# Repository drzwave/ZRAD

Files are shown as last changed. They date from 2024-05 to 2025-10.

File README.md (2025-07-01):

# ZRAD - Z-Wave Reference Application Design

Z-Wave USB Controller with best-in-class RF range Reference Application Design

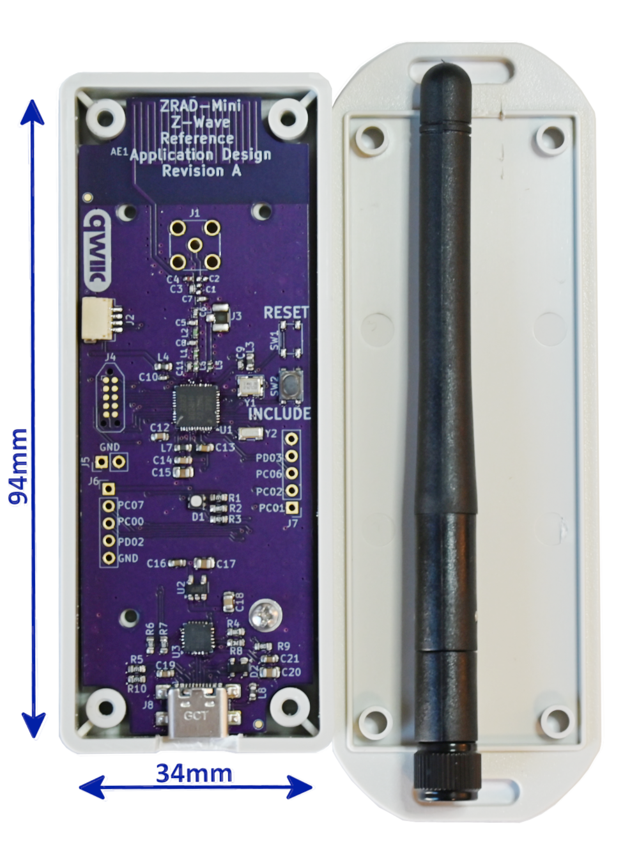
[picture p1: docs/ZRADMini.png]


The Z-Wave Alliance Z-Wave Reference Application Design (ZRAD) is a simple to copy, easy to modify, Open-Source _Reference_ design of a Z-Wave best-in-class RF range device. 
ZRAD is not a product you can purchase, but anyone is welcome to manufacture and sell a product based on ZRAD. 
The objective is to accelerate Time-To-Market for Z-Wave products thru a simple to follow example with detailed step-by-step instructions.  
See the [docs/ZRADTechDocs.docx](docs/ZRADTechDocs.docx) file for more details and the Theory of Operation.

# Setup - Simplicity Studio SSDK 2024.12.0 (Z-Wave 7.23.0)

This setup guide assumes a ZRAD or ZRADmini board has been assembled and is ready for programming.
ZRAD can be programmed as either a Controller or an End Device.
The challenge with Simplicity Studio (SSv5) is that since this is a "custom" board, many of the automatic features of SSv5 do not work.
Many aspects of the sample applications must be manually configured.

## Connect ZRAD to Simplicity Studio

1. Plug ZRAD into a WSTK via the Tag-Connect cable
    - ZRAD can be powered directly from the WSTK - ensure the slide switch next to the battery holder is set to AEM
    - Use a Tag-Connect [TC2050-CLIP](https://www.tag-connect.com/product/tc2050-clip-3pack-retaining-clip) retaining clip to hold the Tag-Connect securely to ZRAD
2. Plug the WSTK into a computer running Simplicity Studio
3. The WSTK should show up in the Debug Adapters pane of the Launcher Perspective
    - if not, click on detect target, if that still doesn't work, use Commander to identify the part
    - if that still doesn't work, check that the WSTK is set to OUT (or Mini) mode
4. Select the WSTK in the debug adapters pane 
    - SSv5 will then list the board as "custom" and Target Part as the ZG23
5. Your ZRAD board can now be programmed with firmware

## Controller

1. Download the SerialAPI using SSv5
    - The standard Demo SerialAPI pre-built for the RB4210 Radio Board will work for ZRAD as the pinouts are similar
        - Select xG23-RB4210A in the My Products pane of the Launcher perspective in SSv5
        - Click on Example Products & Demos Tab
        - Click on Z-Wave
        - Scroll down the list to the Z-Wave - NCP Serial API Controller (US or EU LR) 
        - Click on Run, select the WSTK and SSv5 will program the DUT
        - Note: the pre-built SerialAPI assumes a ZG23B, not ZG23A thus only download to a ZG23B
    - The Demo SerialAPI includes the bootloader
2. OR Build the SerialAPI (required if using a ZG23A or using your own keys)
    - TODO More details to come here...
    - TODO add how to build the serialAPI and add special features - what needs to be done to OTW??? keys???
3. Build the bootloader if also building the SerialAPI 
    - See [DrZWave.Blog](https://drzwave.blog/2024/04/02/how-to-build-the-z-wave-bootloaders) for details

## End Device

### Quick Demo 

The Switch On Off sample application in SSv5 will run out-of-the box on ZRAD as the pinouts are similar to the RB4210 devkit.
Follow these instructions to quickly test a new board.

1. In SSv5, in the Launcher perspective, enter "xG23-RB4210" in the lower left My Products pane, select that kit
2. Click on the Example Projects and Demos tab
3. Click on Z-Wave and uncheck Example Projects and Solution Examples
4. Click on RUN for the desired Demo application, Z-Wave SoC Switch On/Off (US or EU Region) has been tested
5. Choose the WSTK with ZRAD connected and click OK
6. The hex file will download and run. A bootloader is included in the sample application.
7. Right click on the WSTK in Debug Adapters
8. Device Configuration\-\>Z-Wave Device Settings will bring up the QR code and DSK
9. Use the QR code to join a network and write down the first 5 digits of the DSK which is the PIN
    - Press the LEARN button to send a NIF
11. Connect via the Console for other CLI functions (type "help" for a list of commands)
12. The LED will come on because the pins and polarity on ZRAD are different than the RB4210

### Full Feature Build

1. **Build the Bootloader**
    - In SSv5, select your board connected to a WSTK to make sure you are building for the proper chip
    - Click on Detect Target Part and verify the proper Target Part has been detected
    - File-\>New-\>Silicon Labs Project Wizard -\> next (make sure the IDE/Toolchain is V12.x.x or higher)
    - Filter on Z-Wave
    - Select "Bootloader - SoC Internal Storage (OTA for Z-Wave Applications)" - select it, click on Next and then Finish
    - Build & Flash the binary to the device
    - Copy the .HEX or .s37 file to another folder for merging with the app and keys later
    - Note that the Application will NOT start unless there is a bootloader programmed into the DUT
2. **Build the App**
3. Start with the Switch On/Off sample app - optionally use one of the others if applicable
4. File-\>New-\>Silicon Labs Project Wizard
5. Check that IDE/Toochain is set to GNU ARM v12.2.x (and not v10.x.x)
6. Check that the SDK is the latest
7. Next
8. Unselect Solution Examples
9. Select the Z-Wave checkbox
10. Select the Z-Wave SoC Switch On/Off project
11. Next
12. Change the project name to whatever you want
13. Finish - wait for the project to be created
14. **Generate the Keys**
    - Keys are needed to OTA the firmware - do NOT use the sample keys!
        - Keys are unique for each project for ALL revisions. Only generate the keys ONCE per project.
    - Create a folder called "keys" in the project
    - From the keys folder, run Commander:
        - ```commander gbl keygen --type ecc-p256 -o <projectname>_sign.key```
        - ```commander gbl keygen --type aes-ccm  -o <projectname>_encrypt.key```
    - Each unit must have the keys programmed in them using:
        - ```commander flash --tokengroup znet --tokenfile <projectname>_encrypt.key --tokenfile <projectname>_sign.key-tokens.txt --device EFR32ZG23```
        - Or combine the keys, bootloader and app into 1 file:
        - ```commander convert --tokengroup znet --tokenfile <projectname>_encrypt.key --tokenfile <projectname>_sign.key-tokens.txt <bootloaderfilename> <applicationfilename> -o <projectname>_merged.s37 --device EFR32ZG23```
    - Modify the Post Build Editor in SSv5 to use these new keys when creating the OTA file
        - Double click the \*.slpb file which will open the Post Build Editor
        - click on the create_gbl parameter
        - Click on the BROWSE button of the Signing Key, select the *_sign.key from above, then the Encrypt Key and select the *_encrypt.key file

        - To check the keys and Post Build is good, run:
        - ```commander gbl parse *.gbl --decrypt ../keys/<projectname>_encrypt.key --app temp.hex```
            - Should complete without error and copy the application to the temp.hex file
        - To check the keys work, program a unit with the app, keys and bootloader, then increment the version, build it again and OTA the incremented version
14. **Customize the Application**
15. Select the project in the Project Explorer of the Simplicity IDE perspective
16. Select the \*.slcp file
17. Select the Software Components tab
18. Scroll down to Z-Wave and open it (click on the triangle)
19. Click on Z-Wave Core Component gear icon
20. Change the RF Region to the desired value (ex:United States Long Range)
21. Click on the Z-Wave ZAF Component
    - Update the User Icon Type and Installer Icon Type for the specific product
        - See the Z-Wave Plus Assigned Icon Types document in the Z-Wave Alliance specification for details on choosing the proper icons
    - Update the Hardware version, Manufacturer ID, Product Type ID and Product ID
        - Each manufacturer is assigned an Manufacturer ID by the Z-Wave Alliance - search the ZW_classcmd.h for your company name
        - The ProductTypeID and ProductID are each 16 bits and MUST BE UNIQUE for each product within your company. These are the "fingerprint" that uniquely identifes the product. They must NOT change for the lifetime of the project thru all firmware revisions.
    - Update the device type & Multichannel configuration
    - Uncheck the Request S0 Network Key and S2 Unauthenticated network Key (these are obsolete and a security hazard)
    - Check the S2 Access Network Key if the product is a doorlock, garage door opener or other secure entry device
7. Click on Z-Wave Verion Numbers
    - Check the Override application version (TRUE=turns blue)
    - Enter the Application Major and Minor version. Note that the Minor and/or Major version MUST be incremented to OTA the firmware
7. Configure Buttons and LEDs:
    - The project will not build yet because LEDs/buttons are not setup for the sample application
    - Search for "simple" in the Software Components tab of the *.slcp file
    - Click on Platform-\>Driver-\>Button-\>Simple Button-\>btno0-\>Configure
        - General - Interrupt
        - SL_SIMPLE_BUTTON_BTN0 select PC03 and name it TOGGLE
    - Click on Platform-\>Driver-\>Button-\>Simple Button-\>btno1-\>Configure
        - General - Interrupt
        - SL_SIMPLE_BUTTON_BTN1 select PC05 and name it LEARN
    - Click on Platform-\>Driver-\>LED-\>Simple LED-\>led0-\>Configure
        - Active Low
        - SL_SIMPLE_LED_LED0 = PA00 and label it GREEN
    - Click on Platform-\>Driver-\>LED-\>Simple LED-\>led1-\>Configure
        - Active Low
        - SL_SIMPLE_LED_LED1 = PA10 and label it BLUE
    - TODO add LED2 PC04=RED
6. Build the project - it should build OK
    - Flash the DUT
    - Get the QR code or DSK and paste into the PC Controller
    - The DUT should join the Z-Wave network in a few seconds.
    - Send a BASIC ON and the BLUE LED should turn on
    - Send an Indicator SET which should blink the GREEN LED
    - Press the LEARN button which should send a NIF and the GREEN LED should blink
6. Optionally enable debugprint to get messages out the UART for debugging purposes
    - click on Z-Wave Debug Print
    - click on Install
    - SSv5 should also instal the IO Stream USART but sometimes it does not
        - manually install Services-\>IO Stream-\>IO Stream USART
        - Click on configure
        - Choose USART0, Tx=PA08, RX=PA09
        - Build the project
        - If the build fails because USART is undefined, click on Configure in IO Stream USART
        - Click on View Source
            - if #warning "IO Stream USART peripheral is not configured" is at about line 90, then SSv5 didn't properly configure the USART
            - comment out the #warning line, then manually set the next several lines with the proper GPIO vlues (they are pretty obvious).
    - Edit app.c and uncomment the line: #define DEBUGPRINT
9. Note that the Secure Element firmware version MUST be the same as the SDK version the app and bootloader were built with. Ensure you have the proper version when programming production devices.
10. TODO
    - What other stuff should every project update???
    - Default_handler - could write an entire blog post on what it should include
    - 24hr watchdog timer - reboot if no traffic
    - watchdog timer
    - memset/clr optimization?
    - Turn on the iCache?
    - add other command classes
    - SPI?
    - Red LED

## Zniffer

ZRADMini makes a great Zniffer for debugging Z-Wave networking issues. 

1. Connect ZRADMini to a WSTK using the Tag-Connect connector
2. Open Simplicity Studio
3. From the Launcher perspective, in the My Products tab, enter the xG23-RB4210A
    - The RB4210A is a +20dBm devkit using a ZG23B and is pinout compatible with ZRADmini
    - Much easier to simply download the pre-built Zniffer application than trying to configure it for ZRAD
4. Click on the Example Projects tab and select Z-Wave
5. Filter on "zniffer" and choose only Demos
6. Pick the desired Z-Wave - NCP Zniffer Beta (EU\_LR or US\_LR regions) and click on RUN
7. Choose the proper WSTK to program the ZRADMini
8. Unplug from the WSTK and plug into USB
9. Zniffer should detect ZRADMini as a zniffer

# Troubleshooting

- Firmware doesn't seem to start? Did you flash the bootloader? The app won't start without a bootloader.
- If your ZRAD is not able to be detected using SSv5 or commander:
    - Check the ZG23 for solder shorts/opens and check the power supplies
    - Is the WSTK in Out or Mini mode and the slide switch set to AEM?
    - Can Commander detect the part? Simplicity Studio sometimes is unable to detect the part but Commander can and will help debug the issue
    - Is the debug interface locked? Use Commander to Unlock Debug Access or Recover Bricked Device
- If the DUT does not seem to generate any RF traffic, the problem is often due to the wrong Region stored in NVM (IE: EU when you want USLR).
    - To reset the Region token: ```commander flash --tokengroup znet --token MFG_ZWAVE_COUNTRY_FREQ:0xFF -d EFR32ZG23```
    - Note: the token in NVM will override the value set in the firmware so downloading firmware may not fix the problem
- OTA fails with a 0x04 error (someday Silabs will eventually separate this out into more errors)
    - Usually caused by the keys not being programmed into the DUT

# QWIIC Connector Setup

The QWIIC connector on ZRAD makes it easy to connect any of the [Sparkfun](https://www.sparkfun.com/qwiic) sensors or other devices via a standard I2C interface. 
Fortunately SSv5 has the I2CSPM component which makes adding and interfacing to I2C devices fairly easy.
The QWIIC connector is normally only used when implementing ZRAD as an End Device.

## I2CSPM Setup

While I2CSPM seems to work, since it is a polled peripheral which loads the CPU with polling loops which can make other parts of the system fail. Thus, this driver is not recommended but works fine for prototypes.

1. Click on the .slcp file - select the Software Components tab - enter I2CSPM into the seach bar
2. Click on Platform-\>Driver-\>I2C-\>I2CSPM and Install it
3. Name the component QWIIC
4. Click on Configure
5. Reference clock frequency=0 (default), Speed mode=Fast mode (400kbit/s), Selected Module=I2C0 (or I2C1), SCL=PB00, SDA=PB02
    - Sometimes SSv5 does not properly configure the GPIOs - click on Source
    - Comment out the #warning
    - Uncomment the QWIIC\_PERIPHERAL to be I2C0 (or I2C1)
    - Uncomment the PORT and PIN lines and set them to the correct GPIOs for both SCL and SDA
6. The project should build OK - the I2C peripheral will be automatically initialized
7. The I2CSPM\_Transfer() function is then used to send/receive data over the I2C bus
8. See the Geographic Location Command Class repo for an example using the QWIIC connector

# Railtest

RailTest is required for calibrating the 39MHz crystal on the ZRAD PCB. 
The Z-Wave radio will work fine without calibrating the crystal but MUST be calibrated before measuring the RF range.
The crystal on each ZRAD unit must be individually calibrated within 1ppm to achieve maximum RF range over the lifetime of the board.

## Build Railtest

1. The easiest method is to select a ZG23 Radio board DevKit in the MyProducts in the Launcher persepctive
    - ZRAD uses the same UART IOs as the devkits thus the simple method to build railtest is to use one
    - In the "Enter product name" box, enter "RB4210"
2. In the Example Projects & Demos tab, enter "railtest" in the "Filter on Keywords" box
2. Select the "RAIL - SoC Railtest" project
3. Click on Create
4. Build the project
5. Download the .s37 file to the target
6. Connect via USB using PuTTY, Minicom or other terminal project at 115200 baud
7. Type "help" and the full railtest menu should print out
8. Type "getversion" to see the current version of Rail

# Crystal Calibration

1.	Download RailTest into the DUT
2.	Rx 0
3.	Setzwavemode 1 3
4.	Setzwaveregion 1
5.	Setchannel 2
6.	Settxtone 1 - turns on the radio carrier
7.	Getctune - record the CTUNEXIANA value in hex
8.	Use a spectrum analyzer like the TinySA Ultra with start=908.3 stop=908.6
9.	Measure the peak which the TinySA should display - goal is to be within 1ppm of 908.420MHz (1000Hz)
10.	If the peak is high, set ctune to be a higher value, if low, try a lower value
11.	Settxtone 0
12.	Rx 0
13.	Setctune 0xTTT
14.	Settxtone 1
15.	Measure the peak - go back to step 11 until within 1000Hz (1ppm)

Once the value has been determined, use the following command to program the value:

```commander ctune set --value <ctunevalue> -d EFR32ZG23```

```commander ctune get -d EFR32ZG23``` will return the three ctune values. The "Token" ctune is on-chip one in NVM which is erased if the User Data Page is erased. The DI value is programmed at the Silabs factory in the Data Information page for modules. The Board value is used for Silabs radio boards and thus not applicable for customer boards. 

Note that railtest does NOT program the value in NVM. Railtest will only TEMPORARILY assign the CTUNE value. Commander must be used to program the value permanently.

# Schematic to PCB process

KiCAD is used for the schematic and PCB design. The hardware/ZRAD directory contains the KiCAD database. A PDF of the schematic and PCB are provided for easy review. The Gerbers (used for fabricating PCBs) are in a ZIP file in the gerbers folder. The process to go from the schematic to a fabricated PCB is listed here:

1. Open the Schematic file (ZRAD.kicad_sch) in KiCAD
2. Make any changes to the schematic as desired and run the Electrical Rules Check
3. Save the schematic file - File-\>save
4. File-\>Export-\>netlist - click on Export Netlist and save file to ZRAD&#46;NET
5. Open the Board file (ZRAD.kicad_pcb)
6. Update the board from the schematic - Tools-\>Update PCB from Schematic - click on Update PCB
7. Make any changes to the PCB desired
8. Inspect-\>Design Rules Checker - Click on Run DRC
9. Make sure DRC is clean!
10. Generate the Gerbers and documentation files:
11. File-\>Fabrication Outputs-\>Gerbers - click on PLOT, then Generate Drill Files 
    - All the selected layers will be saved in the chosen folder
12. File-\>Fabrication Outputs-\>Component Placement - click on Generate Position File
13. Delete the ZRAD-bottom.pos file as there are no bottom side components
14. There should be a total of 10 files (12 for a 4 layer board) - add these to a compressed ZIP file and name it ZRAD.zip
15. Delete the gerber files and just keep the ZIP file
16. Review the gerbers using one of the many gerber viewer programs 
    - Check that there is solder mask between the pins of the ZG23 and CP2102
    - if not, check the Board Setup-\>Board Stackup-\>Solder Make/Paste-\>Solder mask expansion is set to 0.0508mm (not zero)
    - Note that 0 leaves it up to the PCB manufacturer who often will use a 3mm expansion which will results in all the pads being shorted to each other as there is no mask between the pads 
17. Plot the schematic - File-\>Plot plot to PDF and save as ZRAD.pdf
18. Print the Fab drawing from the board editor - File-\>Print save landscape fit-to-page as ZRAD_FabricationDwg.pdf
    - Select layers F.Silkscreen, F.Mask, User.Comments, Edge.Cuts and print in black and white
19. Order PCBS!
    - OSHPark.com is recommended - Use the gerbers and NOT the KiCAD files as the gerbers will give you exactly what is plotted, the PCB house may use other defaults for various clearances which might cause problems
    - May 2024 cost $233 for 3 4-layer ZRAD boards
    - July 2025 cost $24.75 for 3 2-layer ZRADTri boards
20. Order a Stencil using the ZRAD-F_Paste.gtp file

Order components from the BOM for the needed quantity. Once everything arrives, use the stencil to swipe a layer of solder paste onto the PCBs, place the components by hand, then bake in an IR oven, clean up any solder issues. PCBs are now ready to test!

# Directory Structure

- 3D - mechanical drawings for jigs and enclosures
- docs - documentation folder
    - Datasheet
    - Technical reference manual and theory of operation
- hardware - PCB board design, bill of materials, Gerbers, KiCAD schematic and layout
- sofware - various hex files for quick testing purposes
- Test - Documents and scripts for testing

# Reference Documents

- See the [docs/ZRADTechDocs.docx](docs/ZRADTechDocs.docx) for detailed technical information on this project
- [EFR32ZG23](https://www.silabs.com/documents/public/data-sheets/efr32zg23-datasheet.pdf) Datasheet - features and electrical specification
- [EFR32xG23](https://www.silabs.com/documents/public/reference-manuals/efr32xg23-rm.pdf) Reference Manual - peripherals details

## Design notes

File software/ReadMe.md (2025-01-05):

# ZRAD Software folder

See the top level ReadMe.md for step by step instructions on building firmware for ZRAD.

The Application must be named ZRAD\_ED.s37 for the Test scripts to function properly.
The sample manufacturing flow in the ../Test folder uses the files in this folder to program into each DUT

# KEYS - MAKE YOUR OWN!

Over-The-Air (OTA) firmware updates REQUIRE keys to be programmed into each DUT and MUST be used when building the firmware and generating the gbl file.

The keys pre-built in this folder are SAMPLE KEYS and MUST NOT BE USED on derivative projects! You MUST create your own unique keys for your own products!

## Generating Keys:

1. Run the following commander commands:
2. `commander gbl keygen --type ecc-p256 -o ZRAD_sign.key`
2. `commander gbl keygen --type aes-ccm  -o ZRAD_encrypt.key`

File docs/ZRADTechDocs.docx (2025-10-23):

# ZRAD Z-Wave Reference Application Design

# Introduction

The Z-Wave Alliance Z-Wave Reference Application Design (ZRAD) is a simple to copy, easy to modify, Open-Source Reference design of a Z-Wave best-in-class RF range device. ZRAD is not a product you can purchase, but anyone is welcome to manufacture and sell a product based on ZRAD. The objective is to accelerate Time-To-Market for Z-Wave products thru a simple to follow example with detailed step-by-step instructions.

See the README.md (https://github.com/drzwave/ZRAD/blob/main/README.md) file in the repo for the latest information on building and using ZRAD.

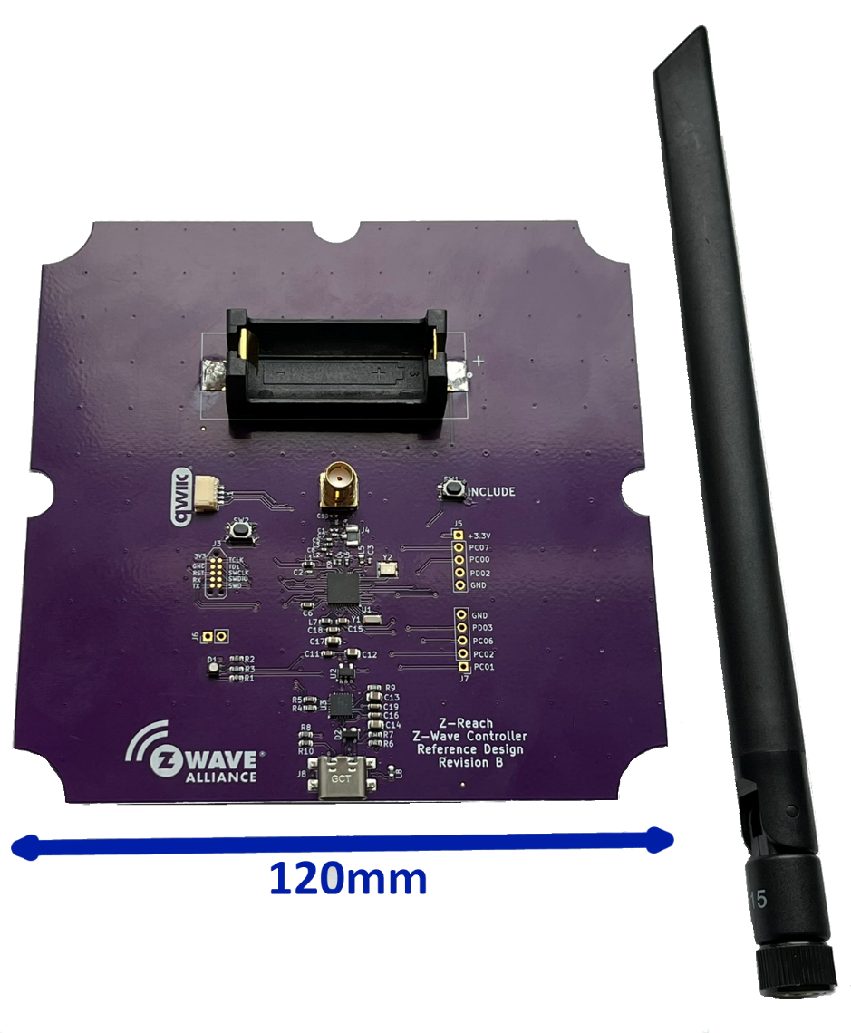
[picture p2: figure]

## Features

- Public GitHub repository
  - Open-Source Repository
  - MIT License
- KiCAD schematic & PCB layout
  - Easily imported into other tools like Altium
  - Gerbers for immediate production
- EFR32ZG23 based +20dBm
  - 512K FLASH, 64K RAM
  - ARM CM33 CPU 39MHz
  - UARTs, Timers, I2C, ADC, DAC
- CP2102N USB->UART host interface
- Standard SerialAPI Firmware
- Documentation with full details for customization and replication
- Battery powered End Device option
- Target Assembled/tested kit cost less than $50@10K (not including enclosure)
- Target BOM cost under $15@10K
- White Paper on Z-Wave Antenna Best Practices and RF range field test results

# Theory of Operation

## Z-Wave MCU

Naturally the heart of ZRAD is the Silicon Labs EFR32ZG23 SoC. The ZG23 has an ARM CM33 CPU, a long list of standard peripherals and the Z-Wave radio. The ZGM230 module is limited to +14dBm (or half the RF range) compared to the SoC at +20dBm. The SoC requires tuning the 39MHz crystal on every unit produced but this is easily done in a few seconds on the production line. The procedure for tuning is described below and scripts are available in the Repo.

The UART Rx/Tx pins are connected to the CP2102 thru 100 ohm resistors to allow the Tag-Connect debug cable to drive the pins during manufacturing. RailTest is needed to send/receive UART commands during crystal calibration. While this does not provide complete isolation between the CP2102 and the debug connector, the debug connector is typically only connected for a few seconds during final test making this a viable low-cost solution.

A Tag-Connect 10 pin header with alignment pins is used for programming and test during production and debug. Two Trace pins are wired to the header to enable Trace debugging using the adaptor board in the etm_zwave (https://github.com/drzwave/etm_zwave) repo. The PTI pins are not wired as Z-Wave typically uses a separate standalone Zniffer. The 2 ground pins are often needed for Trace debugging to improve signal integrity across the 10 pin ribbon cable.

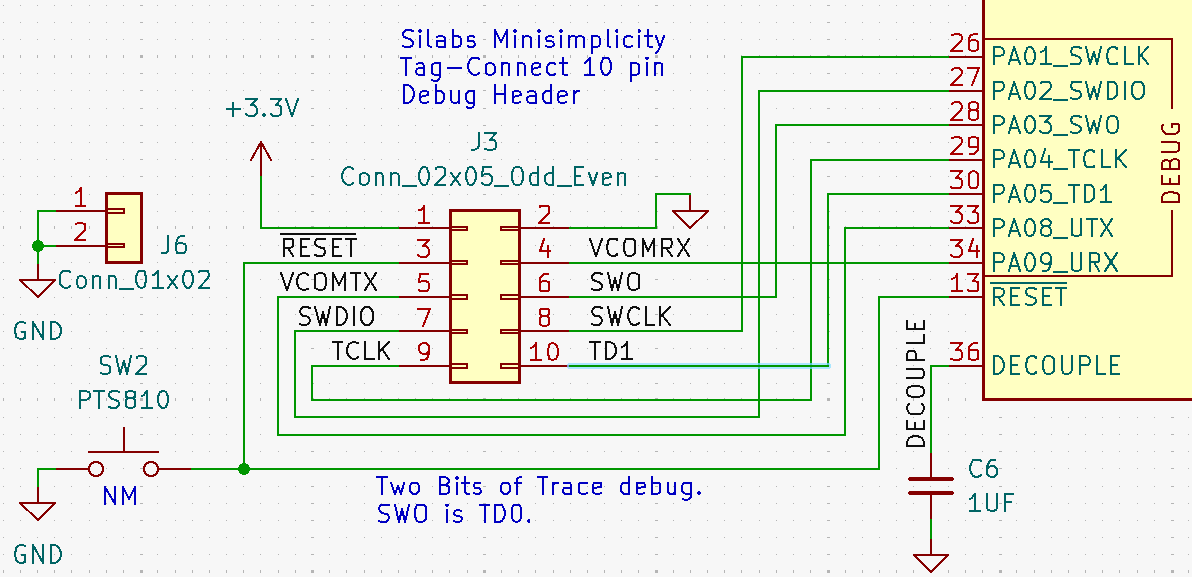
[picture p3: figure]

The ZG23 DCDC switching power supply is utilized to convert the 3.3V to 1.8V for the VDD power supply. The USB 5.0VDC is passed thru a linear LDO to drop the supply voltage to 3.3V. Power spikes of about 130mA occur when the radio transmits at +20dBm. The LDO and USB handle that sudden change in supply current ensuring good RF range. The PAVDD is powered with 3.3V to power the RF amplifier to +20dBm. The analog supply and IOVDD are on the 3.3V to provide better analog voltage range and connectivity with other external devices. The internals of the ZG23 are powered with 1.8V. Sensitive power supplies have additional ferrite beads and capacitors to ensure clean supply voltages.

## Antenna Filter and Match

The RF path from the ZG23 to the RF50 signal is straight from the Silabs DevKit reference designs (xG23-RB4210A (https://www.silabs.com/documents/public/user-guides/ug507-brd4210a-user-guide.pdf)). This path filters the RF and shifts the high impedance pins to be close to 50 ohms. Between the matching circuit and the SMA connector is a standard 3 element pi filter used to match the impedance of the antenna. The values for these 3 elements are typically tuned to a specific antenna and RF region. A U.FL footprint is in this path to make tuning easier via a U.FL cable to a network analyzer. The U.FL is only mounted to bare PCBs to help with tuning. Thus, it is listed as “NM” in the schematic and is why there is a red X thru it. The SubGx1 pins are not used. The PCB antenna used on ZRADMini was inspired from the EFR32ZG14 Radio board BRD4206A (https://www.silabs.com/documents/public/reference-manuals/brd4206a-rm.pdf). However, the shape was altered to fit the available space.

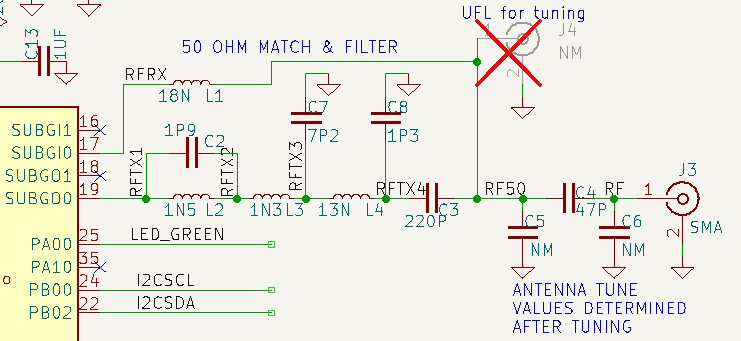
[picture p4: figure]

## USB-C Interface

A Silicon Labs CP2102N USB to UART chip is used to connect the SerialAPI to the host computer. A USB-C connector is used but only USB 2.0 is supported. USB3 is not supported or needed as the data rate of the UART is 115200 baud. The design follows the reference example in the CP2012 datasheet. This article (https://hackaday.com/2023/08/07/all-about-usb-c-example-circuits/) was used as a guide. A CP2105 dual UART is pinout compatible and might be used in a future release to include support for Zniffer via PTI. Pin 12 of the CP2105 is wired to the PD04 pin of the ZG23 which can be used for 9-bit data mode of the PTI component.

## Power Supplies

USB-C provides +5V power in the typical application of a controller. The +5V is reduced to 3.3V via an LDO to power the on-chip switching regulator on the ZG23. The radio is powered from +3.3V to achieve a transmit power of +20dBm to the PAVDD pin.

When prototyping a low-power end device, the battery holder can be populated and connected to a CR123A or similar 3V battery. No reverse battery protection is provided so the battery holder must ensure the polarization. The LDO and USB devices are not populated when developing a battery powered device.

## PCB Ground Plane

A very important part of an IoT radio is the ground plane. Ideally the ground plane is perpendicular to the antenna and is half-wavelength. At 868MHz the wavelength is 34.5cm and 920Mhz is 32.6cm. The exact dimension isn’t that critical as long as it’s close. The ½ wavelength is 17cm but a square is more cost effective than a disk, thus divide by the diagonal (1.41) to get a 12cm on a side or roughly 5” square PCB. The ground plane fills the entire bottom side of the PCB to ensure there are no eddy currents or blockages. The next layer is used to distribute power. The upper two layers are used for interconnection of the ICs. All layers are flood-filled with ground as much of the area is open to provide a large ground plane for ideal RF performance. A smaller PCB size can be easily prototyped by simply making the PCB smaller with the potential of a loss in RF performance.

A related calculation is the width of the infeed trace. The width of the infeed trace is calculated using one of the many coplanar waveguide calculators such as: https://chemandy.com/calculators/coplanar-waveguide-with-ground-calculator.htm.

For OSHPark (https://docs.oshpark.com/services/four-layer/), the relative dielectric constant is 3.61. The thickness of the prepreg is .2021mm. Usually the gap is set to .3mm then try various widths until the calculator comes up with close to 50 ohms. For ZRAD using OSHPark for PCBs, the calculated width is .44mm. Most of the infeed trace is 0.44mm except where it needs to narrow to reach the pins of the ZG23.

## RGB Color LED

An RGB Color LED can be used to provide visual status of any sort. Utilizing this LED requires customizing the SerialAPI. The LED can be used when ZRAD is used as an end-device for Indicator CC support. The LED is Active Low meaning the LED is ON when the pin is a zero (0V). The LEDs are driven directly from the GPIOs without extra FETs to keep costs low. This limits the brightness of the LEDs but they are sufficiently bright for most applications.

- Red = PC04 (LED3_GPIO)
- Green = PA00 (LED1_GPIO)
- Blue = PA10 (LED2_GPIO)

The pins can be assigned using the Z-Wave Target Boards component in Simplicity Studio. Open the .SLCP file and select the Software Components tab. Scroll down to the Z-Wave Target Boards component and click on the gear icon. Assign the pin as shown above. The standard Switch On Off sample app will then control the green LED as the state of the switch and the blue LED will blink when in Learn mode or via Indicator CC. If SSv5 is not properly setting the configuration, see the README.MD file for the latest workaround.

## Learn Mode Switch

PC05 is connected to a SPST momentary pushbutton switch. This pin is an EM4WU pin so it can wake the chip from EM4. End Devices use this pin to enter Classic Inclusion/exclusion mode. Press and hold for more than 5 seconds to factory reset ZRAD. Controller applications do not populate this switch.

## I2C via QWIIC connector

Tons of handy and cheap I2C devices from Sparkfun use the tiny 4 pin QWIIC connector. There are sensors of every type, various displays, and GPS receivers. To add I2C to the ZRAD, install the Platform->Driver->I2C->I2CSPM component. Configure it with: Leave the Reference clock frequency at 0, Speed Mode=Fast Mode (400kbits/s), Selected Module=I2C0 (or I2C1), SCL=PB00, SDA=PB02. Reference clock frequency of 0 sets the reference frequency to the same as the I2C peripheral clock which is usually the HF clock (39MHz) (based on following the code). Once configured, the pins should show up in the PinTool. sl_system_init() calls sl_driver_init() calls sl_i2cspm_init_instances() which then configures the I2C block on startup. The only function is the I2CSPM_Transfer (https://docs.silabs.com/mcu/5.9/efr32mg13/group-I2CSPM)(). The Z-Wave Multilevel Sensor sample app uses the I2CSPM which can be used as an example to see how it works.

## DEBUGPRINT

DEBUGPRINT can be defined and used to print messages via the MiniSimplicity headers VCOM pins. Typically, the USART is used for this purpose. First install the Services->IO Stream: USART component. Configure for 115200 baud, USART0, RTS/CTS=none, Rx=PA09, Tx=PA08. Then install Z-Wave-> Debug Print and uncomment the #define DEBUGPRINT in app.c or as a compiler symbol which will enable all printfs in every file.

## Optional Connections

Extra connections are incorporated in the design to allow prototyping of many other types of Z-Wave devices. These connectors and devices are normally NOT mounted for SerialAPI applications.

- 32KHz crystal supports Time CC. The on-chip low-speed oscillator drifts by a few minutes per day making it not usable for schedules or other time-of-day uses. The crystal reduces drift to a few seconds per day.
- Two 5 pin GPIO headers provide generic connections to other devices
- SW2 is an optional switch connected to RESET which is handy when debugging End Devices

## Crystal Calibration

See the README.md file and scroll down to the Crystal Calibration section for the procedure to calibrate the 39MHz crystal. Calibration is unique to each unit and must be performed during final test. Calibration is required for maximum RF range across environmental conditions and aging.

# Programming and Testing

The Test folder has Python scripts for programming, calibrating, and testing ZRADMini using the jig in the 3D folder, a Silabs WSTK ProKit, TinySA spectrum analyzer and a PC or raspberry pi. See the Test/ReadMe.md file for more details.

# Fabrication

ZRAD is a reference design and not a commercial product though it is intended to be copied and possibly sold as one. The procedure below documents the process to build prototype quantities. This is an example process and each manufacturer may have slightly different requirements. The process below is for ZRADmini. Open KiCAD and ensure the schematic is ERC clean and the PCB is DRC clean. ZRADmini has a few Exclusions to the ERC/DRC which can be ignored.

## PCB Files – Gerber Generation from KiCAD

1. Open the Schematic and PCB in KiCAD (version 8.0.4 or later)
2. Print the Schematic as a PDF and save as ZRADminiSchematic.pdf
3. Make ONLY the following layers visible: F.Silkscreen, User.Comments (contains all the PCB fabrication details), Edge.Cuts, F.Paste
  a. Turn off VIAs in the Objects tab
  b. Print, black and white, fit-to-page, save to ZRADminiFabrication.pdf

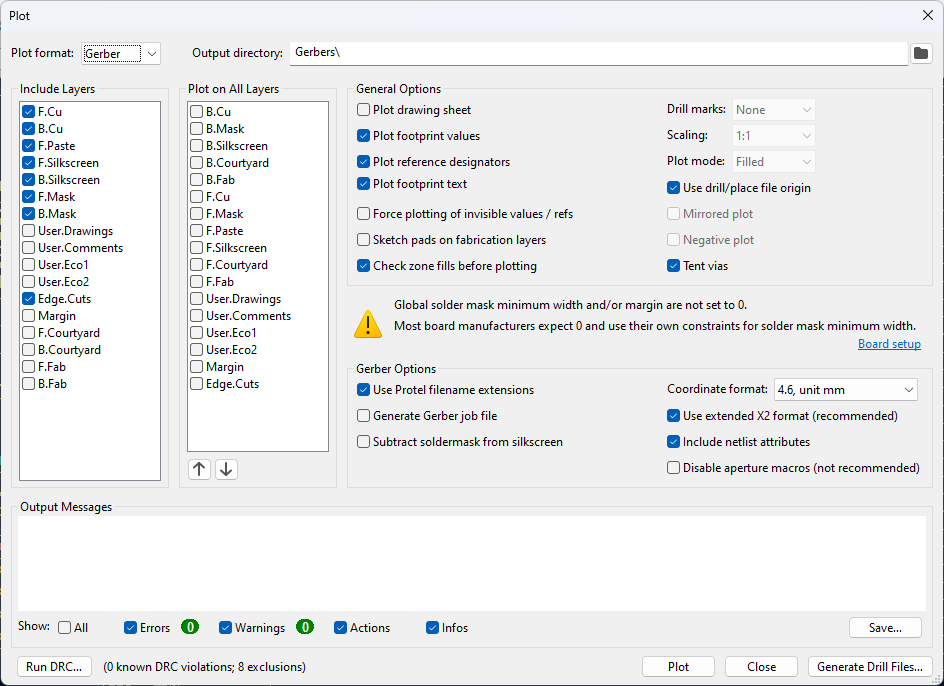
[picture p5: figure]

4. File->Fabrication Outputs->Gerbers
5. Click on “Plot” as shown here
6. Then click on Generate Drill Files and then Generate Drill File (use defaults). This will create the *.drl file.
7. Generate the Positions file for pick-and place assembly (*.pos): File->Fabrication Outputs->Generate Placement Files->Generate Positions file
8. Delete the delete the *-bottom.pos file as there are no components on the bottom of the ZRADmini.
9. ZIP up the 10 files (*.drl, *.gbl, *.gbs, *.gbo, *.gm1, *.gtl, *.gts, *.gtp, *.gto, *.pos). The files are described in the notes on the Fabrication drawing.
10. Delete all the files except for the ZIP file
11. Open the ZIP file in gerber viewer (a tool inside KiCAD) and verify everything looks OK
  a. Check for any odd looking traces or anything that might be a problem in manufacturing
  b. Look closely at the .GTS (top solder mask) and ensure the ZG23 pads have solder mask between them and that it is NOT exactly the same size as the pad. Some PCB manufactures treat mask=pad (zero) to be “use default clearance” which can be as much as 3mm which would cause all the pads to short together. Set 0.0508mm as the Solder mask expansion in KiCAD. Make sure are no isolated ground pours and plenty of GND vias between layers
12. To purchase prototype PCBs:
13. Upload the gerbers zip file to OSHpark.com or other prototype PCB shop. Select the desired number of boards. Purchase the stencil which is a 3mil mylar (5mil is too thick – maybe the 5 mil is better?). Consider ordering the steel stencil as it likely will result in less chances for solder shorts but is twice the cost. Do NOT use the kicad files with OSHpark as they will regenerate the solder mask tolerances making the pads for the ZG23 short together.
14. Order components from the BOM. Export as a .csv file and Digikey can input the file to create a complete kit of components.
15. When everything arrives, place the stencil over the PCB, swipe a THIN layer of solder paste over the pads, Place the components using a microscope, bake the board in an IR oven, inspect the board looking for shorts/opens and repair them then you are ready to test your new ZRADmini!

## QR Code Generation

Each Z-Wave device MUST have a unique QR code affixed to the device itself and one on the outside of the packaging. This is a certification requirement. During manufacturing, each device must have the token *MFG_TOKEN_ZWAVE_QR_CODE read out and then converted into a QR code. There is a python script in the Test directory which will generate the QR code. Z-Wave-JS has a great utility (https://zwave-js.github.io/qr/) for generating, modifying, and checking the QR code.

# Regulatory Preparation

Z-Wave products typically require regulatory approval thru appropriate test facilities. The regulatory bodies are FCC in the US, ISED in Canada, CE for Europe and others. Typically test houses want a device that will simply power up and turn the radio on in various modes. More details are in UG523 (https://www.silabs.com/documents/public/user-guides/ug523-bring-up_test-hw-development.pdf) and UG409 (https://www.silabs.com/documents/public/user-guides/ug409-railtest-users-guide.pdf). For Silicon Labs devices, the firmware required is called RailTest. Simplicity Studio has a project called RAIL – SoC RAILtest which must be customized for ZRAD. Follow the steps below to create a usable railtest firmware. Note that railtest is a standalone program that does not need a bootloader and overwrites NVM so the DSK is typically lost when railtest is flashed into a device.

1. Plug in a Silabs devkit or select one in the My Products pane of the Launcher perspective (xG23-RB4210)
  a. This will automatically set the pinouts to match ZRAD – primarily for the UART
2. Create the RAILtest project – RAIL-SoC RAILtest
3. Double click on the .slcp file
4. Click on the Software Components tab
5. Enter NVM3 in the Search window
6. Scroll down to: Services->Command Line Interface->Extensions->CLI:Storage in NVM3
7. Install it and be certain to name the component “inst0”
8. Build the project and flash it to the DUT
9. Open a serial port to the USB port
  a. or using SSv5 right click on the WSTK and select Launch Console
  b. Then click on the Serial 2 tab, then press ENTER in the window at the bottom
10. getversion will return the current version of railtest
11. Can also enter HELP for a list of all railtest commands

Below are specific details on the important railtest commands for Z-Wave.

Railtest command | Results | Comments
rx 0 | {{(rx)}{Rx:Disabled}{Idle:Enabled}{Time:240676874}} | Turns off the radio – required before changing radio configuration
setzwavemode 1 3 | {{(setzwavemode)}{ZWAVE:Enabled} {Promiscuous:Enabled}{BeamDetect:Enabled}{PromiscuousBeam:Disabled}} | Configures Railtest for Z-Wave mode
setzwaveregion 1 | {{(setzwaveregion)}{ZWaveRegion:US-United States} {ZWaveRegionIndex:1}} | US mesh Ch0=916.0 100kbps GFSK Ch1=908.40 40kbps FSK Ch2=908.42 9.6kbps FSK
setzwaveregion 11 | {{(setzwaveregion)} {ZWaveRegion:USLR1-United States, Long Range 1}{ZWaveRegionIndex:11}} | US Long Range Channel A (DSSS) Ch 3=912.0 100kbps OQPSK
setzwaveregion 12 | {{(setzwaveregion)} {ZWaveRegion:USLR2-United States, Long Range 2}{ZWaveRegionIndex:12}} | US Long Range Channel B (DSSS) Ch3=920.0 100kbps OQPSK
Setchannel 0-3 | {{(setchannel)}{channel:3}} | Set the frequency based on region
Setpower xxx [raw] | {{(setpower)}{powerLevel:240}{power:210}} | Set transmit power XXX = deci-dBm (140=14.0dBm) RAW changes to “raw power level” instead of deci-dBm
settxtone 0 or 1 | {(settxtone)}{Stream:Enabled}{None:Disabled} {StreamMode:Tone}{Time:1251689899}} | Carrier On (1) or Off (0)
settxstream 0 or 1 | {{(settxstream)}{Stream:Enabled}{None:Disabled} {StreamMode:PN9}{Time:3481955496}} | PN9 modulated On (1) or Off (0)
clearscript 1 | | Removes the script in FLASH
enterscript 1 | | Begin capturing script commands and store to FLASH The script is automatically run on powerup
Endscript | | End of the script
Printscript | | Print the script
Runscript | | Runs the script for testing purposes

Sample commands to for a 908.40 MHz carrier that turns on when powered up:

clearscript 1

enterscript 1

rx 0

setzwavemode 1 3

setzwaveregion 1

setchannel 0

settxtone 1

endscript

For Z-Wave Mesh the maximum transmit power must be determined using the procedure in the Z-Wave 700: Tx Power Calibration (https://community.silabs.com/s/article/z-wave-700-tx-power-calibration-adjustment-in-railtest-and-application-fw-x) or in this KBA (https://community.silabs.com/s/article/z-wave-700-how-to-adjust-tx-power-on-slave-devices?language=en_US). Z-Wave Long Range uses dynamic power and the regulations allow up to +30dBm of transmit power but the Z-Wave chips can transmit at a maximum of +20dBm. Thus, ZWLR max power typically does not need to be set and can remain at the default of 200 (+20dBm).

# Board Status:

Rev A: 2 boards scrapped – USB chip difficult to solder due to pads under the IC.

Rev B:

- 1: ZG23A, SE=2.2.4, CTune=0x87
  - 13013-20757-03685-13998-02429-19075-02920-54669
- 2: ZG23A, SE=2.2.4, CTune=0x89, SerialAPI (no DSK)
- 3: ZG23B, SE=2.2.4, Ctune=0x98 – shipped to David Zima 4/19/2024 with Railtest
- 4: ZG23B, SE=2.2.4, Ctune=0x95 – works ok as an ED – Has a CR123A battery holder & reset button
  - 16512-58082-50459-58629-17292-55749-28421-30309
  - CP2102 isn’t connecting via USB
  - Suspect a short under the USB connector on one of the data pins
- 5: ZG23B, SE=2.2.4, Ctune=0x99
  - 54817-13409-17164-25837-27750-16443-46416-26908
- 6-12: bare boards

Rev C:

- 1: ZG23B, SE 2.2.4, CTune=0x94
  - 12041-60201-44764-43614-63900-49745-32509-52297
- 2: ZG23B, SE 2.2.4, Ctune=0x98
  - 31350-48981-20595-45123-33910-07500-29843-63102
- 3: Bare

ZRADMini Rev A:

# | MCU | Antenna | CTUNE | Status | PIN | Comments

1 | ZG23B020 | PCB untuned C3=47pF | No | Working
2 | ZG23B020 | SMA top side (wrong) | No | Working | | Zniffer
3 | ZG23B020 | SMA | Y 140 | End Device Only | 19084 | CP2102 not working so no USB data 2.7KHz buzzer in series with 150 ohm to PD02 drive low. 19084-42229-08667-37183-61077-35835-59006-34620
4 | ZG23B020 | PCB US tuned | Yes | Working | 09433 | GeoLoc 0943346518402772930534843606660714350274
5 | ZG23B020 | PCB EU tuned | Yes | Working | | Gave to somebody
6 | ZG23B020 | SMA | Yes | Working | | SerialAPI
7-9 | | | | Bare boards, 1 used for tuning

ZRADTri Rev A: Trident PCB – limited RF range due to schematic error

# | MCU | Antenna | CTUNE | Status | PIN | Comments

1 | CZ20 | SMA | No | Limited RF Range | 28063
2 | CZ20 | SMA | No | Limited RF Range | 49815
3 | CZ20 | SMA | No | Limited RF Range | SerialAPI | Shipped to Trident
4 | CZ20 | SMA | No | Limited RF Range | | Shipped to Trident
5 | CZ20 | SMA | No | Limited RF Range | 18709 | Shipped to Trident

ZRADTri Rev B: Trident PCB

# | MCU | Antenna | CTUNE | Status | PIN | Comments

1 | CZ20 | SMA | No | Working | 24181
2 | CZ20 | SMA | No | Working | 22226 | Shipped to Trident 8/5/2025
3 | CZ20
4 | CZ20
5 | CZ20
6 | | | | | | Bare PCB

# Reference Documents

1. EFR32ZG23 Datasheet
2. EFR32xG23 reference manual – details of all peripherals & registers
3. ZRAD Github repository
  a. See docs directory for this document and the Z-Reach datasheet
4. CP2102N (https://www.silabs.com/documents/public/data-sheets/cp2102n-datasheet.pdf) Datasheet

# Issues/Learning:

1. Place the Tag-Connect on a 1mm grid and if possible 5mm in from the edge of the PCB
  a. Easier to match the location on a test jig if its on a broad grid
2. Screw in Antennas RF quality is not consistent with price
  a. Cheap antennas can be better than expensive ones

# Document History

DATE | Who | Description
6/12/2024 | ER | Initial release
12/28/2024 | ER | Project officially complete per SOW with Z-Wave Alliance but as an open source project efforts continue

# Journal

Details of the development and timeline are described here in reverse chronological order.

## 2025-10-20 – Prep for Z-Wave Summit

The 2 ZRADMinis with GPS attached had their Learn buttons enhanced with a piece of plastic cut from a spare enclosure then taped to the inside. I had destroyed one of the pushbuttons because the button is so small. Poking a paperclip in eventually trashed the button which I replaced. The plastic protects the switch and makes it easier to poke. It is still tough to tell if the button has been pressed but the green LED will blink when it is. Since these 2 units are likely to be learned in and out at unplugfest, it is important that the buttons work reliably. Long term it would be better to use a switch with the post that nearly reaches out of the case or 3D print actual buttons (though they are very small).

## 2025-09-29 – Z-Wave SDK 7.23 and 7.24 have a bug when TxPower is negative

There is a bug in the SDK that incorrectly sets the TxPower. When the dynamic power algorithm sets TxPower=-6dBm (minus 6dBm), the current measured in the AEM on a ZG23 +14dBm board with the SerialAPI 7.24 2025.6.2 is 37.97mA. The easy way to see the frame is to use a basic SET/Get command in the PCC and add a bunch of zeroes to make the frame last longer so the AEM will accurately capture the current. Zoom up the AEM to see the frame. Unscrew the antenna or just shut the ED off and send again and as the TxPower is increased, the current goes DOWN. There are 3 tries = -6=38.79mA, -3=38.05mA then 0=10.41mA. Send again for 3 more tries = 0=10.42mA, 3=12.05mA, 6=14.22mA. Send again = 6=14.21mA 9=17.82mA 12=24.97mA. Send again = 12=25.0, 14=38.21, 14=38.1mA. So the problem is limited to the negative TxPower which are unusually high amounts of power. But how can I measure the actual TxPower?

This won’t impact the RF Range which seems to continue to use the correct power. It just confuses the dynamic power algorithm as negative power is a really strong connection then when you get to 0 it suddenly drops and thus the algorithm then jumps the power up quickly.

But why am I getting Z-Wave Mesh to have similar or even slightly better RF Range than ZWLR?

Seems the slave devices have the same bug. I tested it out with a 2nd WSTK2 and a ZGM230 RB and it also cranks the power when negative.

Using Railtest with a pn9 modulated ZWLR stream and setting power=200 (though the board is a 140 RB. With “SetPower 200” the current is 42.93mA. SetPower 140=38.24 so it would seem that TxPower at 38mA is full power. So the positive values are probably correct. Its just that the negative ones are broken. So that does not explain why the ZWLR range sucks. ZWMesh with setpower=0 is 11mA.

Setup the controller with SDK 7.24 again and join the ED as ZW Mesh. The max packet size is much smaller in Mesh so can’t send all that long of a packet. Using the PCC to set the Max Tx=-1 (which is -0.1dBm) I get 10.98mA. The baseline current is 5.72mA for the SerialAPI when it is sitting there idle with Rx running. Set the Max Tx=-60=9.56mA which isn’t much lower. But the transmit power is so low that normally it’s not going to change much. Main point is that it has not reversed the power and jacked up the current. Set MaxTx=140=36.92mA which means that if the PCC is set incorrectly it will transmit at high power even though we are in the US using Mesh – the firmware is not limiting it to 0dBm. It is very easy to accidentally leave the power up too high. Next step is to see what ZWJS sets the mesh power to. Note that ZWJS tries to set the max power so you must properly set the script to the proper max setting.

I finally got a ZG28 Explorer kit to work with SSv5 so now I can also test out the tiny chip antenna on it.

## 2025-09-04 – Limited production run quote

- Online quotes for 25 assembled boards (untested)
- Screaming Circuits (https://www.screamingcircuits.com/): 6 day turn - $3554 ($142/brd) We supply ZG23, LDO & Switch
  - 50 boards is $5102 ($102/brd) – 11 day turn is $3623 ($72/brd)
- Proto-Electronics (https://www.proto-electronics.com/): 10 day turn – 55Euros/brd – 1645 We supply ZG23 and LDO
  - Didn’t realize this is a European company
- RushPCB: 6-8 day turn - $109/brd for 25 $66/brd for 50
  - They give an entire table of days vs qtys – based in Silicon valley
- How real are these “instant” quotes? I uploaded the BOM but not the gerbers. Cheaper than I thought but is this the actual price when I place an order.

Mark Umina was interested in getting quotes to build more ZRADMinis for testing purposes so I got some quick quotes.

## 2025-08-12 – Home Assistant ZWA-2 testing

Todays’ plan is to compare the RF range of the following controllers:

1. Home Assistant ZWA-2 based on ZRAD
2. ZRADMini
3. UZB7 plugged directly into a PC USB port

These will all be tested by connecting to a ZRADMini with ANT-916-CW-RH-SMA which is a tiny and pretty terrible antenna. The bad antenna was chosen specifically to limit the RF range as the location does not have long distance LoS. The ZRADMini has Geoloc CCv2 and an M8Q GPS receiver to track the exact locations of the DUT. The test will be done in my neighborhood in Dover as it’s the middle of summer and the beach is too crowded to be able to do true long-range tests. The goal is to compare the 3 different controllers, not to find their respective max RF range. We already know ZRADMini has 4300m range LoS so we can use that as a ruler. The objective is to see how the controllers perform in “real world” conditions – IE: how far can they reach from inside a typical wood frame home.

The first requirement is to set the keys to be same for all the controllers otherwise ZWJS won’t be able to control them. When you Reset a controller in the PCC, it resets the key OVERRIDEs.

Key | Value
S0 | 00 00 00 00 00 00 00 00 00 00 00 00 00 00 00 01
Unauth | 00 00 00 00 00 00 00 00 00 00 00 00 00 00 00 02
Auth | 01 02 03 04 05 06 07 08 09 0A 0B 0C 0D 0E 0F 03
Access | AA CC AA CC AA CC AA CC AA CC AA CC AA CC AA 04
LR Auth | 01 02 03 04 05 06 07 08 09 CA FE BA BE BE EF 05
LR Access | CC AA CC AA CC AA CC AA CC AA CC AA CC AA CC 06

These are also programmed into the top of the ZWJSRangeTesting.js file:

const driver = new Driver(port, {

// logConfig: {

// logToFile: true,

// forceConsole: true,

// },

securityKeys: {

S0_Legacy: Buffer.from("00000000000000000000000000000001", "hex"),

S2_Unauthenticated: Buffer.from(

"00000000000000000000000000000002",

"hex",

),

S2_Authenticated: Buffer.from(

"0102030405060708090A0B0C0D0E0F03",

"hex",

),

S2_AccessControl: Buffer.from(

"AACCAACCAACCAACCAACCAACCAACCAA04",

"hex",

),

},

securityKeysLongRange: {

S2_Authenticated: Buffer.from(

"010203040506070809CAFEBABEBEEF05",

"hex",

),

S2_AccessControl: Buffer.from(

"CCAACCAACCAACCAACCAACCAACCAACC06",

"hex",

),

},

Originally tried to use a HST SmartStick G8 but it struggles to include a device securely. Often doesn’t work. If I override the key (which is required to get ZWJS to work) it never works. I updated the G8 firmware to 7.23.2 but that didn’t seem to make a difference. I wanted to try out a UZB7 but it has 7.11 in it and doesn’t do ZWLR. Unfortunately the latest version of SSv5 doesn’t include the scripts to generate the .gbl to update the code via OTW. Fortunately, I have another UZB7 with 7.17 in it which will do ZWLR.

I am running ZWJS on my laptop in a powershell window which works fine. Captured 20250812UZB.csv.

Trying to join ZRADMini board #3 to the ZWA2 but the QR code appears to have been damaged enough that it’s no longer readable. Regenerated it and taped it to board #3. Changed the buzzer from 3.3khz to 2.7khz – still working. The buzzer is a little louder and slightly lower but still a high frequency.

The official ZWA2 is not working with ZWJSRangeTest.js but the old one (with a 3D printed case) does work. I think the old one has the standard SerialAPI in it but the new one has newer firmware. I emailed Domenic. He suggested updating the firmware but that didn’t make a difference. I used his ZWJS tool to update the firmware: https://alcalzone.github.io/nc-zwave-firmware-flasher/ . I wired up the ZWA2 to J-Trace. Cloned the nabucasa/zwave-firmware repo and tried to build it in SSv5 but it immediately fails due to files not matching. Asked HA to replace the ZWA2 as I don’t have time to debug this single unit failure as it could easily take many hours to narrow the problem down and it appears to be a manufacturing defect with just this one unit.

## 2025-07-27 – Adding a Beep to ZRADMini board #4

I need a second GeoLoc board for more RF testing so I added an M8Q to board #4 which appears to be working. Next is to get the BEEP to sound each time a GeoLoc report is sent. This makes it easy for the person walking the GeoLoc node around to know they are no longer in RF range – the beeping will stop.

- To add a buzzer to ZRADMini:
- The buzzer is an AT-1127-ST-2-R (https://www.digikey.com/en/products/detail/pui-audio-inc/AT-1127-ST-2-R/5011397) from Digikey which is 2.73KHz
- Solder one pin of the buzzer into J6-1 (V3.3) and the other in J6-3 (PC00)
  - Requires slightly bending the pins as the pin spacing doesn’t quite match
  - The pins need to be pressed in tight for the buzzer to fit inside the case
  - Have the port face the QWIIC connector so the sound can exit that opening
- Solder a 150 ohm resistor between J6-3 (PC00) and J6-4 (PD02)
- PC00 will be tristate during the beeping but could be used to drive it directly
  - Might burn out the buzzer or the GPIO or cause excessive current draw
- PD02 is used to drive the buzzer with a series resistor to avoid burning it out
- Use a PWM to drive PD02 at the resonant frequency of the buzzer to get the beep and a timer to enable it for a fraction of a second

The firmware is setup for 3.6K but I didn’t want to risk having the code not work for some reason and the beep is audible though probably would be louder if closer to the resonant frequency.

## 2025-07-01 – Trident board Rev B

Minor error in the CZ20 RF->antenna circuitry required a respin to fix. See the github issue #10 (https://github.com/drzwave/ZRAD/issues/10). Changed the library for the CZ20 to be the standard KiCAD one now that the symbol has been merged (upgraded to KiCAD 9.0.2). This also uses a footprint with the exact correct size for the EP pad. The Trident docs note that the GND pins should NOT be connected to the EP so I removed those connections. The EP pad is only connected thru vias. Also switched to a more available RGB led footprint which has many compatible parts. Fixed C16 footprint.

The LED upgrade is confusing! First of all, the current part (QLSP14RGB) has an incorrect datasheet:

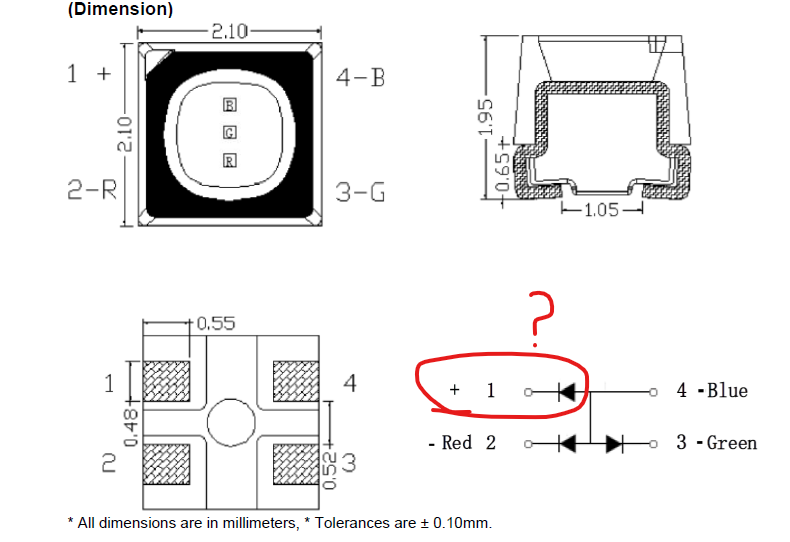
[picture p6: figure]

The QLSP datasheet schematic can’t be correct since the Anode cannot have a diode leading to it. The footprint I’ve been using for ZRAD has the pins clockwise (most devices are counter-clockwise) and pin 1=green, 2=red, 3=A, 4=blue.

The original Cree LED I used long ago has a completely different pinout than it seems the most common RGB LEDs have.

Chose a new LED and updated BOM, Schematic & layout.

The updated CZ20 symbol and footprint are proving to be quite a challenge. The footprint is now the exact EP size of 3.3mm but the holes are .2mm which is a violation of OSH Park rules where the min hole size is .254. And now there are several clearance violations with nets that go 45 close to a pin. The easier solution is to use the version without the thru holes in the EP and then add some of my vias to it. I disabled Tenting on them to see if the solder will flow down into the holes (which it does). The version that is tented didn’t seem to perhaps because the holes are filled with air and nowhere for it to go so the solder won’t flow down.

There are 5 excluded PCB violations:

The first 4 can be ignored and are caused by adding a via to the USB shield pads which provides additional mechanical strength making it harder to rip the pads off the PCB when plugging/unplugging the USB connector. The 5th one is the UFL connector which can be ignored since it is only used for checking the PCB antenna impedance. I’m not particularly happy with that footprint anyway – why does it block the back side?

Six PCBs & stencil ordered, new LED ordered.

## 2025-05-09 – Trident board build

Minor errors: 120pF in BOM is 0603 but footprint is 0402 – change BOM, C16 footprint is 0603 but BOM is 0805 (should be 0805).C1,2&3 are NM unless PCB antenna. Need to order enclosures.

Main problem is that board #2 CZ20 didn’t solder very well at all. Seems to have lifted slightly especially on one side. Many of the pins had no solder on the pad – where did it go? Did the EP suck it all in? The vias are not filled with solder so maybe they are all sucking it in? I was hoping the vias would suck the chip tight. I hand soldered the CZ20 but are there opens/shorts? Board #1 was fine. The metal stencil is definitely better than a mylar one – worth a few extra bucks. Both boards had a few shorts on the USB connector. Is there a different one with better pads? Also want to swap to a slightly different size LED that is a more common size. Both boards program fine but are not producing NodeInfo or any RF. The HF crystal is 32MHz, not 39MHz so I had to order some 32MHz which will be a few more days before I can get into RF testing.

Built boards 3-5 which are all working as far as I’ve been able to test them so far.

3D printed jigs for drilling the enclosure to make the holes in the right place. Waiting for the metric drill bits to arrive.

## 2025-04-30 – Adding a buzzer to GeoLocCC

One problem with GeoLocCC is that when in the field it is difficult to see an LED in bright sunlight to know if the DUT is beyond range or not. An easier solution would be for it to beep audibly every time a REPORT is sent. I have a Piezo 3.8khz buzzer (AT-1438-TWT-R (https://www.digikey.com/en/products/detail/pui-audio-inc/at-1438-twt-r/1464840)) I can try to drive with a PWM on a ZRAD. Supposed to be 5V but I can probably drive it with 3.3V and the GPIO will ground the other pin via a GPIO connected to the PWM then tristate the GPIO when not buzzing. Supposed to be 1mA and produce 80db but it’ll be inside the enclosure so it’ll be less and 3.3V. I need to add a 3.3K ohm resistor to limit the current to 1mA though maybe a bit less will also be OK as the buzzer also has internal resistance. Cheaper alternatives: AT-1224-TWT-5V-2-R (https://www.digikey.com/en/products/detail/pui-audio-inc/AT-1224-TWT-5V-2-R/5011404), GT-11PS (https://www.digikey.com/en/products/detail/soberton-inc/GT-11PS/479668), PS1720P02 (https://www.digikey.com/en/products/detail/tdk-corporation/PS1720P02/935932). J6 on ZRADmini has +3.3V and 3 GPIOs. The buzzer is 13.8mm and overhangs the PCB by about 3.5mm and is too tall at 7.3mm. The GT is much lower in height and slightly smaller but would still overhang. I’m working with board #3. Surface mount buzzers are generally very low height. AT-1127-ST-2-R (https://www.digikey.com/en/products/detail/pui-audio-inc/AT-1127-ST-2-R/5011397) would work better as it has a port out the side and might just barely fit in the case. Or use PT-1704 (https://www.digikey.com/en/products/detail/soberton-inc/PT-1704/1245316) which has wire leads. I also have GT-0950RP3 (https://www.digikey.com/en/products/detail/soberton-inc/GT-0950RP3/479660?s=N4IgTCBcDaICwGYEFoCMAGVcQF0C%2BQA) which is much smaller and fits in the case so I’ll use that – 3.2KHz, 30 ohms, rated for 30mA so a 330 ohm resistor would be OK. The pins are 4mm spacing (0.157in) which doesn’t line up with my holes but the leads will bend OK. It will connect to PC00 directly but I’ll have a 300 ohm resistor to PD02 which is what I’ll plan on using.

1. Upgraded the project from 2024120 to 2024122 – build it ensure it still works
  a. Had to edit the SDK ZW_cmdclass.h file again since the SDK updated from .1 to .2
  b. FLASH is overflowing by 92 bytes!
  c. See my blog (https://drzwave.blog/2025/05/01/dreaded-flash-memory-overflow-solutions/) for how to get around it while debugging
2. In SSv5 in the SwOnOff_2024120_ZG23B_geoCC project, add Platform->Driver->PWM->PWM component
  a. Name the instance “beep”
  b. Configure it with: PWM Freq=3200, Selected Module=TIMER0, CC0=PD02, Output Channel=0
  c. The SL_PWM_BEEP configuration has a bunch of things to choose but NO DOCUMENTATION on what they do or why I would want to use it. I clicked on the Documentation button and it brings me to the PWM Driver on docs.silabs.com. But nothing explains what CCx is or does. I happen to know these are documented in the reference manual but I don’t want to have to chase this down – it should be right here in SSv5!
  d. Code compiles and it seems the PWM is initialized but no sound.
  e. The SSv5 debugger doesn’t display any data in the peripherals window. Appears to have all of them but when you click on them you get nothing. The console says it read a lot of registers. Aha – register contents are in the Memory window. Timer0_NS is running and enabled. Mode is PWM. COFOA is 0 but should be 1 to toggle the output? Change that in the debugger but still no sound. Tried various other registers in the timer and GPIO but no sound. Looking on the scope, nothing is coming out.
  f. I added sl_pwm_start(&sl_pwm_Beep); in sl_pwm_init.c to see if I just needed to “start” it but that didn’t do anything either.
  g. No documentation says how to enable Toggle mode.
  h. It’s easier to just directly write the registers than try to figure this out!
  i. Once again, there is no thought as to how the average user would want to use a timer and then provide a simple API to do the most common basic operations. The timers have a ton of features, few people ever use. In this case, the API barely does anything and it would seem it doesn’t even do it correctly. Plus the documentation is of very little help. Ugh.
  j. After several hours of debug in Ozone and randomly setting various registers to various values I’ve come up with what appears to work. The driver does not setup the timer properly. For some reason Ozone is unable to alter the timer CTL register as I cannot change the HALT bit so the timer runs while debugging. The Status register says the timer is not locked but it will not let me change the values.
  k. Registers that need additional setup:
    i. TOP is set to 0x2F9A which is computed by the driver
    ii. Timer0.CC0_CTRL.CMOA=b’11 – set the output on compare match
    iii. Timer0.CC0_CTRL.COFOA=b’10 – clear the output on timer overflow
    iv. Timer0.CC0_OCB=Timer0.TOP/2 – set the compare to ½ TOP = 17CD
    v. TIMER0->CC[0].CTRL |= (0b11<<8) | (0b10<<10); // Set on compare, clear on overflow
    vi. TIMER0->CC[0].OCB = TIMER0->TOP/2; // set CC0 compare to be 1/2 of TOP for 50% duty cycle.
  l. The buzzer isn’t that loud and the voltage is just a fraction of a volt with a lot of over/undershoot at the edge. Using PC00 (directly drive the buzzer without a resistor) also works and is much louder but will that impact the RF or overall current thru the chip? And it’s not that much louder. I’ll just drop the resistor from 300 to 150 ohms. 3.2K is pretty high pitched.
  m. Next step is to figure out how to set a timer to run the timer for X amount of time. Might be easier to install an ISR and have the timer itself self-time? The easy software timers from the 500 series appear to be gone. Incomprehensible Silabs timer API is totally useless.
  n. To add the ISR, in the same sl_pwm_init.c just add:

#include <em_core.h> // Interrupt numbers

void TIMER0_IRQHandler(void) { // Run the timer for ~1/2 sec then shut it down - Audible beep lasts for 1/2 sec.

static int count;

if (count<=0) {

count = TIMER0->TOP/4;

TIMER0->CMD = 0x02; //STOP

} else {

count--;

}

TIMER0->IF_CLR = TIMER0->IF; // clear interrupts

}

  o. And just below the REPORT in CC_GeographicLoc.c is the one line to start the timer each time it sends a GeoLoc Report: TIMER0->CMD = 0x01; // start BEEP timer

Check files in. Time for more range testing! Maybe switch the GPIO to be Open Drain and invert the polarity so the pin floats high in idle and only draws power when beeping.

## 2025-04-15 – Trident PCB release to fabrication

The mounting holes and fudicials were dropped when I updated the PCB from the schematic it appears. Had to add those back in. There are 8 DRC error exclusions. The 2 Fudicial marks, 4 vias with one connection on the USB SMD mounting pads, the U.FL connector doesn’t match the one in the library which has several DRC errors in it, CZ20 footprint in the library has .2mm vias in the EP but the minimum allowed is .254 so I had to manually increase those. Ordered 9 PCBs and a metal stencil.

## 2025-04-14 – Trident PCB layout

I am experimenting with the CZ20 footprint with thermal holes in the ground pad. I normally don’t like holes as they sometimes are not as flat and might result in the pins not making good contact. I also made the paste holes a little smaller as too much paste does cause the chip to rise up though the holes might help with that by sucking some of the solder down into the holes. This required some modifications to the footprint to pass DRC and exclude a few errors.

## 2025-04-11 – Trident Schematic

Completed the schematic capture. The CZ20 KiCAD symbol is still being worked out but the PR has been created.

## 2025-04-09 – Begin TridentIoT version

Trident is providing a little funding to cover the costs for developing a ZRAD version with the CZ20 chip on it. Work begins today. The first step is to upgrade to KiCAD 9.0.1.

## 2025-02-13 – GeoLocCC adding non-gps support

Wanting to finish up the implementation of GeoLocCCv2 I need to add support for storing the GPS location in NVM. So, first step is to google “silicon labs NVM token file storage” and see what I can find for documentation:

1. AN1154 – is an out of date document for NVM with EmberZNet PRO
2. AN1135 – Is an NVM3 document that is still valid and specifically mentions Z-Wave support
  a. Just points to INS14259 section 7.2.
  b. INS14259 gives a pretty succinct description of how to use NVM
3. NVM Api (https://docs.silabs.com/z-wave/latest/zwave-api/nvm) – docs.silabs.com NVM API specifically in Z-Wave which is autogenerated from the code
  a. The functions are described but again, it’s like reading the dictionary when I want a short story
  b. Too much information and no guide as to what’s important
4. Zpal-nvm (https://docs.silabs.com/z-wave/latest/zwave-api/zpal-nvm) – Slightly more documentation on docs.silabs.com which points out the _init, _write, _read functions which are in fact the 3 ones I’m interested in
  a. Low level routines called by the NVM api in INS14259
5. UG103.7 – NVM storage fundamentals – generic document on NVM3

The immediate problem isn’t lack of documentation; it’s sifting thru the docs trying to find something useful.

Next, I used the Silabs “Ask AI” search tool “How to use NVM3 in Z-Wave?” which did pretty well at summarizing what needs to be done! But it is apparently unaware that NVM3 is already instanced and initialized by the Z-Wave stack so AI has way too much detail on initialization. AI did provide sample code calling ZAF_nvm_* functions. It did not suggest using the NVM API or Zpal-nvm described above.

Next, I searched thru the sample apps looking for an example and found that they all initialize NVM. The PowerStrip app specifically uses NVM to store configuration data and other stuff. See ZAF_nvm.c which stores the zaf_handle and provides a basic set of commands. See ZAF_file_ids.h for the file ID #s which are simply sequential number in parenthesis. File IDs are 20 bit numbers. What are the numbers used by the Z-Wave protocol? I assume fairly large numbers? INS14259 says the app must only use 16-bit FileIDs as the upper 4 bits are used for Z-Wave. 12K is available to the application. Just do a ZAF_nvm_app_write() to initialize a new file. Must also write a default value into zaf_nvm_app_set_default_configuration() which is called on exclusion or factory reset.

## 2025-01-27 – EMEA Prep – GeoLoc testing

Worked with Dominic to get the index.js working using the latest ZWJS and working on my laptop. Building more EULR devices to test with. I need to see if the ZRADMini has similar RF range to ZRAD to avoid bringing the large ZRAD to Barcelona. Spent most of the day but have 1 ZRM with an SMA antenna and GeoLoc, 1 with SwOnOff PCB antenna, a TBZ with SwOnOff connected thru a USB hub powered by my Anker brick.

Dominic updated index.js to capture up to 3 other devices and seems to work. But it puts the GeoLoc data into separate files. I need them all in the same file with the NodeID then Excel 3D maps will color code the nodes. I fixed the script and now it puts the nodeID as a column which 3D maps can then color code. Field testing tomorrow!

## 2025-01-24 – EMEA Prep – GeoLoc build

Trying to install I2CSPM into my project with keys so I can OTA. But installing I2CSPM says it need IO Stream but then fails. The docs say there are no dependencies but clearly there are. Installing I2CSPM is not configurable so clearly something isn’t working. Uninstalling then gives a Validation Error. Previously I had always enabled DEBUGPRINT so let’s try that. Nope that doesn’t work. DebugPrint doesn’t install the IO Stream. I reverted back to my older project that has geoloc in it but no keys. Not sure what the difference is but as usual SSv5 makes it impossible to move forward so instead I move backward. I need to get the javascript program pulling more than 1 DUT today. Unfortunately, I have no idea how to write JS. How does one figure out what calls to make? Scheduled a call with Dominic on Monday

In the meantime, let me try to get ZWJS running on my laptop so I don’t have to lug 2 of them all around Spain. I have Z-Wave-JS-UI installed using npm install zwave-js-ui. This gives me the ability to add/remove nodes and test them using chrome on my laptop. Browse to: http://localhost:8091/#/control-panel after starting ZWJS by starting a powershell and typing “zwave-js-ui”. But it won’t talk to Node? – node gives a MODULE_NOT_FOUND.

## 2025-01-23 – EMEA Prep – Document OTA & key generation

Updated the ReadMe.md for 2024.12.0 and added the key generation information. I built the bootloader, generated Keys, created the app and configured the minimum needed for the sample app and documented all that and checked it in.

## 2025-01-22 – EMEA Prep – Build EU End Device with GeoLoc

Got a controller and Zniffer for EU. Next is the End Device with GeoLoc using 2024.12.0.

Tried following the new CLI code in the sample app SwOnOff. It is massive, bloated, barely documented, impossible to follow and not at all needed by customer code. Typically, you’d want to rip all that out. I can’t figure out how to just send some chars out the uart (or even which uart is configured for it – pintool says it EUSART0). I use the same pinout as the TBZ so the blue and green LEDs and learn button are the same and the UART. For now I’ll try to make minimal changes to the sample app. First step is just to join the EU controller and see they talk. That much is working – joined and Basic Set will turn the blue LED on/off. Indicator SET will blink the green LED. Now to add GeoLoc. Followed the instructions with a few minor updates to a couple of files and it compiles. Plugged the M8Q in and it worked first time. I need to update the code to remove the valid bits which are no longer needed. I ordered 2 more M8Qs just to have a spare in Spain.

I tried to get ZWJS to run but it wants to use USLR so I emailed Dominic to ask how to get it into EULR.

All devices must support Firmware Update Get/Report which is a good command to test range with as the report is fairly long. Or use Association grouping get for a very short command?

## 2025-01-21 – EMEA prep

Building and testing EU devices for use at the EMEA summit.

Board 3 travelled to CES and the little M2 screws inside the case fell out and rolled around. It seems #3 no longer works over the UART via USB. It will talk over the tag-connect cable but USB is not recognized when it is plugged into a PC. Nope, I has incorrectly listed #2 as the one with the bad USB but it is #3. Working to get #2 with the Zniffer in it – follow the README.md. Board #2 seems to work when also powered via the tag connect but not via USB only? #2 Zniffer works when connected thru the WSTK to COM4 but not straight thru the USB. Doesn’t work with the PC Controller either. Maybe the USB doesn’t work on board 2 and board 3? AHA! The first via on board 2 from R7 (VCOMRX) was open. Looked OK but was not making contact thru the PCB. I stuffed a wire thru the via and soldered it in place and now it’s a Zniffer via USB. Perhaps board 3 has the same problem? That via is a standard via on .1mm center so it’s just a manufacturing defect. Maybe I will make this via a little larger if board 3 has the same problem. No, board 3 has a different problem – the CP2102 doesn’t seem to respond at all.

Trying to install the SerialAPI into board #6. Won’t connect to the WSTK but the board is programmed and has the SwitchOnOff app in it. I had to use Commander to Recover Bricked Device as I believe it was just locked. Doesn’t seem to talk via USB but PCC does work via WSTK. The RX and TX seem to be connected – no opens. Power cycled my PC and now its working fine. Seems the EULR max power is 14dBm? PCC gives an error when trying to set it to +20. Seems that is the regulatory maximum.

## 2025-01-03 – Test program development

Started building the Test program for ZRADMini. Testing boards 1-6 in preparation for the EU summit where I’ll need reliable ZRADs with GeoLocCC.

For whatever reason, programming is failing to boot via the python program. But if I program the exact same file using commander it works just fine. The python program first flashes railtest to calibrate the crystal. The python program is not programming the bootloader whereas commander does. The .s37 file has the bootloader merged along with the keys. That’s because I had the unmerged filename in the python script! That fixed that problem. Now I’ve got problems with the QR code generation. Something must have changed in the environment as I needed to assign the type of img to get it to work. Board 4-6 appear to be working. Haven’t tested everything but they programed fine.

## 2024-12-30 – Build ZRADMini boards 4-6

Wiped off ½ of the solder paste from the USB connector which resulted in few solder shorts and still made good connections. Still seems to be too much solder on most components. Looking closely at the stencil the holes are slightly larger than previous versions of the stencils. The price of the stainless steel stencils has come down significantly (used to be $100+, now $30) and might be worth it to minimize rework clearing shorts. I changed the paste size to be -5% and maybe next time I’ll order a 5mil instead of 3mil as maybe the 3 mil is so thin it’s letting paste squeeze under it? Or just pay the extra for steel?

## 2024-12-28 – ZRADMini Test Jig

Designed a ZRADMini Test jig which uses a Tag-Connect pogo post cable to press against the test points on the PCB and a clamp to hold the PCB in place. I had the Rev A jig 3D printed but realized I measured the connector position from the wrong end of the PCB so this one is not usable. It is handy to check the overall dimensions. I have too much play in the PCB with 1mm on all 4 side. Better to be 0.5mm I think. Still want some play as the key feature is the Tag-connect which has alignment pins in it. The PCB does not have the footprint on an even 1mm grid which makes it a pain to properly line up. It does need to be about 5mm in from the edge of the PCB and not right on the edge without some tricky 3D printing of the jig. From the ANTENNA end of the PCB to the center of the tag-connect it 44.5mm and 4.365mm from the edge. I incorrectly measured from the USB end instead of the antenna end.

## 2024-12-11 – ZRADMini PCB antenna tuning

On a bare PCB with just the series cap with a 47pF cap and the UFL with the RX path cut off installed in a case with screws and then connected to my Agilent N9912A spectrum analyzer I get:

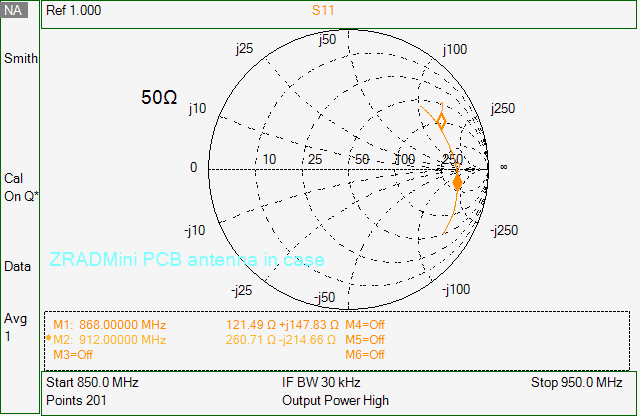
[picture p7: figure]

The antenna needs to be optimized for the EU for the unplugfest in Feb. But I’ll start with US at 912MHz.

This is not a particularly ideal starting point. If the antenna is closer to 50 ohms to start with would be better. Plus the antenna design is stuffed into the end of the PCB with long edges next to each other which I have heard will tend to cancel each other out resulting in a less than optimal antenna design.

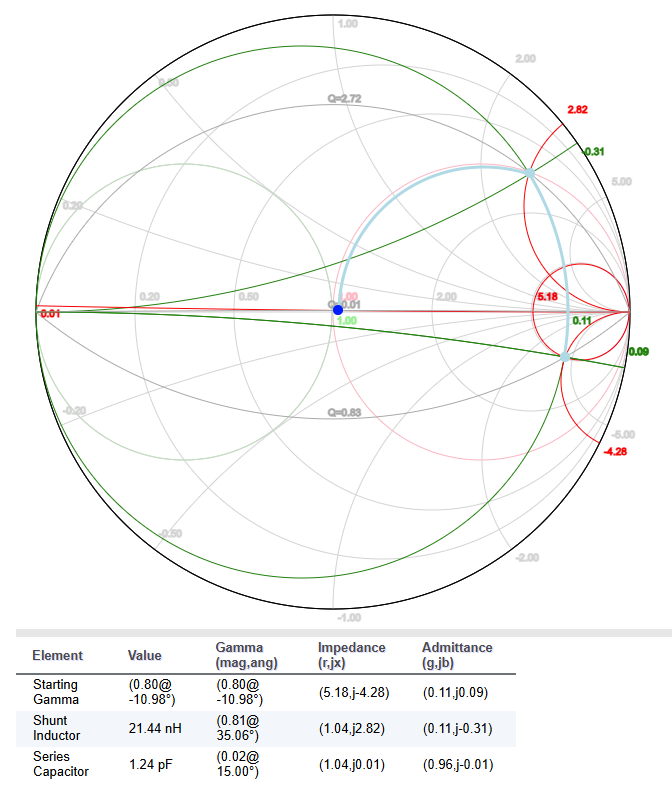
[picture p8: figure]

Use the RFMentor (https://www.rfmentor.com/content/smith-chart-matching-app) smith chart tool to calculate the matching network. Usually 2 components, sometimes 3. The tool only approximates the match as real components have many other parasitic effects. But it is a good start. Divide the real and imaginary parts by 50 (ohms) to get the normalized values needed for the RFMentor tool to get 5.21,-j4.29, Click in the circle to set the first point as close as possible. One option is to add a shunt inductor to swing up then a series cap to bring it back down to 50 ohms as shown here.

But the series cap is too small to be practical.

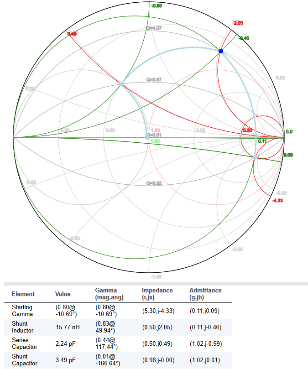
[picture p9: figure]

Using all 3 elements looks better. From the antenna inwards is a 15nH shunt inductor to a 2.25pF series cap into a 3.49 shunt cap. The next step is to try some real components and see where we land after installing them one at a time.

The 868 frequency (2.43+j2.96) would be something like a 2.12pF shunt into a 20nH series inductor.

Start trying various real components to see where we go. The BOM already has a 13 and 18nH inductors so we’ll start with those. Solder a 13nH inductor into C2 we get:

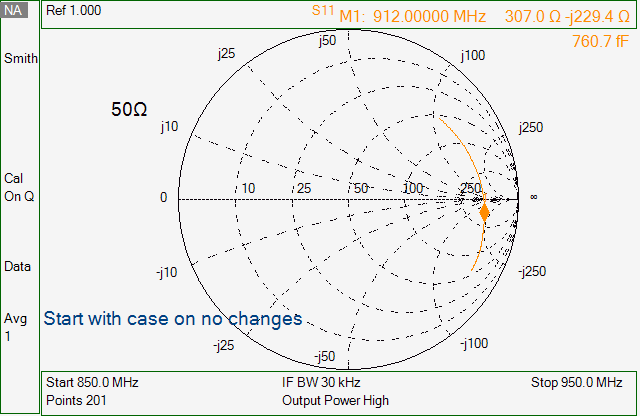
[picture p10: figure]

Initial setup. C7=nm - shunt C3=47pF - series C4=nm – shunt closest to antenna Case is on with screws installed Placing a piece of wood next to the case shifts down slightly – similar to mounting the case to a rafter. Drywall is a bit more of a shift but still not much.

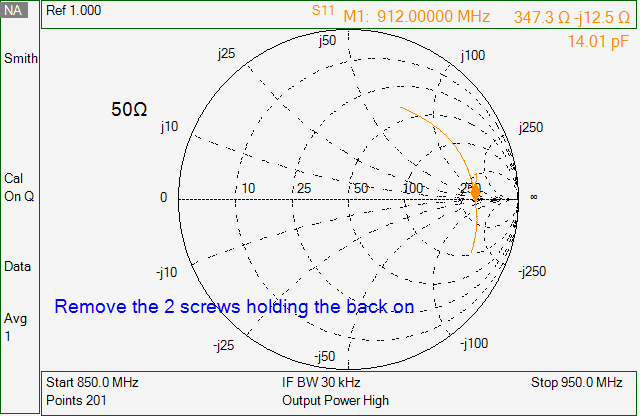
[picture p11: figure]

Remove the 2 screws holding the back on. Slight shift but not enough to eliminate the metal screws but they do have to be part of the matching effort.

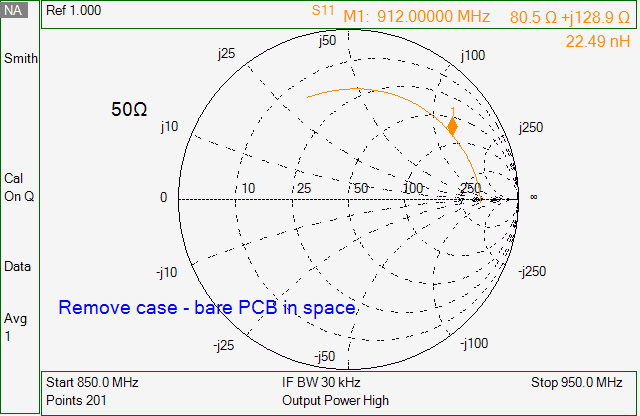
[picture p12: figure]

Remove the entire case shows the case does make a significant impact. The case is quite thin and only a few mm from the PCB. Measurements from here will include the case since it makes such an impact. Once challenge is that the UFL has to be unplugged each time a value is updated. This might result in the UFL failing as it is not intended for this many plug/unplug cycles.

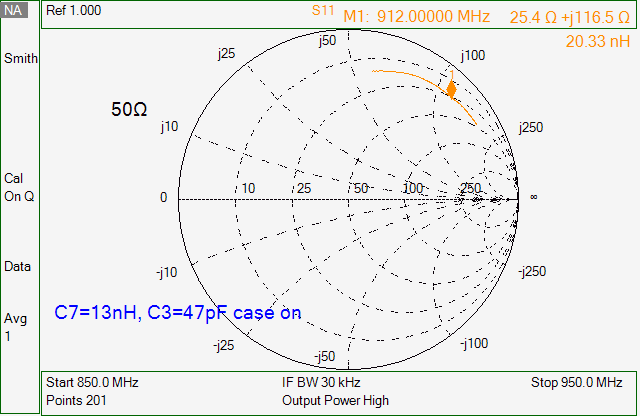
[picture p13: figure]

C7=13nH - shunt C3=47pF - series C4=nm Case on As expected this moved the point up. Using RFMentor a 2pF series cap should bring it back down. 0.508+j2.33 A 2.0pF series then 3.5pF shunt would get this right to 50 ohms
C7=13nH - shunt C3=2.2pF - series C4=nm There is a 1.9pF already in the BOM but maybe we can use 2 of these to get very close. 2.2pF is too low of a value. Try a larger one.
C7=13nH - shunt C3=3.3pF - series C4=nm Looking better, now a 3.3pF shunt should bring us down to 50 ohms.

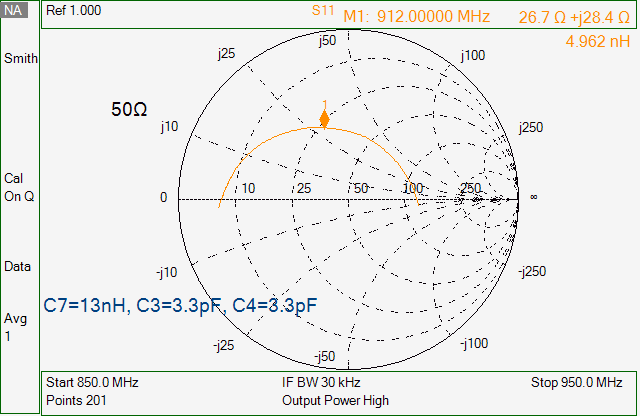
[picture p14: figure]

C7=13nH - shunt C3=3.3pF - series C4=3.3pF – shunt Not enough. But will a larger inductor for C7 bend us down where we need to be? I have 18nH already in the BOM. Experimenting with RFMentor looks like it might work.
C7=18nH - shunt C3=3.3pF - series C4=3.3pF – shunt Close! VSWR is below 2 but still above 1. Need a slightly smaller C3 should get us right in there. We are close to the original values predicted by RFMentor.

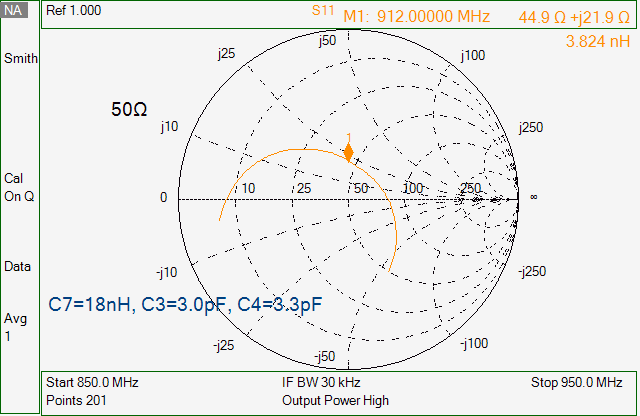
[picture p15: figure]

C7=18nH - shunt C3=3.0pF - series C4=3.3pF – shunt Shifted to the left but didn’t reduce the imaginary part which is what we really need. Need to increase the inductor a little more.
C7=22nH - shunt C3=3.0pF - series C4=3.3pF – shunt This is about as good as you can get. The inductor is a Johansen instead of murata so that could throw some variability in but that’s the only value I had. Could C3 be a little smaller? It’s already smaller than I would like to push all the RF power thru it.

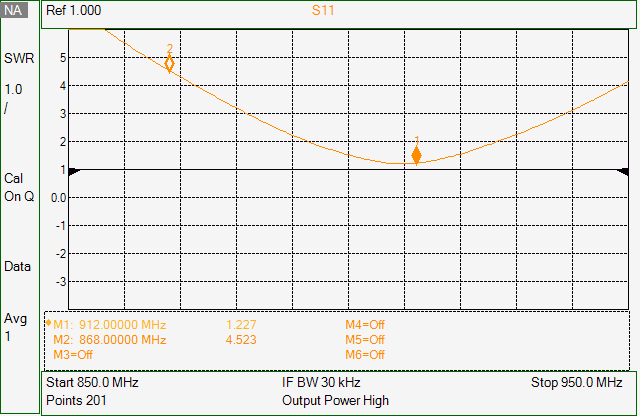
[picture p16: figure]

VSWR is below 2 and very wide. 1.2 is about as good as you can get but 4 is not so good. So stick with these for US. I’ll check EU some other time. EU will need different matching values. The PCB vendor can also result in changes in matching so any time the boards are ordered in volume a quick match check should be done.

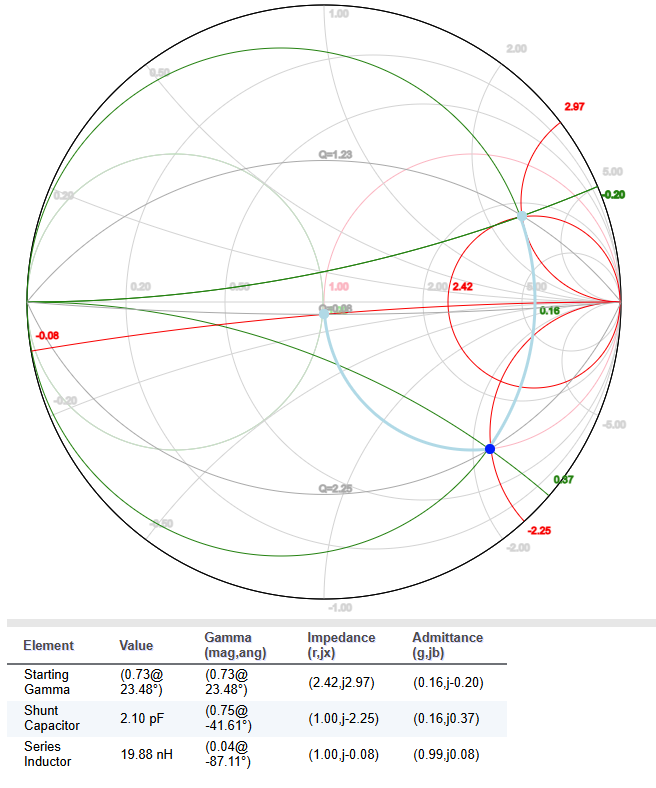
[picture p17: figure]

EULR frequencies are 864 and 866MHZ but that’s close enough to 868 for matching purposes. Checking the EU match values – start at 2.43+j2.96:

Looks like a 2pF shunt then a 19nH series inductor should do the trick. Do I need a DC blocking cap? I don’t have a footprint for that. C4=2pF, C7=18nH yields 247-j130 (4.9-j2.6) which isn’t much better and not what we need. A larger cap should push it down further and a larger inductor will bring it back up. Maybe the cap was damaged when I soldered it on – didn’t look that good when I took it off. Switched C4=3.3pF yields 107.4-j9.6 (2.14-j0.19) which isn’t terrible but need to move left somehow. Increase C4=3.9pF yields 74.9+j35 which is really odd as it should go more negative. Other parasitics must be impacting more than the actual cap value (blobs of solder, traces etc). The other option is a large shunt inductor into a small series then a shunt cap similar to US.

Try a 27nH shunt into a 3.3pF series and 3.3pF shunt yields 19.4+j9.3 which is too far to the left. Use larger caps – 4.7pf for both. That works!

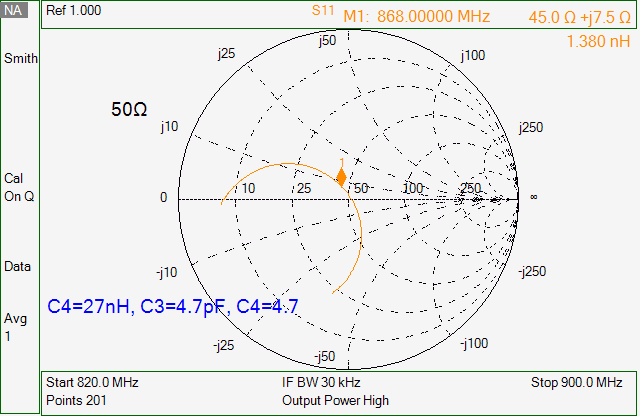
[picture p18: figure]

EU Tuned antenna: C7=27nH, C3=4.7pF, C4=4.7pF yields 45+j7.5 and VSWR=1.2. Fortunately, neither required changing the length of the antenna itself so the PCB does not need to be redone. Now the question is what the range will be of the PCB antenna vs. the SMA external one? Need to test that but first need to build a PCB tuned for EU and US. The optimal frequency is 872MHz.

Updated the schematic and BOM with this info.

## 2024-11-17 – ZRADmini build

Built 3 boards. All had numerous solder shorts. I used a brand-new tube of solder paste and must’ve put it on too thick. I did swipe it thin with a 2nd pass but apparently the new solder squeezes under the stencil. The USB connector is tough to clear the solder shorts.

The SMA antenna should be soldered to the bottom of the PCB. The PCB fits in the case fine. The USB connector is recessed too much but not sure I can bring it closer to the edge (might need a different connector). The case must be cut to have a hole for the USB connector. The first 2 boards I built have the SMA on the wrong side but it is possible to put the PCB in backwards but the USB connector is hard to reach. Tried to desolder it but the SMA will not come out. Clearing the solder shorts under the USB on board 1 and 2 required several tries.

Board Status:

1. PCB antenna – OK – Runs SerialAPI
2. SMA antenna (wrong side) – runs SerialAPI but does not talk over USB, CP2102 does not pass data.
  a. Limited to an End Device
3. SMA antenna – runs SwitchOnOff & SerialAPI

Tried to load the XG23-RB4210A serialAPI but it goes into a reset loop for some reason. Use commander to Recover Bricked Device to bring it back. I built the bootloader and SerialAPI to debug them based on the 4210 devkit and not a custom PCB which has worked fine in the past. The bootloader runs fine. The SerialAPI gets to sl_stack_init() and jumps to 0xdeadbeee somewhere and then is stuck in the reset loop. Following the code in more detail into sl_zwave_protocol_startup() which is library code which then crashes. The code runs fine on a DevKit so something in the library code is checking for something and branching to 0xDeadBeef. Tried Ozone but it didn’t give any more details. The challenge is that the chip goes into a reset loop which the debugger disconnects so you can’t track backwards to figure out the cause. Ozone doesn’t catch the failure either. I did track the code further thru system_startup_core into sl_dcdc_vmon_init(0x0802A2C8 which is in sl_dcdc.c line 136). Sl_dcdc_power_mode_select(0x0802A23C line 56). EMU_DCDCModeSet(which is source code). Fails at line 3506 which writes DCDC_CTRL_MODE(0x01) to DCDC->CTRL_SET. This bit switches from BYPASS mode to enabling the DCDC switcher which apparently doesn’t work on ZRADmini? The power supply then crashes until the chip resets and the debugger disconnect.

The Devkit does this on powerup:

The DCDC is in bypass with Dvdd at 3.3v which then ramps to 1.8v then the DCDC starts kicking the inductor so that the voltage remains at 1.8V.

The 2.2uH power inductor on the devkit uses a 1008 package with 1.9A and 101mOhm resistance. Which seems like massive overkill since the digital logic will only be drawing a fraction of an amp (probably just trying to minimize losses at great expense). ZRAD uses a 2.2uH in an 0603 package with 750mA and 375mOhm resistance which isn’t bad (also only 6 cents compared to 31). There are 0805’s that are only 14 cents with 1.3A and 156mA which is closer to the one on the devkit.

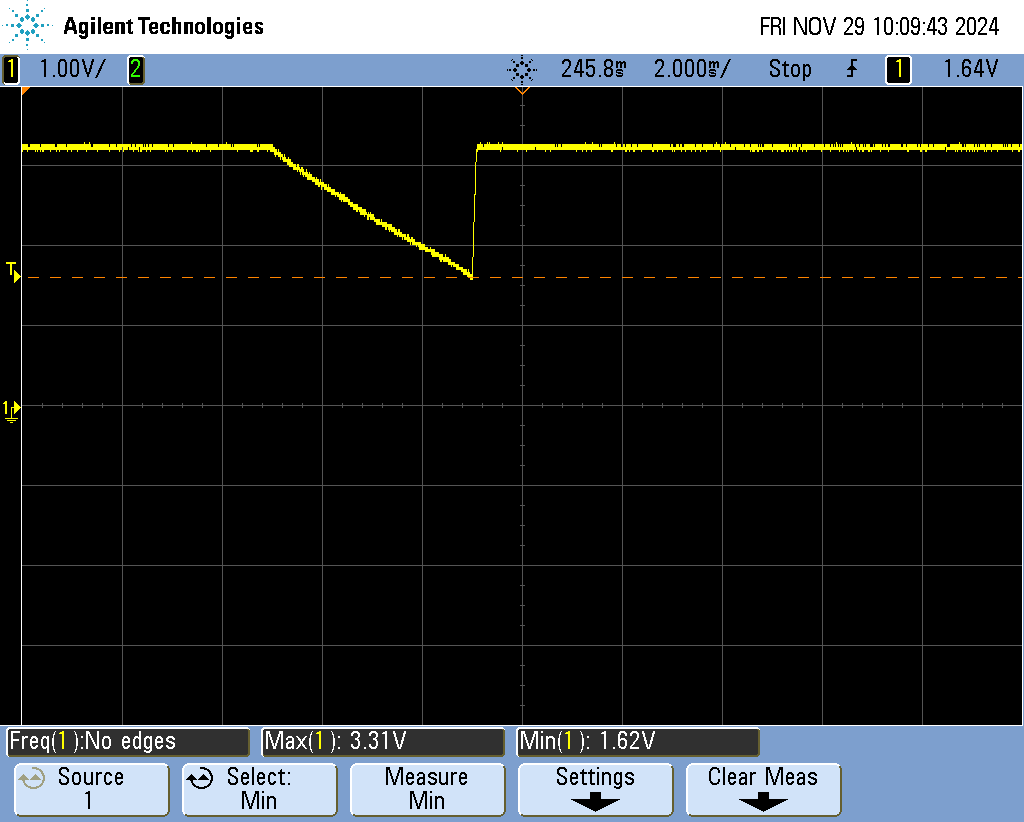
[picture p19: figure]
instrument screen

The ZRADmini however drops to 1.6v and then obviously the voltage monitor kicks the reset line and the chip is then stuck in a reboot loop.

Reversed the SMA connector on Board 3. The DCDC runs fine on that board with SwOnOff and the SerialAPI.

Thus, Board 1 and 2 appear to have a problem with the DCDC switching and will not run code that enables it. Board #1 has an open on the VREGSW pin which is a corner pin. Soldered that pin again and now it is working. Board 2 appeared to have a bad 2.2uH inductor so I replaced it. It runs the serialAPI code but the PCC does not recognize it. Connections to the ZG23 look good. Touch soldered the pins on the CP2102 which were fat but still doesn’t talk.

Board #2 USB pins are not shorted but the CP2102 does not send any data out the Tx lines. Something about the CP2102 has failed but nothing obvious. I touch soldered most of the pins. The USB pins toggle and look OK. Dminus is normally low but also on a good board. Board #2 will be limited to ED only – powered via USB but can’t talk over it.

## 2024-11-26 – GPS examples

The AWG reviewers of Geoloc CC V2 want several examples of the GPS coordinates and the hex values stored in the ZG23. This also brought into focus the need to also have some Test code to make sure it all works.

Tried to find a map that would also output NMEA sentences with altitude and then I could put those into the code and make sure they generated good numbers. Couldn’t find that in one tool but combining a few you can cobble together some examples. GPS tools: NMEA Checksum (https://www.meme.au/nmea-checksum.html) calculator, Google Earth will give the decimal coordinates and altitude from the map by dropping a pin, GPS Visualizer (https://www.gpsvisualizer.com/calculators) can convert between formats, Generate a NMEA file from a map nmeagen.org. The process to generate sample NMEA sentences: Use NMEAGEN.ORG, search for a location, click on a specific spot, Generate NMEA File (which downloads a file), copy the GPGGA line (has 0.0 for the altitude), paste that into the NMEA Checksum calculator (delete the checksum and the leading $), find the altitude via Google Earth, plug the altitude into the 10th field (0.0,M), recalculate the checksum, then plug the compete NMEA sentence into the test code.

1. Eiffel Tower: $GPGGA,220333.093,4851.542,N,00217.669,E,1,12,1.0,37.0,M,0.0,M,,*55
2. Death Valley: $GPGGA,220333.093,3613.846,N,11647.047,W,1,12,1.0,-86,M,0.0,M,,*73
3. Sydney Opera House: $GPGGA,221800.175,3351.398,S,15112.920,E,1,12,1.0,4.2,M,0.0,M,,*74
4. Christ Redeemer Statue: $GPGGA,221800.175,2257.114,S,04312.624,W,1,12,1.0,703,M,0.0,M,,*73
5. McMurdo Station: $GPGGA,221800.175,7750.807777,S,16640.261234,E,1,12,1.0,118,M,0.0,M,,*67

These landmarks were chosen because one is in each quadrant of the earth, Death Valley is below sea level (negative altitude) and McMurdo Station is close to the ends of the valid values.

## 2024-11-14 – Release Rev A of ZRADmini

ZRADmini PCB was released to fabrication – should get 9 PCBs next week. Ordered components to populate them with.

## 2024-11-13 – Create ZRADmini

Requested an account on Altair for their FEKO antenna simulator. TO use the 1551 enclosure the 900MHz meander antenna I’ve used before doesn’t fit. The TI antenna uses 28 folds of 6+1mm = 19.6cm which is much less than the 33cm which is the wavelength of 913MHz but also longer than ½ wavelength. RayPCB.com (https://www.raypcb.com/how-to-design-pcb-antenna/) has an antenna tutorial. Had to create a new shape for the PCB antenna. Most cases the SMA will be used but the PCB is there mostly to compare RF range.

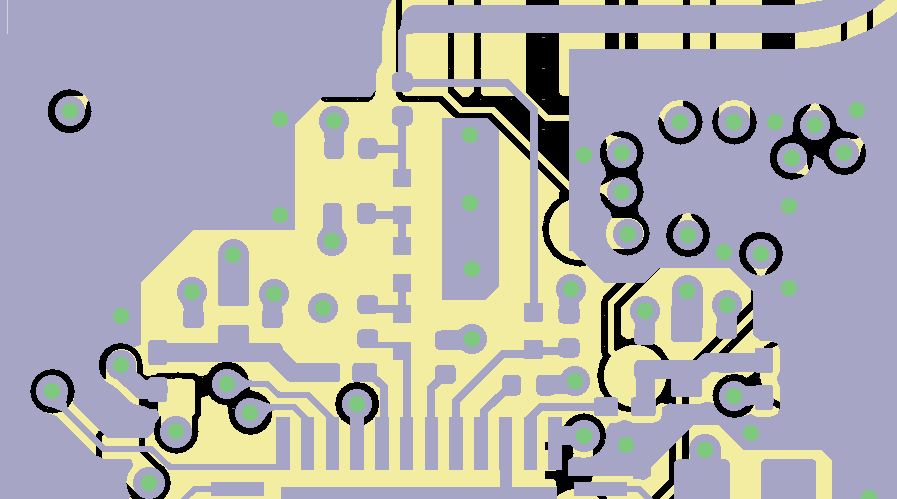
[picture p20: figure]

The RF match from the ZG23 to 50 ohms is copied from the BRD4210A +20dBm Radio Board UG507 from silabs. However, the RF components are 0201 which are basically the size of a grain of sand and really hard to manage for prototyping purposes so 0402s were used instead. Technically the RF match should be redone but Silabs does not provide a guide on how to do this.

Had to remove the battery holder as there just isn’t room on the PCB (even on the bottom) and it wouldn’t fit in the case.

The assumption is the controller version is the typical use-case for ZRADmini and not as an End Device though it can be. As an ED, it probably won’t fit in the case without more extensive drilling. The USB connector will have to be drilled out but this is easily done using an inexpensive “maker” CNC machine. If the SMA connector is desired for an antenna that would also have to be drilled out but the hope is the PCB antenna will be nearly as good.

## 2024-11-12 – ZRAD-mini concept

After range tested yesterday with TBZ boards with varying ground rod length which didn’t make a difference, the desire is to also create a ZRAD-mini PCB design that fits in an off the shelf case, PCB antenna and SMA, 2 layer PCB and is much smaller and thus cheaper.

To determine the PCB size, the main constraint is the enclosure.

- Enclosures:
  - Requirements are ~2x4x1”, PCB mounting posts, end for USB-C, tab for all mounting is a plus
  - HP-3653B (https://www.digikey.com/en/products/detail/bud-industries/HP-3653-B/2057368) – 1.023x4.165 PCB, $2.70@100 – A bit narrow but inexpensive
  - 1551UUFLGY (https://www.digikey.com/en/products/detail/hammond-manufacturing/1551UUFLGY/14556091) – 1.34x3.7 PCB, $1.88@100 – thin and has mounting tabs
  - HP-3651-B (https://www.digikey.com/en/products/detail/bud-industries/HP-3651-B/2057366) – 2.23x3.243 PCB, $2.40 – 2 flat ends easily machined for USB connector

## 2024-10-22 – GeoLocCC debug

Actually the XA1110 GPS module is buggy. It works ok as long as it remains locked to satellites after a cold start. But if it loses lock (like getting into a skydiving airplane) then it gets all confused and is unable to correct itself for some reason. It also seems to have really terrible altitude measurements. Thus, today I am trying to use the ZOE-M8Q module which uses a different GPS chip. The M8Q works so much better!

## 2024-08-06 – GeoLoc CC

GeoLoc is working well. I added an Indicator CC so the LEDs will blink on the DUT to know if it is out-of-range.

See this SparkFun (https://docs.sparkfun.com/SparkFun_RTK_Everywhere_Firmware/) page for various GPS mapping software solutions. Downloaded QGIS (https://www.qgis.org) to see if that works.

## 2024-08-05 – GeoLoc CC

See the Ubuntu laptop for more details. One interesting point is that making the temporary floating point variables on the ZG23 to be Double instead of just float didn’t seem to make any difference. I keep getting a power of 2 off somewhere. The longitude should be 70 but I keep getting 140. AHA! The problem is I was shifting the MSB by 23 instead of 24! I am now getting Longitude correctly into Z-WaveJS! Got the first Heat Map! ZwaveJS throws and unhandled error as soon as there is no ACK so I asked Dominic how to ignore those.

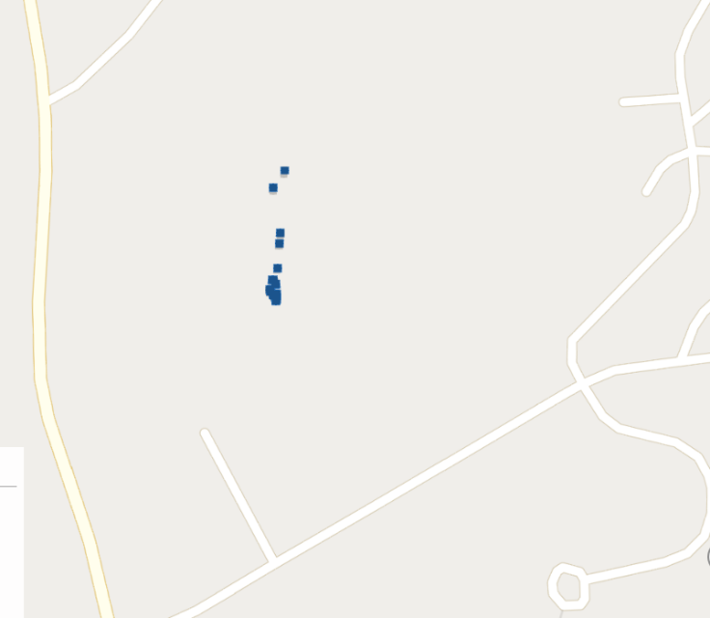
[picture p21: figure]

## 2024-07-30 – GeoLoc CC

Sidetracked on a personal project for the last several weeks but back to GeoLoc now. Sent Dominic more questions and hopefully have a call with him as I cannot figure out how/where to run the script to send GeoLoc commands.

The other option is if the SerialAPI can handle encryption for me. I’d much rather write a few lines of Python to talk to the SerialAPI and use the PCC to join devices. But I need something to handle encryption. SerialAPI can do encryption but ONLY for the end-device libraries, not as a controller. Bummer.

## 2024-07-15 – GeoLoc CC debug

Back to debugging GeoLoc CC to generate heat maps of the RF range. We also have plans to do range testing via skydiving, rocketry, and motorcycles in addition to just general neighborhood testing.

Domenic emailed me some basic instructions on setting up Z-Wave JS-UI for testing GeoLocCC. I would use the raw SerialAPI but we need to test using ZWLR which always uses Authenticated Security which is good because then we are only testing with 100% clean packets (1 corrupted bit and you cannot decrypt the message). But the SerialAPI doesn’t handle security S2 for me and it would be easier in general to use Z-Wave JS (I think). Initially I tried to get it working on my laptop but so much of Z-Wave JS relies on Linux commands (specifically in talking to the hardware) that I felt it would be easier to build a Linux laptop and use it for debug. I had an old Dell laptop just waiting for this purpose. See the ReadMe.txt file on the laptop for details on installing various software to get the system working.

I was able to have Z-Wave JS UI running in a docker, able to connect to the Controller, add a node via SmartStart. But it doesn’t retain the settings. See the ReadMe.txt for more details.

## 2024-06-11 – Trace Debug

Retesting Rev B using trace works perfectly. A 9.514MHz square wave comes out the TRACECLK pin. The only other option is that the JT2Mini board has a short on it? I don’t measure a short using a DMM. I only have 2 JT2MINIs and one has been modified for rev B. With the rev B Jt2Mini I do get the traceclk out on the wrong pins. So it’s looking like it’s the JT2Mini board. Yup – the 10 pin header on the JT2Mini had 2 pins that didn’t quite make connection down to the pads. Touch soldered and now the TRACECLK shows up on the test point and the scope but J-Trace still doesn’t see the it. So is the 20 pin connector not soldered well? Yes – that board for whatever reason must’ve had some oil or dirt on the pads and as a result didn’t make good solder joints. Fixed the solder joints. Trace is working well on Board C2. Thus, I can close out that issue. Trace complains the buffer is overflowing. See this CASE (https://community.silabs.com/s/question/0D58Y0000AWmBmUSQV/trace-overflow-detected-using-segger-jtrace-on-zg23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) for a discussion of the STALLENA bit. Setting STALLENA in MAIN works fine. Not sure why setting is via the Ozone script doesn’t stick. I filed this case (https://forum.segger.com/index.php/Thread/9495-J-Trace-unable-to-set-STALLENA-on-ARMCM33-from-Silabs-EFR32ZG23-in-JLinkScript-b/) on Segger.

Back to GeoLocCC debug and documentation. GeoLoc is replying to a GET with a REPORT. But I need a script to pull the data out and dump a .csv which can then be plotted on a map. Updated the BOM by adding individual TABs for each build type. Released ZRAD as a public repo since the hardware is done!

## 2024-06-10 – Trace debug

Checking trace debug has been fixed. Unfortunately, my first go at it with board 2 doesn’t have the trace clock coming out. The project Ozone was using was in a tight reset loop. I need to rebuild it using the current project. Still not getting anything on traceclk or TD1. TD2 is toggling. GPIO.TRACEROUTEPEN is set to 0x0E which enables the traceclk, TD0 and TD1. PA3,4,5 and Pushpull. Thought maybe the pins where shorted on board #2 so I switch to #1 but get the same result. Traceclk is low, TD1 is high, TD2 is toggling. Wiring looks fine in KiCAD. Not shorted to GND. When I use Ozone in the debugger to set traceenb to 1 the debugger fails to read 4 bytes and then has to be restarted which is why I suspected the pin might be shorted.

The TCLK and TD1 labels on J3 are backwards. The wires were corrected but the silkscreen labels were not.

## 2024-06-07 – Documentation and testing of Rev C

Updated documentation in preparation for release. Tested the 2 new Rev C PCBs.

- Board 1: Ctune=0x6a=908.4434, 0x98=908.418, 0x94=908.420
- Board 2: Ctune=0x6a=908.448, 0x98=908.420

## 2024-06-06 – Rev C PCB assembly

Built 2 Rev C boards but I’ll need to order more components to build more as I’m out of a number of things.

## 2024-05-28 – GeoLocCC

Debugging converting the NMEA sentence into binary numbers to return via the GeoLocCC. Printf does not normally support %f and has to be enabled via settings->C/C++ Build->GNU ARM C Linker-> C Library-> check the box Printf float.

Ram usage : 53056 / 65536 B ( 80.96 %)

Flash usage : 479264 / 491520 B ( 97.51 %)

With the printf float disabled:

Ram usage : 53056 / 65536 B ( 80.96 %)

Flash usage : 474128 / 491520 B ( 96.46 %)

Which is 5K just to be able to print floats! But it’s not needed except to print so leave it off except when debugging.

Seem to have it basically working. Needs more testing and some trials!

## 2024-05-23 – GeoLocCC

Tried a few random ideas – commented out the INT32_t in ZW_classcmd.h and binary switch starts working again! WTF! There are no int32s at all in ZW_classcmd.h file. Why would int32_t make the code crash? The entire file only has UINT8_T. Geo GET also returns a report so for whatever reason you can only have UINT8_T in ZW_classcmd.h! CO had no idea why but figures something must parse it and assumes everything is bytes.

## 2024-05-22 – GeoLocCC and I2C

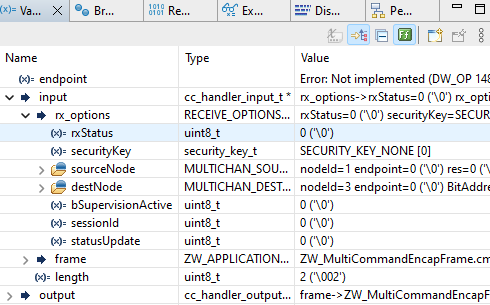
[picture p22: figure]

The suspicion is that I2CSPM is what is blowing up Z-Wave probably because it is blocking instead of being interrupt driven which means the CPU is stuck in polling loops for long periods of time. There are several ways to go about checking this: 1) setup trace and see how long it’s sitting in poll loops (already know it’s a LONG time), 2) remove I2CSPM from one of the existing projects and get the code to compile and run, 3) make a fresh install without GeoLoc, add I2CSPM and see if Basic Set crashes, 4) rewrite the I2C interface to be interrupt driven instead of polled (I suspect I’ll eventually have do this), 5) wire up the UART instead of I2C (hand soldered unreliable connection – disadvantage of not having a standardized connector). #2 is easiest to start with – just comment out the code that runs the I2C. Basic works but geoloc get has a 0xD5 in RxStatus which is bogus. Try #3: Created SwOnOff_ZG23B_ZRAD_GeoNoI2C- This project gets the 0xD5 in RxStatus so it is something in GeoLocCC. Must be an incorrect pointer to a type of some sort. Have to compare this with other CCs. Both basic and binary switch CC use REGISTER_CC_V5. Binary switch is also getting 0xD5 and thus is not responding to a Binary Switch GET. Let’s try the generic project. The generic project gets an rxStatus of 0 which is what is expected and thus returns a binary switch report. This is the good project when a breakpoint is set right at the start of CC_Binary Switch Handler.

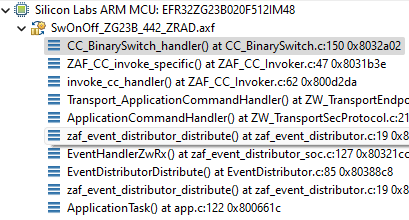
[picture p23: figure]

Net result is that the problem is in the creation of the GeoLocCC and not the I2C driver. What the problem is though is a mystery. Clearly the rx_options is filled with garbage in the broken version. But why would that break it? Is there a hardcoded limit somewhere we are exceeding? The input structure is in the AppStackBuffer (0x900 bytes) according to the MAP file.

I set a watchpoint on the address and it breaks in Transport_ApplicationCommandHandler while pulled the value from rxOpt so I set another watchpoint there. Seems that portasm.c modifies address 2000BCDx which is where the data is coming from?

## 2024-05-20 – GeoLocCC

Ongoing effort to get Geographic Location CC to work. Working in the SwOnOff_ZG23B_442_GeoCC project on Board B4. I keep getting RADIO_BOARD_EFR32ZG23=1 in the compiler preprocessor settings. I don’t see where SSv5 keeps pulling it from. I can’t factory reset the board because pressing the learn button immediately goes into the default handler. This is because PB1 is not defined. I had to use the source file (radio_no_board.c) to fix it and arbitrarily assign it to PC03. If it’s not assigned, then we get an Assert and go to the default handler. Confusing because the PB starts from 1 but the pin numbers start from 0. That got the push button to work and able to Factory Reset the board, join the network and PCC is able to control the green LED via basic on/off.

Commented out the code for zaf_event_distributor_app_zw_rx which was a hack anyway. Need to find the source of the corruption thru the proper handler. Send a GeoLoc GET and I get this out of the UART:

BuildTxAckHeader: pFrame->frame.headerLength = 0D

BuildTxSingleHeader: pFrame->frame.headerLength = 0C

BuildTxAckHeader: pFrame->frame.headerLength = 0D

But nothing relative to getting into the GeoLoc code. Note the above is for the 1st time it’s sent which it has to resync the S2 Nonce. Once synced, only get one line with the 0x0D length. No idea where this DPRINT comes from as searching for the strings doesn’t find anything. The call to DPRINTF is from ReceiveHandler() in ZW_transport.c in the library – set a breakpoint inside the library code for DebugPrintf to find it. If that’s in the library code, isn’t it always going to be executed and thus slow the code down? Can the compiler remove the library code if DEBUGPRINT is not defined?

Basic Set and Indicator CC also don’t work at all once GeoCC is added. Commenting out the GeoLoc registration doesn’t fix anything. Something else is breaking the code. So, it’s a binary search to add things 1 at a time to figure out what’s causing the SDK to go into the weeds. Could it be that one of the other interrupts is causing the failure?

Create a new SwOnOff_442_GeoCC_dbg where I’ll incrementally add things to find the cause. Followed the readme.md for ZRAD to setup the board with SwOnOff which is working non-secure. I can send a basic set to turn the LED on/off. Press the button to send Learn and DEBUGPRINTs are coming out uart.

Next step is to install GeoLocCC but I’m going to do it with GPS_ENABLED not defined and then comment out almost everything except a few printfs. No changes to ZW_classcmd.h. That works. I can send a GeoLoc GET and I get a printout from the DPRINT. So the next step would be to get it to respond by adding more stuff in. I’ll add the I2C last as maybe that’s what’s blowing it all up? I2C is blocking so maybe the CPU loses data or queues overflow? Trace might also help there.

## 2024-05-16 – Rev C PCB

Sergue at zwave.me confirmed that his zniffer is able to decode the 9 bit UART mode of the PTI module. Wired that to the CP2012 using the RX pin for the CP2015. This is just an option and at the moment is not supported but gives future possibilities. I ordered 3 Rev C PCBs.

Rev C schematic is ERC clean. The PCB has 2 excluded warnings due to footprint modifications which are OK. The footprints were slightly modified to fix other minor DRC warnings.

I want to build a small, cheap version of the board – 2 layer with PCB antenna 4”x2” which Zima says he’s had good luck with. Call it ZRAD-S for “small”. Prove out if the PCB ground plane makes a huge difference or not. Same schematic, different PCB.

## 2024-05-13 – Rev C PCB

Fixing a few errors in the Rev B PCB and adding a 2nd UART port via USB with a CP2105 as an option. Andrew Hayden mentioned they had gotten this to work. This would enable a zniffer at the same time as the SerialAPI which would provide super handy remote debugging capabilities. See Issue #5 on the repo for more details. Battery holder is backwards, the TCLK and TD1 pins are reversed and rename things to be ZRAD. Added more documentation.

Filled out a project via Screaming Circuits to see how much they would charge for a turnkey project of 25 boards - $185 per board with a 1 week turnaround without the EFR32ZG23 or the LDO (they could quote them – or we could choose another LDO). With a longer 31 day turnaround the price is down to $152 per board. They use Sunstone for PCBs which are quite expensive though even thru OSHPark the 4 layer PCB is expensive - $80 for 15 day turn or $112 for 5 days. SC Custom process has prices under $50 each. This is a complete turnkey production but doing any significant numbers are cheaper in volume (1K or more). Typically, there is a big price break at the 10K/yr production levels.

## 2024-04-26 – Railtest

David Zima is doing some RF chamber testing to determine if ZRAD can meet FCC at +20dBm TX power. He needs the Railtest commands to do it which were added to the Regulatory section above.

## 2024-04-23 – RF Range Testing

Today I will be testing mesh Z-Wave in US and EU regions at the Scammell Bridge in Dover NH. The first problem is checking that the devices are in EU region. The firmware tends to write the MFG_ZWAVE_COUNTRY_FREQ and then gets stuck there even though the firmware is set to some other region. Downloading the firmware doesn’t seem to set it unless you first erase it via commander then overwrite it. The EU Zniffer firmware in 4.4.1. and 4.4.2 doesn’t appear to work on a thunderboard. Try a DevKit?

Using my N9912 SA I confirmed that board #5 is using EU frequencies. The zniffer on a TBZ however does not appear to be. However board #5 is always blasting out at 868! Even the standard SwOnOff 442 binary file turns on the TX 100%. Interesting. Board #5 was joined to the PCC with a ZWLR NodeID. So I completely wiped the DUT and started again initially with the standard SW On Off binary. OK, now it is working normally. The key is a full wipe including the _REGION. The full wipe removes the CTUNE which is in the UD page? So it has to be reprogrammed along with the DSK.

I plugged in a devkit 548 and eventually go it into EU frequencies. Unlocked debug was not enough to clear the _REGION! I had to use the command below! Taking hours to just get devkits into EU working order. Ugh. Very difficult to tell what’s going on with the Agilent SA.

The PCC is able to switch from US_LR to EU via the SerialAPI (and back to US_LR). I built an EU zniffer and programmed a DK with a ZGM230 on it with it as a dedicated EU Zniffer. My TBZ zniffer is back to a US_LR zniffer. DK 548 has an EU SwitchOnOff demo in it.

Too late to take the equipment to the bridge for long range testing. But a quick walk thru my neighborhood and it works everywhere even around a hill. 160m thru several buildings or maybe around them?

## 2024-04-22 – RF Range Testing

The effort to add GeoLocCC has failed – see below. Using the ERTT to determine range. See the RFRangeTest.docx in the Test folder for details. Planning and some preliminary testing at the bridge in Dover NH.

Was hoping to be able to use the EK2705 chip antenna as a test but it seems it is no longer supported in SSv5.

Built an EU ZRAD but it does not talk EU because the MFG_ZWAVE_COUNTRY_FREQ is set to 9. To fix it: commander flash --tokengroup znet --token MFG_ZWAVE_COUNTRY_FREQ:0xFF

## 2024-04-20 – GeoLocCC

Transport_ApplicaitonCommandHandler in ZW_TransportEndpoint.c receives the rxStatus of 229 (0xE5). This comes from EventHandlerZwRx in zaf_event_distributor_soc.c which is where the FreeRTOS queue data is pulled from.

I was hoping that with a ZG23B the code would not still have this bug. I have no idea how to get around this now as the bug is somewhere in the SDK it would seem. Has something overflowed a stack? Obviously, something is corrupt. Need to hack something to be able to do range testing next week so for now I’ll just use the zaf_event_distributor_app_zw_rx() and put that in app.c. I can queue the REPORT but the ZAF doesn’t end up sending it I suspect because other bits in the TxOptions have invalid values and as a result the frame is not sent. Looks like the type for TxOptions_t is not the right one. This code is so squirrely – everything is renamed, repackaged, copied, swizzled, its nearly impossible to follow. The main problem is there is no API!

The ZAF_Transmit() function is the one that posts into the transmit queue QueueNotifyingSendToBack. Right now after queuing the REPORT the chip reboots obviously because an invalid pointer is passed thru the queue.

I have no idea how to fix this or even debug it. I emailed CO to see if he had any ideas.

The alternative is to code a simple app that sends a command to the hub and if it replies then record the GPS coordinates at that point. Then I don’t need to add a new command class. But time is short to make that happen. Might be easy enough to just light the green LED when a secure frame is exchanged, the blue LED when the secure frame fails but a NOP works, and red when nothing is getting thru. This is more obvious than the ERTT blinking an LED.

We’ll have to rely on the plain old ERTT for the summit unless CO can find a solution.

Oops – the battery holder footprint has + and – reversed. Added this to the Issue for Rev B.

## 2024-04-19 – GeoLocCC

Back to GeoLocCC since the ZG23B boards will require customized firmware just for B boards. I only have maybe 1 or 2 more ZG23A parts. I might have to order some. The other option is to rebuild GeoLoc for B boards since I’m unable to go any further with the current project since the SDK is giving me garbage.

1. Start with the wizard again with SwOnOff but with the ZG23B connected via Wstk2 mini simplicity header and board #5
2. Configure RF Region for ZWLR
3. SwOnOff project fails to build due to APP_BUTTON_A and LED not being defined. This is caused by the compiler setting the Preprocessor symbol RADIO_BOARD_EFR32ZG23=1. Note that RADIO_NO_BOARD is also set. Delete the RADIO_BOARD_EFR32ZG23 symbol and the project builds and runs (sitting in the WFI instruction).
4. Install DebugPrint as described in the ZRAD ReadMe.md
5. Configure LEDs/Buttons
6. Join the DUT to a controller – basic On/Off toggles the green LED
7. Install I2CSPM for QWIIC interface
  a. Basic set still works
  b. I had to remove the RADIO_BOARD_EFR32ZG23 again
8. Follow the instructions in the Geographic Location ReadMe.md
  a. Edit ZW_ClassCmd.h file and soft link the files
  b. Had to remove RADIO_BOARD_EFR32ZG23 again
9. The SDK is still giving me garbage – the rxStatus has an 0xE5 in it which the code then thinks it is a multicast frame so it’s dropped.

I ordered 2 more GPS boards – 1 XA1110 and a slightly more expensive one to see if it has more accuracy. Sparkfun has a board that’s $179.95 that they claim is accurate to within 24mm! I also ordered 2 more Tag-Connect debug cables as they seem to disappear! I also ordered more antennas to have pairs of the same one. Unfortunately, the 868 recommended antenna is backordered and not expected until July! Must do EU with the less expensive antenna which were in stock.

Tested and CTUNEd board #3. Shipped it and a bare board to David Zima for testing.

## 2024-04-18 – ZG23B debug

The 3 new boards I built yesterday don’t run the firmware but get stuck in some sort of reset loop. I rewired an ETM_ZWAVE adaptor board to fix the Trace debugging wiring mistake on the ZRAD (easier to rewire a 2 layer PCB than the 4 layer ZRAD board). Trace is working fine but it’s not easy to find the failure as the trace overflows. The task switch goes to a RAILINT which then unpacks a long list of stacked functions so I suspect there is a stack overflow somewhere. Single stepping with Trace tends to cause a hardfault accessing peripherals for some reason.

I get:

OnTraceStart() end - Took 5.22ms

LTRACE (Time since start: 0.112 578, Thread=ETM4): Trace overflow detected. Trace packets may have been lost.

For more information on how to avoid overflows see the following article: https://wiki.segger.com/J-Trace_overflow_error

Debug.Halt();

From Ozone with Trace enabled. Seems like the CPU might not have STALLENA enabled? I went thru this before with Segger and tried to get an answer from the Silabs CPU group but they had no idea. The Wiki page suggests: TRACE_SetEnableStalling = 1 but it’s not a command. I recall that when Trace is enabled this is set by default (maybe?).

This Community (https://community.silabs.com/s/question/0D58Y0000AWmBmUSQV/trace-overflow-detected-using-segger-jtrace-on-zg23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) page asks the question is the STALLENA feature available in HW? The only other option is to prescale the CPU clock by 2 to slow it down to reduce the amount of trace data. Another option is to lower the CPU clock. The xG23 RM shows that the ETM is from SYSCLK but the CPU is based on HCLK so it should be possible to lower the clock speed by powers of 2.

Reduce the CPU clock speed and then trace does not overflow. But the clock speed isn’t sticky as the CPU overwrites the clock register on occasion. Add these lines to the JLINK script:

U32 CMU_SYSCLKCTRL;

CMU_SYSCLKCTRL = CMU_BASE + 0x070;

JLINK_MEM_WriteU32(CMU_SYSCLKCTRL, 0x03001);

JLINK_SYS_Report1("CMU_SYSCLKCTRL: ", JLINK_MEM_ReadU32(CMU_SYSCLKCTRL));

But it does seem to prevent overrunning trace.

The problem remains that it seems like the stack is overflowing somewhere.

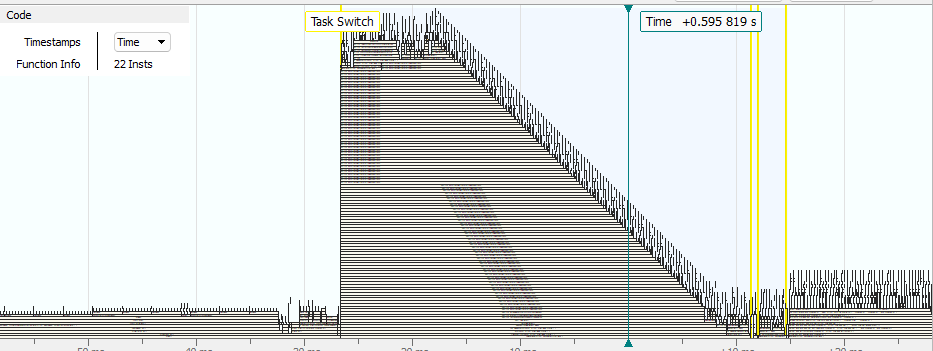
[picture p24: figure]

The task switches to a huge stack of RAIL interrupts it seems. .text.RAILINT_6433f1eb5ac17efd72f74a695e677e55 which all return but you would think that would cause stack overflows. This function is executed during startup inside of ZW_RadioPhyInit(). When I break at function e55 I get different trace results:

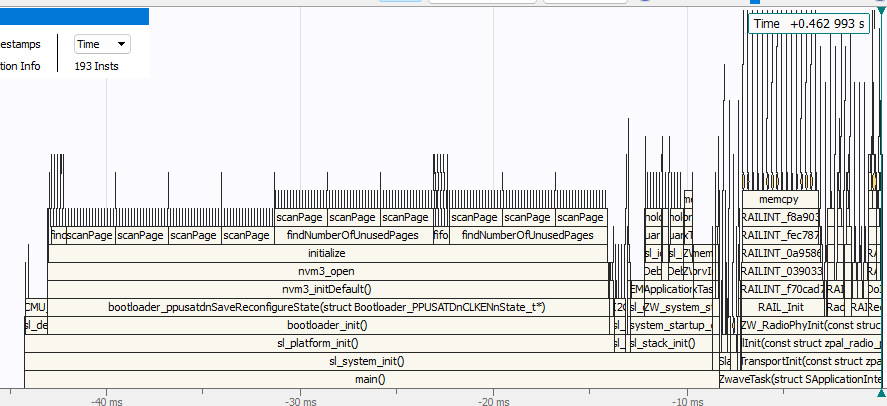
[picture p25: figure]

Note we are inside ZW_RadioPhyInit and everything is OK. No task switch and crazy stack. Trying to step thru the code from here ends up getting back thru reset at 0x0800170 which is the bootloader first instruction after the vector table. I suspect we’re actually underflowing the stack which is why Ozone thinks the stack is so deep.

Unfortunately, Trace isn’t providing me much help here as something is completely messed up. Well the good thing is that running the A code on a B devkit does exactly the same thing! So it seems code compiled for an A part will NOT run on a B part! I need to make a copy of the project and change the target to a B part. This also means I can use a devkit with trace with all 4 pins. Maybe that will give me more info? I also don’t have time to debug this!

I built SwOnOff using a B devkit. Then changed the target board to Custom Board and the part to an EFR32ZG23A and that project runs on a B part just fine. So, it’s not the fact that it’s an A build on a B part at least for the off-the-shelf SwOnOff. I enabled debugprint and set to US_LR were the only customizations. The same code runs OK on my new boards so it’s not something special about the board it would seem. Nope, it works because the B is still listed as a symbol. So, switching the “target” in the Properties isn’t a valid way of switching the target as it doesn’t change the target (which is also a SSv5 bug). I used the .SLCP file to change the target. Then the project doesn’t compile because all the GPIOs and EUSART settings were lost. Ugh.

One more try of running A firmware on a B part. Start with a RB4202D in a WSTK (ZG23B). In My Products of the Launcher perspective select an EFR32ZG23A010F512IM48 part. Select the GSDK 4.4.2 SDK. New->NewProjectWizard, Next, Select Z-Wave then the SwitchOnOff project and CREATE it and name it SwOnOff_ZG23A_441_runsonB. Click on Build – it should build OK. Click on the bug icon to download it and run it. It will run to main, but it then gets stuck in a reset loop forever. Click on Pause and the code should be sitting at the WFI instruction in EM1 waiting for something to do. Instead the code is often in a RAILINT doing a RequestIRCalibration() or waiting for the BURTC to sync or one of the other longer startup routines. If you then enable DEBUGPRINT (which requires some effort to enable the USART and assign the Ios) you will see it prints out just a few lines and then resets over and over again. I entered this case (https://community.silabs.com/s/question/0D5Vm000008YhPxKAK/code-compiled-for-zg23a-does-not-run-on-a-zg23b). Seems when you create a project it loads a RADIO_BOARD_EFR32ZG21=1 as a Setting in Project Properties which might be what is blocking LED/Buttons.

## 2024-04-17 – GeoLocCC & 3 more boards

Call with Christian Salmony-Olsen to get Geographic Location CC V2 installed in a sample project.

- How to implement a new command class (https://docs.silabs.com/z-wave/7.21.1/zwave-api/md-content-how-to-implement-a-new-command-class) on docs.silabs.com
  - Is a bit light on details but is a good start
- Linker Magic is the trick for adding CC to the NIF. Linux does this sort of thing which is where the concept came from
- All CO could suggest is look at what is coming in from the queue and there might be a bug in the SDK
- I did share GeoCC with CO and he will try implementing in the Trident stack

Join the GeoCC version classic without any keys. Still doesn’t turn the LED on via Basic. But the DPRINTs do say the command is supported. Sending a GeoLoc works! So at least I can get the GeoLoc debugged then figure out what the problem is with security later. ZWLR requires security so it will have to work eventually. But it doesn’t return the report. CO stated I just had to make the length non-zero and ZAF would send it. The reason it doesn’t send is because the rxStatus is 0xE5 which fails the is_multicast function RECEIVE_STATUS_TYPE_BROAD (0x04) so my code drops the frame. Obviously the rxStatus has garbage in it as E5 is an invalid value. Tracing that back to the xQueueZwRx and it is giving me 0xE5 so garbage coming from the SDK. I emailed CO asking what I do next.

Meanwhile I built 3 more boards. Board #5 removed about ½ the solder under the ZG23 EP so it would be less likely to lift seemed to help. But board 3 and 4 have the ZG23 down tight to the PCB even with all the solder paste. On all 3 boards I scraped off the excess paste to have just the thickness of the mylar and pressed the ZG23 down firmly. Much less solder shorts in general. None on the CP2102. Boards 3-5 cycle thru eResetReason 7 quickly – a few hundred ms so its not the watchdog. They do print out messages. Board #3-5 have ZG23B. They have SE firmware 2.1.7 – Updated to 2.2.4 but that made no difference.

I tried to single step to find what’s causing the reset but it’s something after the init routines when FreeRTOS starts up. So I tried to setup trace but the J-Trace is not showing any target power. Loose connection. Now have power but trace isn’t capturing. The TRACECLK is only 2.3MHz which is way lower than it should be. That’s because D2 is the traceclk since it’s at 10mhz. The board has the tracelk and D2 backwards. So, no trace until Rev C. I entered an Issue to fix that. The PCB is hard to rework since the trace layer is on an inner layer and not the bottom. I could rework an ETM adapter board but even that is pretty hard to do. I may go there if nothing else works.
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

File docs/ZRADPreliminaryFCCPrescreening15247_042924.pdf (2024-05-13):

31355 Bear Pond Drive | PHONE:
Sorrento, FL 32776 | EMAIL:
| WEB:


# FCC PART 15.247 902-928 MHz DTS TEST REPORT

APPLICANT | Click or tap here to enter text.
ADDRESS | Click or tap here to enter text.
PRODUCT MODEL NUMBER | Click or tap here to enter text.
PRODUCT DESCRIPTION | Click or tap here to enter text.
FCC ID | Click or tap here to enter text.
DATE SAMPLE RECEIVED | Click or tap here to enter text.
FINAL TEST DATE | Click or tap here to enter text.
TESTED BY | Click or tap here to enter text.
APROVED BY | ☐ PASS ☐ FAIL
Report Number | Report Version | Description | Issue Date
Click or tap here to enter text. | Click or tap here to enter text. | Click or tap here to enter text. | Click or tap here to enter text.

# THE ATTACHED REPORT SHALL NOT BE REPRODUCED EXCEPT IN FULL WITHOUT THE WRITTEN APPROVAL OF RF LABORATORIES, INC

# 31355 Bear Pond Drive Sorrento, FL 32776 USA

Ph.: 352.444.9806

# Email: purchasing@rflab.com Website: www.rflab.com

# RF LABORATORIES, INC

# Applicant: FCC ID:

Report: | Page 2 of 14

# Table of Contents

DTS Bandwidth | Error! Bookmark not defined.
Test Data: DTS Bandwidth Measurement Table | Error! Bookmark not defined.
Test Data: DTS Bandwidth, 915 MHz | Error! Bookmark not defined.
AUTHORIZED BANDEDGE EMISSIONS | Error! Bookmark not defined.
Test Data: Lower Band Edge Plot | Error! Bookmark not defined.
Test Data: Upper Band Edge Plot | Error! Bookmark not defined.
CONDUCTED SPURIOUS EMISSIONS | Error! Bookmark not defined.
Test Data: 915 MHz | Error! Bookmark not defined.
TEST EQUIPMENT LIST | Error! Bookmark not defined.

# Applicant:

# General Remarks

# Summary

# The device under test does:

# ☐ Fulfill the general approval requirements as identified in this test report and was

selected by the customer.

# ☐ Not fulfill the general approval requirements as identified in this test report

# Attestations
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

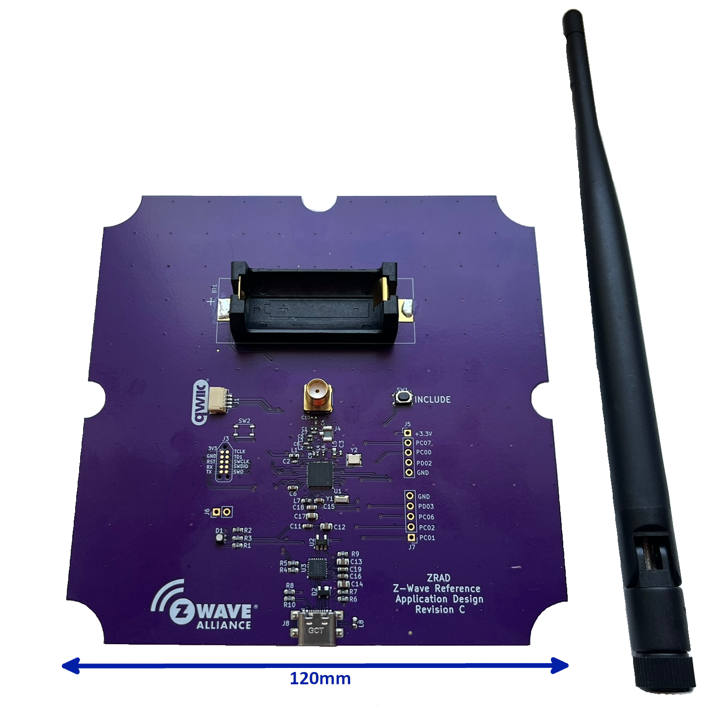
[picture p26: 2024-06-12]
docs/ZRAD2024.png

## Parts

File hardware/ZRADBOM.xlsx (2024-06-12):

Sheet: Introduction
Bill of material for the Z-Wave Alliance Reference Application Design (ZRAD)
There are individual tabs for each optional build of ZRAD.
The FULLBOM tab has every possible component included. The other tabs then select only the parts needed for that option.
Typically do a Save-As of the desired tab as VALUES ONLY either as an .XLSX or .CSV file.
Then upload it to various prototype service shops such as Screaming Circuits. |  | https://www.screamingcircuits.com/
Typically they don't have the ZG23 and possibly a few other components which you will have to procure and ship to the proto house.
Costs are for information only and are simply the distributor cost at 1k quantities. Actual costs will depend heavily on volume.
The Test Jig BOM is for the Test Jig which has not been designed yet…
History:
2024-02-16 | Initial file creation
2024-04-24 | Updated with more details and cost analysis
2024-06-12 | Created individual tabs for the different builds

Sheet: FULLBOM
Item # | Mfg Part # | Manufacturer | Description | RefDes | Digikey # | Qty | Cost Each | Cost Total | On Hand | To be ordered | Alternate | Comments
1 | EFR32ZG23B020F512GM48 (https://www.silabs.com/wireless/z-wave/800-series-modem-soc/device.efr32zg23b020f512im48) | Silicon Labs | Z-Wave MCU/Radio | U1 | 634-ZG2320F512GM48CR | 1 | $4.85 | $4.85 | 5 | 5 |  | 10 | Number of board to be built
2 | CP2102N-A02-GQFN24R | Silicon Labs | USB2.0 UART | U3 | 336-5888-1-ND‎ | 1 | $2.34 | $2.34 | 5 | 5 |  |  |  | Cost Analysis pie chart:
3 | AP2127K-3.3 | Diodes Inc | LDO 3.3V SOT23-5 | U2 | AP2127K-3.3TRG1DICT-ND (https://www.digikey.com/en/products/detail/diodes-incorporated/AP2127K-3-3TRG1/4470786) | 1 | $0.10 | $0.10 | 6 | 4 |  |  |  | Item | Cost
4 | ECS-390-12-33B2-CKM-TR3 (https://www.digikey.com/en/products/detail/ecs-inc/ECS-390-12-33B2-CKM-TR3/21725258) | ECS | 39Mhz Crystal 10ppm | Y2 | 50-ECS-390-12-33B2-CKM-TR3CT-ND (https://www.digikey.com/en/products/detail/ecs-inc/ECS-390-12-33B2-CKM-TR3/21725258) | 1 | $0.34 | $0.34 | 6 | 4 |  | ED=End Device vs. Controller |  | Z-Wave MCU/Radio | $4.85
5 | GRM1555C2A221JE01D | Murata | Cap 220pF 0402 | C2,C3,C7 | 490-GRM1555C2A221JE01DTR-ND | 3 | $0.01 | $0.01 | 15 | 15 |  | ED does not need USB or LDO |  | USB2.0 UART | $2.34
6 | GRT188R71E105KE13D (https://www.digikey.com/en/products/detail/murata-electronics/GRT188R71E105KE13D/10694256) | Murata | Cap 1uF 0603 X7R 25v | C6,C15,C18 | 490-GRT188R71E105KE13DTR-ND | 3 | $0.03 | $0.09 | 25 | 5 |  |  |  | Antenna | $2.54
7 | GJM1555C1H1R9BB01D (https://www.digikey.com/en/products/detail/murata-electronics/GJM1555C1H1R9BB01D/2592905) | Murata | Cap 1.9pF 0402 C0G NP0 | C9 | 490-GJM1555C1H1R9BB01DTR-ND | 1 | $0.02 | $0.02 | 40 | -30 |  |  |  | Bare PCB | $1.00
8 | GJM1555C1H470FB01D (https://www.digikey.com/en/products/detail/murata-electronics/GJM1555C1H470FB01D/7363120) | Murata | Cap 47pF 0402 C0G NP0 | C4 | 490-16376-2-ND | 1 | $0.03 | $0.03 | 40 | -30 |  |  |  | SMA Verticle | $1.22
9 | GJM1555C1H7R2BB01D (https://www.digikey.com/en/products/detail/murata-electronics/GJM1555C1H7R2BB01D/2593116) | Murata | Cap 7.2pF 0402 C0G NP0 | C8 | 490-GJM1555C1H7R2BB01DTR-ND | 1 | $0.02 | $0.02 | 0 | 10 |  |  |  | MISC | $2.71
10 | GJM1555C1H1R3BB01D (https://www.digikey.com/en/products/detail/murata-electronics/GJM1555C1H1R3BB01D/2592879) | Murata | Cap 1.3pF 0402 C0G NP0 | C5 | 490-8086-2-ND | 1 | $0.03 | $0.03 | 15 | -5 |  |  |  | Total | $14.66
11 | GRM21BR71C475KE51L (https://www.digikey.com/en/products/detail/murata-electronics/GRM21BR71C475KE51L/6606095) | Murata | Cap 4.7uF 0805 X7R | C12,C13,C14,C17 | 490-14466-2-ND | 4 | $0.03 | $0.12 | 60 | -20
12 | GCM188L81H104KA57D (https://www.digikey.com/en/products/detail/murata-electronics/GCM188L81H104KA57D/2591908) | Murata | Cap 100nF 0603 X7R | C11,C16,C19 | 490-6049-2-ND | 3 | $0.03 | $0.09 | 20 | 10
13 | SP0503BAHTG | LittleFuse | TVS Diode USB | D2 | F2715TR-ND | 1 | $0.36 | $0.36 | 12 | -2
14 | QLSP14RGB_B | Quelighting | RGB LED | D1 | 3970-QLSP14RGB_BTR-ND | 1 | $0.09 | $0.09 | 18 | -8 |  | Optional - mostly for ED
15 | USB4110-GF-A | GCT | USB Recepticle | J8 | 2073-USB4110-GF-A-2-ND | 1 | $0.75 | $0.75 | 6 | 4
16 | RF2-04A-T-00-50-G | Adam Tech | SMA Verticle | J2 | 2057-RF2-04A-T-00-50-G-ND | 1 | $1.22 | $1.22 | 6 | 4
17 | SM04B-SRSS-TB | JST | QWIIC connector | J1 | 455-SM04B-SRSS-TBTR-ND | 0 | $0.31 | $0.00 | 3 | -3 |  | Optional - mostly for ED only
18 | LQG15HN18NH02D | Murata | Ind 18nH 0402 3% | L6 | 490-15066-2-ND | 1 | $0.03 | $0.03 | 10 | 0
19 | LQG15HS1N5S02D | Murata | Ind 1.5nH 0402 | L4 | 490-2612-2-ND | 1 | $0.02 | $0.02 | 15 | -5
20 | LQG15HS1N3S02D | Murata | Ind 1.3nH 0402 | L2 | 490-6568-2-ND | 1 | $0.02 | $0.02 | 15 | -5
21 | LQG15WZ13NJ02D | Murata | Ind 13nH 0402 | L3 | 490-15250-2-ND | 1 | $0.05 | $0.05 | 10 | 0
22 | LQM18PN2R2MFRL | Murata | Ind 2.2uH 0603 | L7 | 490-10764-2-ND | 1 | $0.09 | $0.09 | 10 | 0
23 | BLM18PG330SN1D | Murata | Ferrite 33@100mhz 0603 | L1,L5,L8 | 490-5220-2-ND | 3 | $0.03 | $0.09 | 20 | 10
24 | RC0603FR-075K1L | Yageo | Res 5.1K ohm 0603 1% | R8,R10 | 311-5.10KHRTR-ND | 2 | $0.01 | $0.01 | 20 | 0
25 | RC0603FR-07100RL | Yageo | Res 100 ohm 0603 1% | R4,R5 | 311-100HRTR-ND | 2 | $0.01 | $0.01 | 40 | -20
26 | RC0603FR-0722K1L | Yageo | Res 22.1K ohm 0603 1% | R7 | 311-22.1KHRTR-ND | 1 | $0.01 | $0.01 | 40 | -30
27 | RC0603FR-0747K5L | Yageo | Res 47.5K ohm 0603 1% | R6 | 311-47.5KHRTR-ND | 1 | $0.01 | $0.01 | 45 | -35
28 | RC0603FR-071K2L | Yageo | Res 1.2K ohm 0603 1% | R2 | 311-1.20KHRTR-ND | 1 | $0.01 | $0.01 | 30 | -20
29 | RC0603FR-071KL | Yageo | Res 1.0K ohm 0603 1% | R3,R9 | 311-1.00KHRTR-ND | 2 | $0.01 | $0.01 | 30 | -10
30 | RC0603FR-07820RL | Yageo | Res 820 ohm 0603 1% | R1 | 311-820HRTR-ND | 1 | $0.01 | $0.01 | 40 | -30
31 | PTS810 SJM 250 SMTR LFS | C&K | SPST-NO switch | SW1 | CKN10502TR-ND | 1 | $0.30 | $0.30 | 0 | 10 |  | For ED
32 | SC32S-7PF20PPM | Seiko | 32.768KHz crystal | Y1 | 728-1074-2-ND | 0 | $0.20 | $0.00 | 10 | -10 |  | For ED if using time CC
33 | 1050 | Keystone | CR123A Battery holder | BT1 | 36-1050-ND | 0 | $2.51 | $0.00 | 1 | -1 |  | Expensive but prevents reverse battery insertion which is not protected by circuitry
34 | OSHPark.com |  | Bare PCB |  |  | 1 | $1.00 | $1.00 |  |  |  | Cost estimate is assuming panelized PCB
35 | JCG402LR-2 |  | Antenna |  | JCG402LR-2 (https://www.digikey.com/en/products/detail/jc-antenna/JCG402LR-2/15814458) | 1 | $2.54 | $2.54 |  |  |  | Low cost recommended antenna - there are several more expensive ones
36 |  |  | Enclosure
37 |  |  | USB Cable
38 |  |  | Packaging
39 |  |  |  |  | TOTAL COST: |  |  | $14.66 |  |  |  | Total cost is for a controller @1K qty with distributor pricing from Digikey
40 |  |  |  |  |  |  |  |  |  |  |  | Your cost could be significantly lower depending on volume
41 |  |  |  |  |  |  |  |  |  |  |  | Component cost ONLY and does not include assembly, testing or packaging

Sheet: USB Controller
Item # | Mfg Part # | Manufacturer | Description | RefDes | Digikey # | Qty
1 | EFR32ZG23B020F512GM48 | Silicon Labs | Z-Wave MCU/Radio | U1 | 634-ZG2320F512GM48CR | 1
2 | CP2102N-A02-GQFN24R | Silicon Labs | USB2.0 UART | U3 | 336-5888-1-ND‎ | 1 | USB Controller
3 | AP2127K-3.3 | Diodes Inc | LDO 3.3V SOT23-5 | U2 | AP2127K-3.3TRG1DICT-ND | 1
4 | ECS-390-12-33B2-CKM-TR3 | ECS | 39Mhz Crystal 10ppm | Y2 | 50-ECS-390-12-33B2-CKM-TR3CT-ND | 1
5 | GRM1555C2A221JE01D | Murata | Cap 220pF 0402 | C2,C3,C7 | 490-GRM1555C2A221JE01DTR-ND | 3
6 | GRT188R71E105KE13D | Murata | Cap 1uF 0603 X7R 25v | C6,C15,C18 | 490-GRT188R71E105KE13DTR-ND | 3
7 | GJM1555C1H1R9BB01D | Murata | Cap 1.9pF 0402 C0G NP0 | C9 | 490-GJM1555C1H1R9BB01DTR-ND | 1
8 | GJM1555C1H470FB01D | Murata | Cap 47pF 0402 C0G NP0 | C4 | 490-16376-2-ND | 1
9 | GJM1555C1H7R2BB01D | Murata | Cap 7.2pF 0402 C0G NP0 | C8 | 490-GJM1555C1H7R2BB01DTR-ND | 1
10 | GJM1555C1H1R3BB01D | Murata | Cap 1.3pF 0402 C0G NP0 | C5 | 490-8086-2-ND | 1
11 | GRM21BR71C475KE51L | Murata | Cap 4.7uF 0805 X7R | C12,C13,C14,C17 | 490-14466-2-ND | 4
12 | GCM188L81H104KA57D | Murata | Cap 100nF 0603 X7R | C11,C16,C19 | 490-6049-2-ND | 3
13 | SP0503BAHTG | LittleFuse | TVS Diode USB | D2 | F2715TR-ND | 1
14 | QLSP14RGB_B | Quelighting | RGB LED | D1 | 3970-QLSP14RGB_BTR-ND | 0
15 | USB4110-GF-A | GCT | USB Recepticle | J8 | 2073-USB4110-GF-A-2-ND | 1
16 | RF2-04A-T-00-50-G | Adam Tech | SMA Verticle | J2 | 2057-RF2-04A-T-00-50-G-ND | 1
17 | SM04B-SRSS-TB | JST | QWIIC connector | J1 | 455-SM04B-SRSS-TBTR-ND | 0
18 | LQG15HN18NH02D | Murata | Ind 18nH 0402 3% | L6 | 490-15066-2-ND | 1
19 | LQG15HS1N5S02D | Murata | Ind 1.5nH 0402 | L4 | 490-2612-2-ND | 1
20 | LQG15HS1N3S02D | Murata | Ind 1.3nH 0402 | L2 | 490-6568-2-ND | 1
21 | LQG15WZ13NJ02D | Murata | Ind 13nH 0402 | L3 | 490-15250-2-ND | 1
22 | LQM18PN2R2MFRL | Murata | Ind 2.2uH 0603 | L7 | 490-10764-2-ND | 1
23 | BLM18PG330SN1D | Murata | Ferrite 33@100mhz 0603 | L1,L5,L8 | 490-5220-2-ND | 3
24 | RC0603FR-075K1L | Yageo | Res 5.1K ohm 0603 1% | R8,R10 | 311-5.10KHRTR-ND | 2
25 | RC0603FR-07100RL | Yageo | Res 100 ohm 0603 1% | R4,R5 | 311-100HRTR-ND | 2
26 | RC0603FR-0722K1L | Yageo | Res 22.1K ohm 0603 1% | R7 | 311-22.1KHRTR-ND | 1
27 | RC0603FR-0747K5L | Yageo | Res 47.5K ohm 0603 1% | R6 | 311-47.5KHRTR-ND | 1
28 | RC0603FR-071K2L | Yageo | Res 1.2K ohm 0603 1% | R2 | 311-1.20KHRTR-ND | 1
29 | RC0603FR-071KL | Yageo | Res 1.0K ohm 0603 1% | R3,R9 | 311-1.00KHRTR-ND | 2
30 | RC0603FR-07820RL | Yageo | Res 820 ohm 0603 1% | R1 | 311-820HRTR-ND | 1
31 | PTS810 SJM 250 SMTR LFS | C&K | SPST-NO switch | SW1 | CKN10502TR-ND | 1
32 | SC32S-7PF20PPM | Seiko | 32.768KHz crystal | Y1 | 728-1074-2-ND | 0
33 | 1050 | Keystone | CR123A Battery holder | BT1 | 36-1050-ND | 0
34 | OSHPark.com | 0 | Bare PCB | 0 | 0 | 1
35 | JCG402LR-2 | 0 | Antenna | 0 | JCG402LR-2 | 1
36 | 0 | 0 | Enclosure | 0 | 0 | 0
37 | 0 | 0 | USB Cable | 0 | 0 | 0
38 | 0 | 0 | Packaging | 0 | 0 | 0

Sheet: USB End Device
Item # | Mfg Part # | Manufacturer | Description | RefDes | Digikey # | Qty
1 | EFR32ZG23B020F512GM48 | Silicon Labs | Z-Wave MCU/Radio | U1 | 634-ZG2320F512GM48CR | 1
2 | CP2102N-A02-GQFN24R | Silicon Labs | USB2.0 UART | U3 | 336-5888-1-ND‎ | 1 | Always On USB powered End Device
3 | AP2127K-3.3 | Diodes Inc | LDO 3.3V SOT23-5 | U2 | AP2127K-3.3TRG1DICT-ND | 1
4 | ECS-390-12-33B2-CKM-TR3 | ECS | 39Mhz Crystal 10ppm | Y2 | 50-ECS-390-12-33B2-CKM-TR3CT-ND | 1
5 | GRM1555C2A221JE01D | Murata | Cap 220pF 0402 | C2,C3,C7 | 490-GRM1555C2A221JE01DTR-ND | 3
6 | GRT188R71E105KE13D | Murata | Cap 1uF 0603 X7R 25v | C6,C15,C18 | 490-GRT188R71E105KE13DTR-ND | 3
7 | GJM1555C1H1R9BB01D | Murata | Cap 1.9pF 0402 C0G NP0 | C9 | 490-GJM1555C1H1R9BB01DTR-ND | 1
8 | GJM1555C1H470FB01D | Murata | Cap 47pF 0402 C0G NP0 | C4 | 490-16376-2-ND | 1
9 | GJM1555C1H7R2BB01D | Murata | Cap 7.2pF 0402 C0G NP0 | C8 | 490-GJM1555C1H7R2BB01DTR-ND | 1
10 | GJM1555C1H1R3BB01D | Murata | Cap 1.3pF 0402 C0G NP0 | C5 | 490-8086-2-ND | 1
11 | GRM21BR71C475KE51L | Murata | Cap 4.7uF 0805 X7R | C12,C13,C14,C17 | 490-14466-2-ND | 4
12 | GCM188L81H104KA57D | Murata | Cap 100nF 0603 X7R | C11,C16,C19 | 490-6049-2-ND | 3
13 | SP0503BAHTG | LittleFuse | TVS Diode USB | D2 | F2715TR-ND | 1
14 | QLSP14RGB_B | Quelighting | RGB LED | D1 | 3970-QLSP14RGB_BTR-ND | 1
15 | USB4110-GF-A | GCT | USB Recepticle | J8 | 2073-USB4110-GF-A-2-ND | 1
16 | RF2-04A-T-00-50-G | Adam Tech | SMA Verticle | J2 | 2057-RF2-04A-T-00-50-G-ND | 1
17 | SM04B-SRSS-TB | JST | QWIIC connector | J1 | 455-SM04B-SRSS-TBTR-ND | 1
18 | LQG15HN18NH02D | Murata | Ind 18nH 0402 3% | L6 | 490-15066-2-ND | 1
19 | LQG15HS1N5S02D | Murata | Ind 1.5nH 0402 | L4 | 490-2612-2-ND | 1
20 | LQG15HS1N3S02D | Murata | Ind 1.3nH 0402 | L2 | 490-6568-2-ND | 1
21 | LQG15WZ13NJ02D | Murata | Ind 13nH 0402 | L3 | 490-15250-2-ND | 1
22 | LQM18PN2R2MFRL | Murata | Ind 2.2uH 0603 | L7 | 490-10764-2-ND | 1
23 | BLM18PG330SN1D | Murata | Ferrite 33@100mhz 0603 | L1,L5,L8 | 490-5220-2-ND | 3
24 | RC0603FR-075K1L | Yageo | Res 5.1K ohm 0603 1% | R8,R10 | 311-5.10KHRTR-ND | 2
25 | RC0603FR-07100RL | Yageo | Res 100 ohm 0603 1% | R4,R5 | 311-100HRTR-ND | 2
26 | RC0603FR-0722K1L | Yageo | Res 22.1K ohm 0603 1% | R7 | 311-22.1KHRTR-ND | 1
27 | RC0603FR-0747K5L | Yageo | Res 47.5K ohm 0603 1% | R6 | 311-47.5KHRTR-ND | 1
28 | RC0603FR-071K2L | Yageo | Res 1.2K ohm 0603 1% | R2 | 311-1.20KHRTR-ND | 1
29 | RC0603FR-071KL | Yageo | Res 1.0K ohm 0603 1% | R3,R9 | 311-1.00KHRTR-ND | 2
30 | RC0603FR-07820RL | Yageo | Res 820 ohm 0603 1% | R1 | 311-820HRTR-ND | 1
31 | PTS810 SJM 250 SMTR LFS | C&K | SPST-NO switch | SW1 | CKN10502TR-ND | 1
32 | SC32S-7PF20PPM | Seiko | 32.768KHz crystal | Y1 | 728-1074-2-ND | 1 | Optional
33 | 1050 | Keystone | CR123A Battery holder | BT1 | 36-1050-ND | 0
34 | OSHPark.com | 0 | Bare PCB | 0 | 0 | 1
35 | JCG402LR-2 | 0 | Antenna | 0 | JCG402LR-2 | 1
36 | 0 | 0 | Enclosure | 0 | 0 | 0
37 | 0 | 0 | USB Cable | 0 | 0 | 0
38 | 0 | 0 | Packaging | 0 | 0 | 0

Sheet: Battery End Device
Item # | Mfg Part # | Manufacturer | Description | RefDes | Digikey # | Qty
1 | EFR32ZG23B020F512GM48 | Silicon Labs | Z-Wave MCU/Radio | U1 | 634-ZG2320F512GM48CR | 1
2 | CP2102N-A02-GQFN24R | Silicon Labs | USB2.0 UART | U3 | 336-5888-1-ND‎ | 0 | Battery Powered End Device - USB is depopulated
3 | AP2127K-3.3 | Diodes Inc | LDO 3.3V SOT23-5 | U2 | AP2127K-3.3TRG1DICT-ND | 0 | CR123A directly powers the 3.3V domain
4 | ECS-390-12-33B2-CKM-TR3 | ECS | 39Mhz Crystal 10ppm | Y2 | 50-ECS-390-12-33B2-CKM-TR3CT-ND | 1
5 | GRM1555C2A221JE01D | Murata | Cap 220pF 0402 | C2,C3,C7 | 490-GRM1555C2A221JE01DTR-ND | 3
6 | GRT188R71E105KE13D | Murata | Cap 1uF 0603 X7R 25v | C6,C15,C18 | 490-GRT188R71E105KE13DTR-ND | 3
7 | GJM1555C1H1R9BB01D | Murata | Cap 1.9pF 0402 C0G NP0 | C9 | 490-GJM1555C1H1R9BB01DTR-ND | 1
8 | GJM1555C1H470FB01D | Murata | Cap 47pF 0402 C0G NP0 | C4 | 490-16376-2-ND | 1
9 | GJM1555C1H7R2BB01D | Murata | Cap 7.2pF 0402 C0G NP0 | C8 | 490-GJM1555C1H7R2BB01DTR-ND | 1
10 | GJM1555C1H1R3BB01D | Murata | Cap 1.3pF 0402 C0G NP0 | C5 | 490-8086-2-ND | 1
11 | GRM21BR71C475KE51L | Murata | Cap 4.7uF 0805 X7R | C17 | 490-14466-2-ND | 1
12 | GCM188L81H104KA57D | Murata | Cap 100nF 0603 X7R | C11,C16,C19 | 490-6049-2-ND | 0
13 | SP0503BAHTG | LittleFuse | TVS Diode USB | D2 | F2715TR-ND | 0
14 | QLSP14RGB_B | Quelighting | RGB LED | D1 | 3970-QLSP14RGB_BTR-ND | 1
15 | USB4110-GF-A | GCT | USB Recepticle | J8 | 2073-USB4110-GF-A-2-ND | 0
16 | RF2-04A-T-00-50-G | Adam Tech | SMA Verticle | J2 | 2057-RF2-04A-T-00-50-G-ND | 1
17 | SM04B-SRSS-TB | JST | QWIIC connector | J1 | 455-SM04B-SRSS-TBTR-ND | 1
18 | LQG15HN18NH02D | Murata | Ind 18nH 0402 3% | L6 | 490-15066-2-ND | 1
19 | LQG15HS1N5S02D | Murata | Ind 1.5nH 0402 | L4 | 490-2612-2-ND | 1
20 | LQG15HS1N3S02D | Murata | Ind 1.3nH 0402 | L2 | 490-6568-2-ND | 1
21 | LQG15WZ13NJ02D | Murata | Ind 13nH 0402 | L3 | 490-15250-2-ND | 1
22 | LQM18PN2R2MFRL | Murata | Ind 2.2uH 0603 | L7 | 490-10764-2-ND | 1
23 | BLM18PG330SN1D | Murata | Ferrite 33@100mhz 0603 | L1,L5,L8 | 490-5220-2-ND | 3
24 | RC0603FR-075K1L | Yageo | Res 5.1K ohm 0603 1% | R8,R10 | 311-5.10KHRTR-ND | 0
25 | RC0603FR-07100RL | Yageo | Res 100 ohm 0603 1% | R4,R5 | 311-100HRTR-ND | 0
26 | RC0603FR-0722K1L | Yageo | Res 22.1K ohm 0603 1% | R7 | 311-22.1KHRTR-ND | 0
27 | RC0603FR-0747K5L | Yageo | Res 47.5K ohm 0603 1% | R6 | 311-47.5KHRTR-ND | 0
28 | RC0603FR-071K2L | Yageo | Res 1.2K ohm 0603 1% | R2 | 311-1.20KHRTR-ND | 1
29 | RC0603FR-071KL | Yageo | Res 1.0K ohm 0603 1% | R3 | 311-1.00KHRTR-ND | 1
30 | RC0603FR-07820RL | Yageo | Res 820 ohm 0603 1% | R1 | 311-820HRTR-ND | 1
31 | PTS810 SJM 250 SMTR LFS | C&K | SPST-NO switch | SW1 | CKN10502TR-ND | 1
32 | SC32S-7PF20PPM | Seiko | 32.768KHz crystal | Y1 | 728-1074-2-ND | 1 | Optional
33 | 1050 | Keystone | CR123A Battery holder | BT1 | 36-1050-ND | 1
34 | OSHPark.com | 0 | Bare PCB | 0 | 0 | 1
35 | JCG402LR-2 | 0 | Antenna | 0 | JCG402LR-2 | 1
36 | 0 | 0 | Enclosure | 0 | 0 | 0
37 | 0 | 0 | USB Cable | 0 | 0 | 0
38 | 0 | 0 | Packaging | 0 | 0 | 0

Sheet: Test Jig
Item # | Mfg Part # | Manufacturer | Description | Qty | Cost Each | Cost Total | On Hand | To be ordered | Comments
1 |  |  | 3D Printed Jig and hold downs | 2 |  | $0.00 |  |  | Jig STL files are in the 3D folder
2 |  |  | Wood base | 1 |  | $0.00 |  |  | Or other material, roughly 28"x12"
3 | 3418 | PeachTree Woodworking (https://www.ptreeusa.com/ttrack_toggles.html) | Toggle Clamp | 2 | $10.99 | $21.98
4 | TC2050-IDC-NL-050-ALL (https://www.tag-connect.com/product/tc2050-idc-nl-050-all) | Tag-Connect | Tag-Connect 10 pin 050 cable normal orientation | 2 | $59.00 | $118.00
5
6
7
8
9
10
11
12
13
14
 | The Test Jig is used to program and test assembled ZRAD boards.
 | This is a work-in-progress and has not yet been stated in June 2024

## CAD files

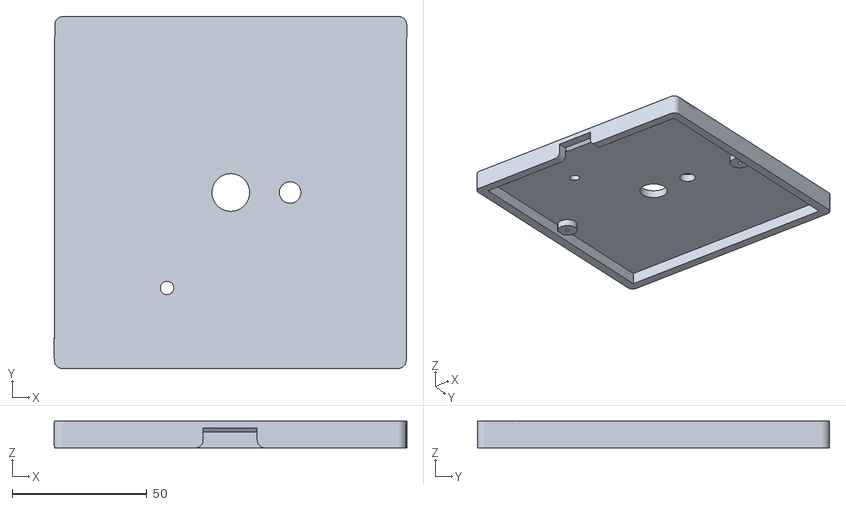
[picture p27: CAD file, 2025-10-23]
3D/ZRAD.stl
130.6 x 130.4 x 10.0

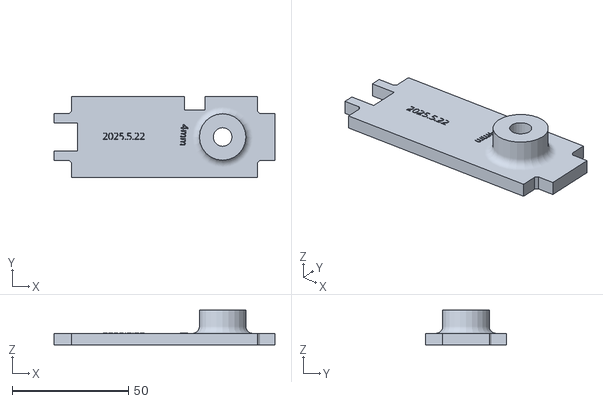
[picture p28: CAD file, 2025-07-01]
3D/ZRADBaseDrillJig.stl
95.0 x 35.0 x 15.0

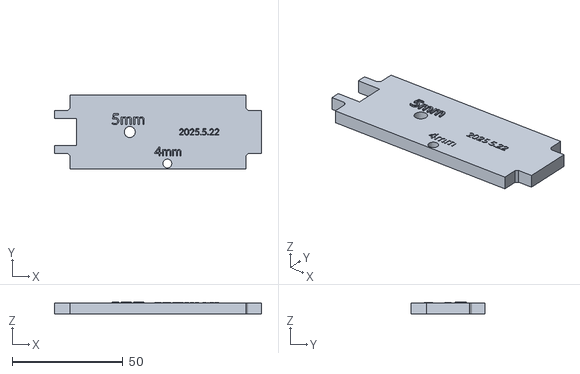
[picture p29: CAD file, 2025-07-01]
3D/ZRADTopDrillJig.stl
93.5 x 33.5 x 5.50

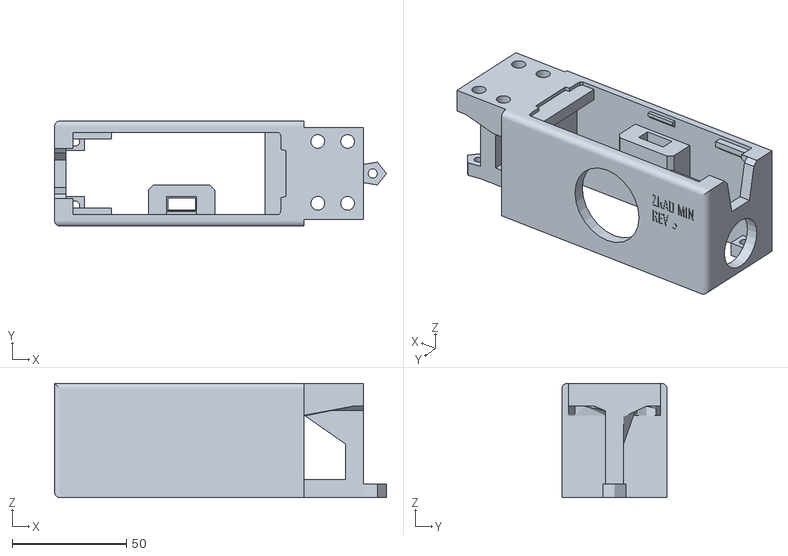
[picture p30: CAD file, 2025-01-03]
3D/ZRADMiniJig.stl
145.0 x 46.0 x 50.0

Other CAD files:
3D/ZRADMiniJig.skp

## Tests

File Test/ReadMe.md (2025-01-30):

# ZRAD Test Folder

This folder contains various test scripts for ZRAD/ZRADmini.

The RangeTesting folder has a number of scripts, data and results of RF Range Testing of ZRAD and ZRADmini. See the [ReadMe.md](./RangeTesting/ReadMe.md) for more details.

# New Board Bring Up Procedure

Once a PCB has been fully assembled, use this procedure to ensure it is fully functional.
This is a manual procedure if the test jig system is not available (see below).

1. Connect a WSTK to J3 using a Tag-Connect connector
2. Ensure the WSTK is set to Mini and the power switch is set to AEM
    - WSTK will then power the DUT via the Tag-Connect connector
3. Open Commander and connect to the WSTK
4. Click on Device Info
    - If the debug cable is working, the Chip Type and SE version will be displayed
    - If not, then check the power supplies or look for shorts/opens on the ZG23
5. Click on Flash
6. Select the RailTest file in the software directory and FLASH the DUT
7. Open the Serial 1 console in SSv5 to the WSTK or open PuTTY
8. Press Enter - type "reset" which will print the Railtest version information
9. Follow the crystal calibration procedure in the main [README.md](../README.md)
10. Update the SE if needed using Simplicity Studio, Flash the Bootloader OTA and a sample application
11. commander device reset (or power cycle the DUT)
12. Extract the DSK and add it to the PCC
    - Print the QR code label to apply to the PCB
11. Test the application by joining a network and observing the RSSI on Zniffer
11. Send basic on/off which should toggle the green LED
11. Press the LEARN button which should send a NIF and blink the blue LED
12. Unplug from WSTK
13. Plug in via USB and verify the board is functional - LEDs toggle with basic On/Off
14. Open PuTTY and observe the DEBUGPRINT from the sample app
16. Test other optional features like the QWIIC connector, the GPIOs, LEDs other applications

# Test Jig System

A 3D printed test jig and associated scripts provides a complete manufacturing flow for ZRADmini. 
Typically two jigs are connected to one computer enabling the test operator to load 1 DUT into one jig while the other jig is programming/testing. See the comments within the scripts for additional details on each step of the process.

The following hardware is required to build a ZRADmini Test Sytem:
    - [TinySA](https://www.tinysa.org/wiki/) Spectrum Analyzer
    - Raspberry Pi, keyboard, monitor & mouse
    - Zebra ZD400 label printer and labels
    - 2 3D Printed jigs from the 3D directory above
    - 2 Tag-Connect cables
    - 2 WSTK Silabs Devkit boards
    - 2 clamps
    - Mounting Plate
    - USB Cables and a USB hub

## Manufacturing Flow Scripts

- ZRADCalProgTest.py
    - This is the main script with a command line interface (CLI) that enables the operator to Calibrate, Program and Test each DUT yielding a PASS/FAIL
    - The operator merely presses ENTER, then place a fresh DUT in the other jig while the first one completes programming & testing
    - The CLI has other commands to run individual steps of the manufacturing flow for debugging
    - Note that this script has a minimal number of functional tests and real production should extend the testing for higher confidence in each DUT being fully functional
    - This script then calls the following scripts as needed
- ZG23CrystalCal.py
    - Calibrates the 39MHz crystal utilizing the TinySA spectrum analyzer
    - Relies on the tinySA scripts in the tinySA folder
- TinySA folder
    - Utilities from TinySA to control the Spectrum Analyzer 
- SmartStartQR.py
    - Generates the QR code from the DSK computed by the DUT and optionally prints it on a Zebra printer
    - Requires customization based on the needs of your products labels
    - Prints 2 labels for each DUT
        - Product label must be on the DUT enclosure itself
        - Packaging label is typically applied to the outside packaging

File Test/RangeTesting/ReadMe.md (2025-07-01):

# ZRAD RF Range Testing Folder

There are word files and some raw data files of various range tests done with ZRAD in this folder.
The script to generate most of the data is the ZWJSRangeTest.js file which requires the following procedure to run:

1. Use either a Windows or Linux laptop (windows described here but Linux is similar)
    - install either a bash shell or WSL or use PowerShell
    - install [node.js](https://nodejs.org/en/download)
2. Connected at least one End Device with a GPS receiver and Geographic Location CC v2 and up to 3 other nodes
3. Use Z-Wave JS UI to add/remove nodes using QR codes and/or reset the controller
    - Or use the PC Controller from Silabs 
        - note! copy the Keys from ZWJSRangeTest.js into the PCC Security tab 
4. ```npm install zwave-js``` will install zwave-js into this directory
5. ```node ZWJSRangeTest.js [COMx]``` starts Z-Wave JS with many messages scrolling quickly
    - The nodes are interviewed each time the script is run
    - If something fails, try rerunning the script and the interview should complete ok
6. If the Node with Geographic Location CC v2 is working you should get something similar to:
    - ```Lat= 43.170780539512634 Lon= -70.87131237983704 alt= 34.5 Sats= 7```
    - Then you know the test is running
    - ZWJS prints out all sorts of information on the signal quality
7. ```tail -f geoloc.csv``` will show the GPS points as they are being captured
8. Use the Zniffer to watch the Z-Wave traffic
9. Move the GeoLoc DUT until it is no longer making connection, then return
    - Need one person watching ZWJS and another person to walk the DUT down the field
10. When finished, ctl-C ZWJS to end the session
11. Generate Maps as described below

# Generating Maps from the GeoLocation Data

Geographic Location Command Class V2 was added to the specification to aide in tracking the RF range of Z-Wave Long Range devices.
The ZWJSRangeTest.js script along with Z-Wave JS and Node.js will poll DUTs for their current GPS location and store it along with other interesting data into the geoloc.csv file.
There are many ways to then visualize the data but Microsoft Excel has a simple tool to view the data which is described below.

## Microsoft Excel 3D Maps

Microsoft has a [Get Started](https://support.microsoft.com/en-us/office/get-started-with-3d-maps-6b56a50d-3c3e-4a9e-a527-eea62a387030) guide to enable and then use 3D maps which is part of Excel.
There are also plenty of YouTube videos on the topic.

1. Open Excel - open the geoloc.csv file
2. File - Save As - save as geoloc.xlsx
    - 3D Maps won't be enabled until after you convert the csv file to a workbook
3. There are many types of 3D Maps you can produce which visualize the data in different ways
    - If you have a single Z-Wave Node with GeoLoc you can plot the data and display the TxPower as height or color
    - If you have other nodes also included and want to display all of them on 1 map, a few additions to the xlsx are needed
        - Jump to the Multiple Nodes Map if you have data in this form
        - Or, if you have mutiple data and want to see just one node, sort the sheet by the NodeID and select only that Nodes data

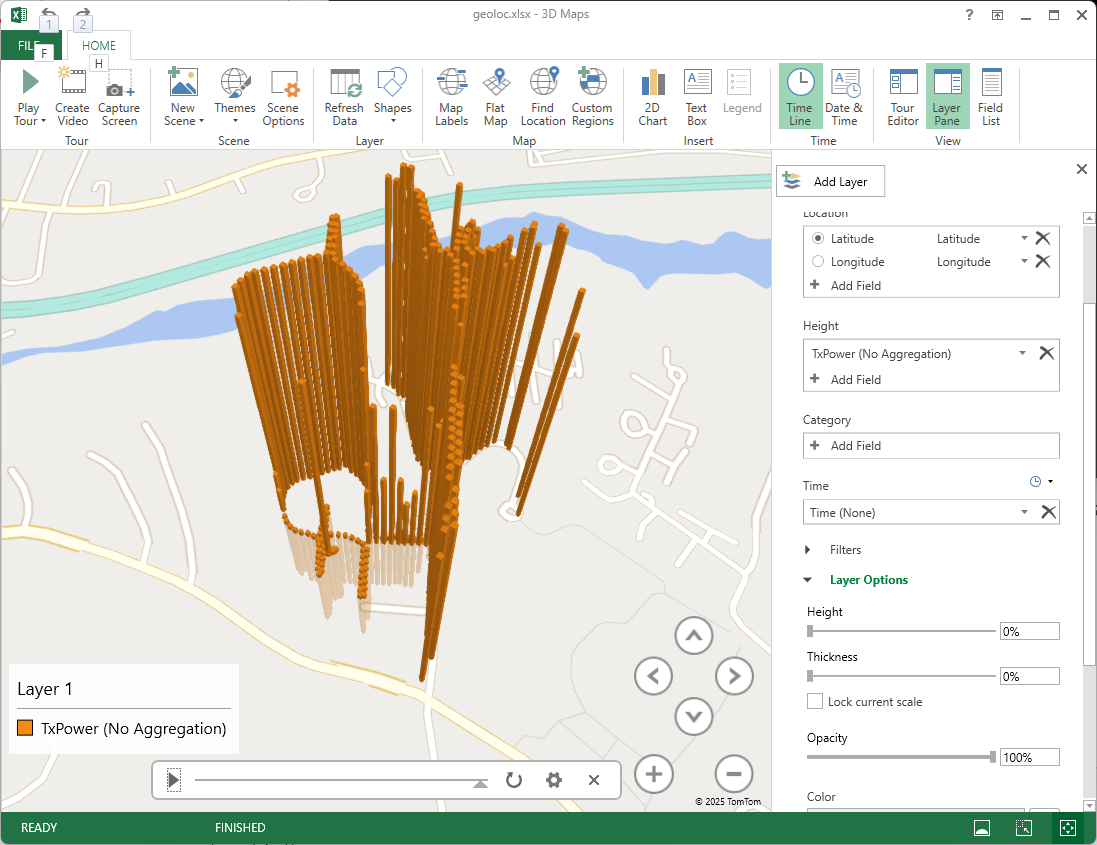
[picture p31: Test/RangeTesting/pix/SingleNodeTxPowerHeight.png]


4. **Simple Single Node Map:**
5. Select the data - the Time thru the RSSI columns - include the header row!
6. Open 3D Maps and choose a New Tour
7. Drag the Latitude and Longitude to the Location box if not already there
8. Select TxPower for the Height
    - Select No Aggregation
9. Select the Time field for Time
    - The enables a slider across the bottom so you can make a video of the path
10. Zoom up
11. Select the Layer Option
    - Set HEIGHT to 0%
    - Set THICKNESS to 0%
12. Use the mouse/arrow buttons to adjust the view as you like
13. The height of the bars shows the transmit power - when close to the controller TxPower will be -6dBm and when distant will be +20 (in US)
    - The height still seems too high even at 0% - maybe pre-scaling the values in the worksheet will make them smaller?
14. Update the Layer name - add any other annotations such as the location of the controller

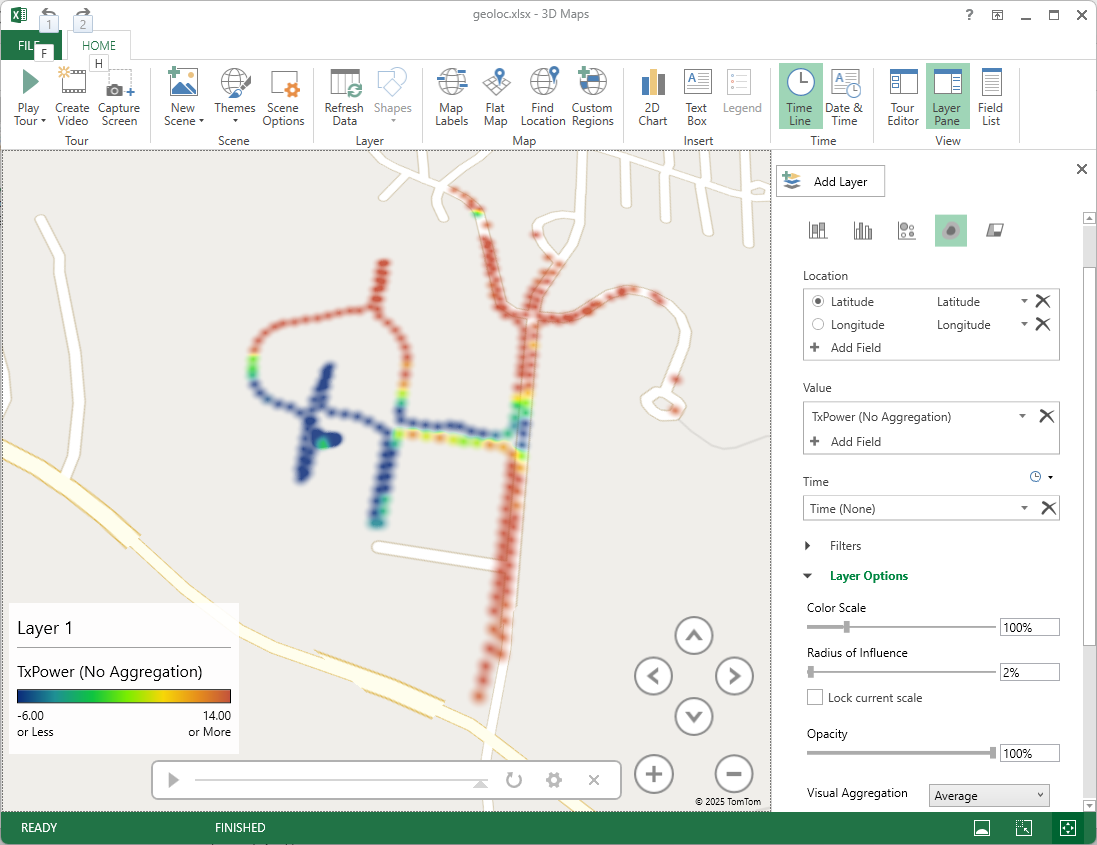
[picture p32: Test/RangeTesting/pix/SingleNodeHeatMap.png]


15. Try other Themes and other data formats or colors - there are a lot of options
16. Take a screenshot or click on Capture Screen or Create Video
16. Try the Heat Map option (4th icon from the left at the top of the Data toolbar)
    - TxPower as the Value (No Aggregation)
    - Reduce the Radius of Influence to 0%
    - Visual Aggregation to Average
    - This map is flat and the colors represent the TxPower as shown in the legend
10. **Multiple Nodes Map:**
11. Capturing the data from multiple nodes enables a comparison of the RF range of each node on a single map
12. First a few modifications to the .XLSX data is required

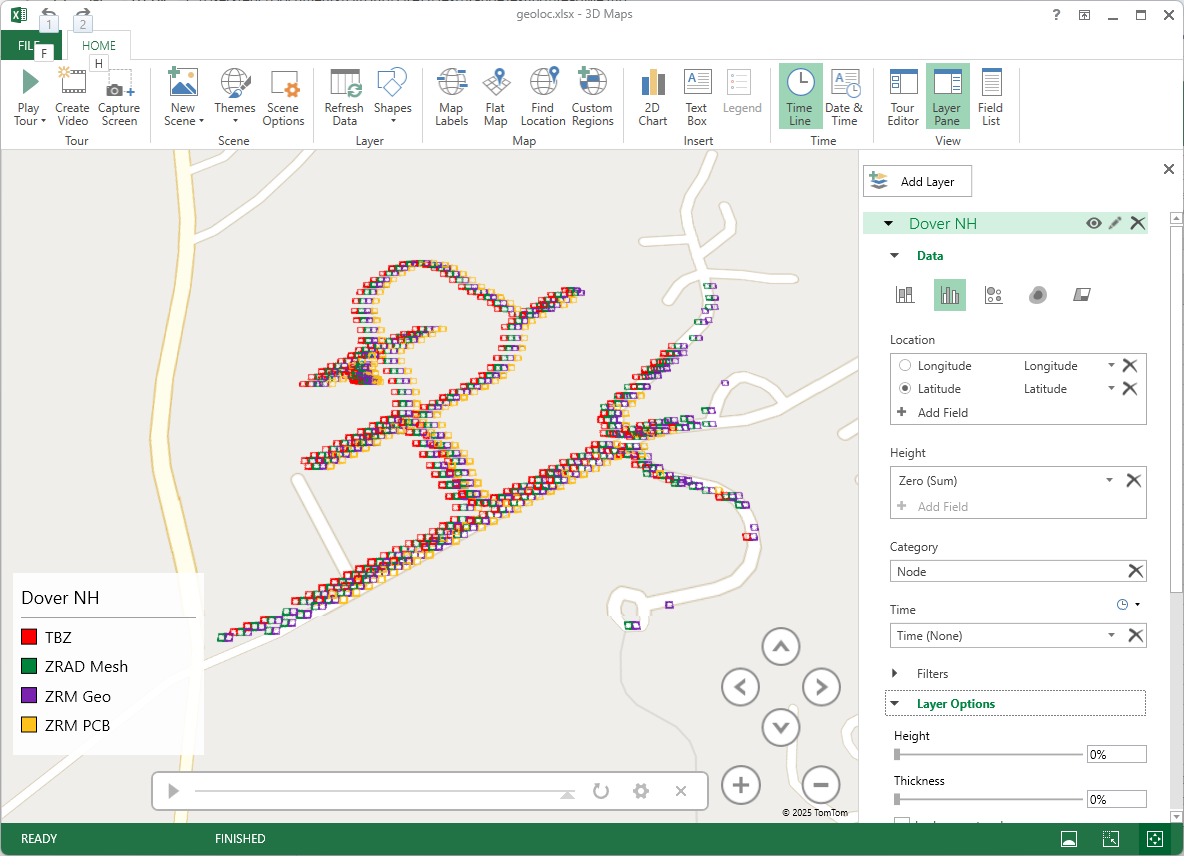
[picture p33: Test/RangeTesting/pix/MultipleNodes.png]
[](./pix/MultipleNodes.png)

13. Insert 2 columns to the right of the NodeID 
14. In the first column just added, paste the following formula:
    - ```=IF(G2=5,"ZRAD Mesh",IF(G2=261,"ZRM Geo",IF(G2=260,"TBZ","ZRM PCB")))```
    - Which requires modification to match your setup
    - Replace the NodeID and the matching device name to the number and strings in the formula
15. Drag the formula down for the entire column
    - Use ```<CTL>Down Arrow``` to go to the last entry in a column
16. Fill the 2nd column with Zeroes (0) and make row 1 be "Zero"
    - This field is a workaround to make the height zero otherwise the map is too complex to visualize
16. SAVE THE FILE OUT, make a copy to add the 3D maps graphics
    - Once the .XLSX has a 3D map in it, it seems to forever be screwed up and you must start from scratch
17. Select the Clustered Column map at the top of the Data menu (2nd icon from the left)
17. Select the HEIGHT to be the Zero Column
18. Select the Node Column in the Category
19. Then change the Thickness to be 4% to make the square small enough to not overlap
19. You should get a map similar to the one shown here
    - The ZRM Geo is the ZRADMini node with GeoLocCCv2 in it (purple) which has the best range
20. **Other Options**
    - For skydiving or rocketry use the Altitude for the Height

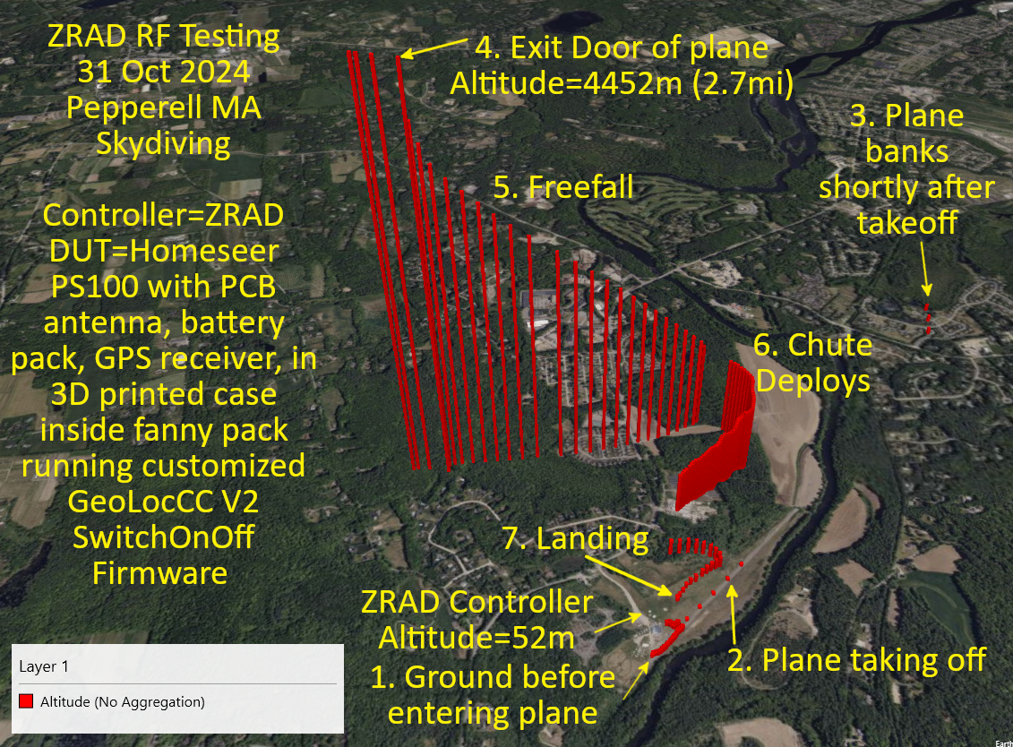
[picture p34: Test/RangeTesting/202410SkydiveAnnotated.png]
skydiving


## Other 3D Mapping Tools

There are lots of other GPS visualization tools some of which you have to pay for. 
Below are a few that have been experimented with briefly without too much real investigation. 
If you find a better tool, let DrZWave know!

- Google Earth will plot the data easily but you only get the data points without other data
- Google maps is not able to import GPS data
- [GPS Visualizer](https://www.gpsvisualizer.com/) - Popular tool for viewing tracks
- [Viking](https://sourceforge.net/projects/viking/) - Open Source tool

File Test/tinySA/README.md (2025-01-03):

# Control tinySA using a python script

tinySA can be controlled via the USB serial interface from a PC. Here are some examples.

## Preparation

    $ cd python
    $ pip3 install -r requirements.txt

## Run

### Plot default scan.

    $ ./tinySA.py -p

### Capture display

    $ ./tinySA.py -C out.png

### Show usage.

    $ ./tinySA.py -h

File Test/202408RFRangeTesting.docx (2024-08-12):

# August 2024 Z-Wave RF Range Testing

# Executive Summary

Coming once the testing is complete

# Goals

- ZRAD to ZRAD ZWLR RF range testing in various environments generating a Heat Map using Geographic Location Command Class and a GPS receiver
- ZRAD End Device Mounted on a Motorcycle to move around quickly
  - Some data may be captured using an eBike or walking especially in urban environments
- ZRAD Controller running Z-Wave JS to pull GPS locations and store in a .CSV file
- 2 videos – 1 ~3min short at WW, longer ~5 min YouTube
- Environments:
  - Wooded
    - Bound (https://www.google.com/maps/place/BoundTree%2FLine+Hill+Parking/@43.2080352,-71.7716687,280) Tree ATV Henniker NH
    - Rockingham trail (https://www.nhstateparks.org/find-parks-trails/recreational-rail-trails/rockingham-recreational-rail-trail,-fremont-branch) Freemont to Sandown
    - Hopkington-Everet OHRV (https://www.google.com/maps/place/Hopkinton-Everett+OHRV+Trails+Area/@43.1239432,-71.6538497,1887) trails
  - Open agricultural field
    - Wagon Hill Durham NH (not quite big enough?)
  - Green houses?
  - Residential
    - Newton MA
    - Dover NH
  - Urban
    - Boston Silabs Office
      - Do the windows have metal tinting with poor RF?
      - Can we get on the roof? Probably not
      - Use the top floor of the NECCO parking deck?
    - Dover NH
      - Controller on top of the Garrison Hill tower (https://www.google.com/maps/place/Garrison+Hill+Tower,+Abbey+Sawyer+Memorial+Hwy,+Dover,+NH+03820/@43.2094265,-70.8704013,333) which has line-of-sight to much of Dover below for several miles and plenty of urban streets
        - Too many trees – do not use
      - Can drive & park at the base of the tower
      - Trial on 8/10 did not go well. Too many trees surrounding the tower results in few if any pings even on the road just below the tower. Only time it connects is line-of-sight which is rare at ground level.
    - Strafford NH
      - The Stratham Hill Tower (https://www.google.com/maps/place/Stratham+Hill+Tower/@43.0312354,-70.8911063,3178) is an alternative but doesn’t have as many streets nearby
      - Requires a hike up the hill to get to the tower
  - Water – need a boat – lakes or the ocean depending on the weather
- At some point:
- Use ZRAD to capture GPS, but also capture stats of other devices
  - Use Indicator Get? ZWInfo Get? Needs to be a secure GET to know frame made both directions clean
  - ZW mesh with ZRAD
  - Commercial products
    - Ring
    - Zooz light switch? Blink xmas lights all over the bike and night Electric Cowboy style!
      - Need a large battery and inverter – Jackery?
    - 3Labs flow meter
- Compare with Wifi, Zigbee, Matter, Lora, others?
  - 2.4 protocols in urban environments will probably suck due to all the noise
- Compare with YAGI antenna – point-to-point
- Example use-cases
  - Track skydiving jump (Homeseer)
  - Track model rocket launch
  - Track glacier movement for months at a time (need low-power)

# Journal

## 2024-08-10 – Dover Garrison Hill Tower

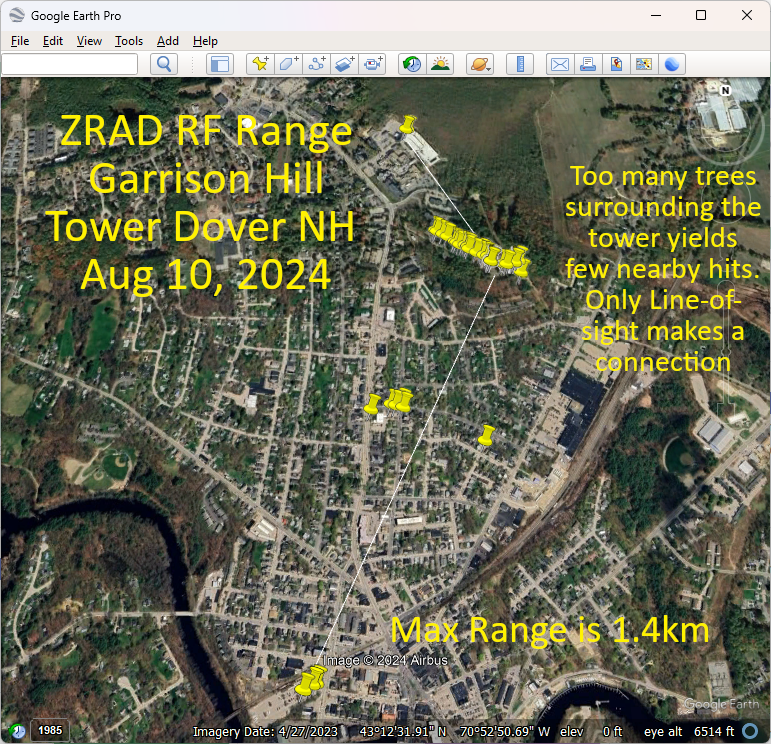
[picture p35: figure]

Trial run at the Garrison Hill tower which has a commanding view of the city of Dover NH. The problem is the tower is surrounded with a thick forest which from the top of the tower you can just see over the tops of the trees. This means there are no connections made to the streets immediately below the tower thru all the trees. The few line-of-sight locations in the city will connect at over 1.4km but there are few of these at ground level. Lots of 3 story buildings and more trees block the LoS.

Download Google Earth Pro which can import the .csv file and display it on a map and take measurements. Note that the online version of Google Earth does NOT have the feature to import a .csv file. This does not appear to import the altitude, just Lat/Lon. Tried a few CSV to KML conversion utilities but GE still doesn’t seem to how the altitude.

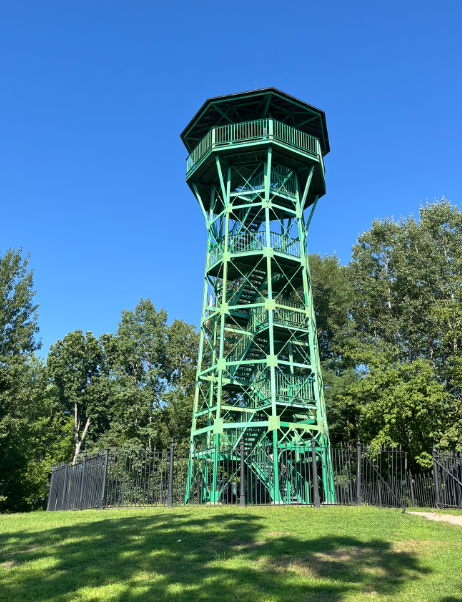
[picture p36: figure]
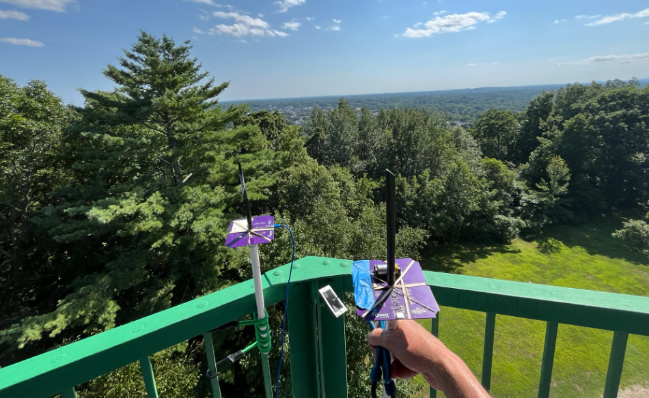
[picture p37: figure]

Still looking for a mapping solution that will produce a 3D model for skydiving or rocketry that shows the altitude.

Raw data:

Time, Latitude, Longitude, Altitude, TxPower, RSSI, Sat Aug 10 2024 15:19:13 GMT-0400 (Eastern Daylight Time)

03:19:13 PM, 43.20914840698242, -70.8693618774414, 182.85, 0, 0

03:19:13 PM, 43.20912551879883, -70.86934661865234, 182.85, 0, 0

03:19:13 PM, 43.2091064453125, -70.86935424804688, 182.85, 0, 0

03:19:13 PM, 43.209556579589844, -70.8694076538086, 110.76, 0, 0

03:19:13 PM, 43.20950698852539, -70.86963653564453, 112.66, 0, 0

03:19:13 PM, 43.20948028564453, -70.86962127685547, 112.71, 0, 0

03:19:13 PM, 43.20952224731445, -70.86958312988281, 112.74, 0, 0

03:19:13 PM, 43.209510803222656, -70.86959075927734, 112.79, 0, 0

03:19:13 PM, 43.209510803222656, -70.86959075927734, 112.79, 0, 0

03:19:13 PM, 43.20949172973633, -70.86959075927734, 112.79, 0, 0

03:19:13 PM, 43.20949172973633, -70.86958312988281, 112.79, 0, 0

03:19:13 PM, 43.20948028564453, -70.86958312988281, 112.92, 0, 0

03:19:13 PM, 43.20948028564453, -70.86958312988281, 113.18, 0, 0

03:19:13 PM, 43.20948028564453, -70.86957550048828, 113.33, 0, 0

03:19:13 PM, 43.20948028564453, -70.86957550048828, 113.33, 0, 0

03:19:13 PM, 43.2094841003418, -70.86957550048828, 113.57, 0, 0

03:19:13 PM, 43.20949935913086, -70.86959075927734, 114.15, 0, 0

03:19:13 PM, 43.209503173828125, -70.86958312988281, 114.19, 0, 0

03:19:13 PM, 43.209495544433594, -70.86959075927734, 114.23, 0, 0

03:19:13 PM, 43.20949935913086, -70.86959075927734, 114.26, 0, 0

03:19:13 PM, 43.20949935913086, -70.86959075927734, 114.27, 0, 0

03:19:13 PM, 43.209495544433594, -70.86959838867188, 114.39, 0, 0

03:19:13 PM, 43.20949935913086, -70.86959838867188, 114.4, 0, 0

03:19:13 PM, 43.209495544433594, -70.86959838867188, 114.44, 0, 0

03:19:13 PM, 43.20949935913086, -70.86959075927734, 114.23, 0, 0

03:19:13 PM, 43.209503173828125, -70.8696060180664, 114.28, 0, 0

03:19:13 PM, 43.20951843261719, -70.86962127685547, 114.25, 0, 0

03:19:13 PM, 43.20949172973633, -70.86962890625, 114.39, 0, 0

03:19:13 PM, 43.20949172973633, -70.86962890625, 114.46, 0, 0

03:19:13 PM, 43.20948791503906, -70.86962890625, 114.72, 0, 0

03:19:13 PM, 43.20948791503906, -70.86962890625, 114.76, 0, 0

03:19:13 PM, 43.20949172973633, -70.86962890625, 114.76, 0, 0

03:19:13 PM, 43.209495544433594, -70.86962890625, 114.22, 0, 0

03:19:13 PM, 43.209495544433594, -70.86962127685547, 114.05, 0, 0

03:19:13 PM, 43.209495544433594, -70.86961364746094, 114.02, 0, 0

03:19:13 PM, 43.209495544433594, -70.8696060180664, 114.01, 0, 0

03:19:13 PM, 43.209495544433594, -70.8696060180664, 114.28, 0, 0

03:19:13 PM, 43.209495544433594, -70.8696060180664, 114.37, 0, 0

03:19:13 PM, 43.20949935913086, -70.86961364746094, 114.45, 0, 0

03:19:13 PM, 43.20950698852539, -70.86961364746094, 114.48, 0, 0

03:19:13 PM, 43.209495544433594, -70.86962890625, 113.76, 0, 0

03:19:13 PM, 43.209495544433594, -70.86963653564453, 113.7, 0, 0

03:19:13 PM, 43.20950698852539, -70.86963653564453, 113.49, 0, 0

03:19:13 PM, 43.209495544433594, -70.86964416503906, 112.86, 0, 0

03:19:13 PM, 43.209449768066406, -70.86972045898438, 113.86, 0, 0

03:19:13 PM, 43.20943069458008, -70.86981201171875, 116.74, 0, 0

03:19:13 PM, 43.20942306518555, -70.86993408203125, 118.76, 0, 0

03:19:13 PM, 43.209434509277344, -70.87007141113281, 120.62, 0, 0

03:19:13 PM, 43.20954895019531, -70.87053680419922, 118.04, 0, 0

03:19:13 PM, 43.20954895019531, -70.87054443359375, 117.98, 0, 0

03:19:13 PM, 43.20954895019531, -70.87054443359375, 118.11, 0, 0

03:19:13 PM, 43.20954513549805, -70.87055206298828, 117.93, 0, 0

03:19:13 PM, 43.20953369140625, -70.87055969238281, 117.61, 0, 0

03:19:13 PM, 43.209537506103516, -70.87055206298828, 117.55, 0, 0

03:19:13 PM, 43.20953369140625, -70.87055206298828, 117.59, 0, 0

03:19:13 PM, 43.20953369140625, -70.87055206298828, 117.62, 0, 0

03:19:13 PM, 43.20953369140625, -70.87055206298828, 117.63, 0, 0

03:19:13 PM, 43.20953369140625, -70.87055206298828, 116.77, 0, 0

03:19:13 PM, 43.209529876708984, -70.87055969238281, 116.38, 0, 0

03:19:13 PM, 43.20952606201172, -70.87056732177734, 115.39, 0, 0

03:19:13 PM, 43.20953369140625, -70.87055969238281, 115.86, 0, 0

03:19:13 PM, 43.209529876708984, -70.87055969238281, 115.28, 0, 0

03:19:13 PM, 43.209529876708984, -70.87055969238281, 115.12, 0, 0

03:19:13 PM, 43.209529876708984, -70.87055969238281, 115.1, 0, 0

03:19:13 PM, 43.209529876708984, -70.87055206298828, 115.16, 0, 0

03:19:13 PM, 43.209529876708984, -70.87055206298828, 115.16, 0, 0

03:19:13 PM, 43.209529876708984, -70.87055206298828, 114.67, 0, 0

03:19:13 PM, 43.209529876708984, -70.87055206298828, 114.61, 0, 0

03:19:13 PM, 43.209529876708984, -70.87054443359375, 114.56, 0, 0

03:19:13 PM, 43.209529876708984, -70.87054443359375, 114.37, 0, 0

03:19:13 PM, 43.20952606201172, -70.87054443359375, 112.99, 0, 0

03:19:13 PM, 43.20952606201172, -70.87054443359375, 113.14, 0, 0

03:19:13 PM, 43.209537506103516, -70.87054443359375, 113.21, 0, 0

03:19:13 PM, 43.20954513549805, -70.87054443359375, 113.26, 0, 0

03:19:13 PM, 43.20954513549805, -70.87055206298828, 113.24, 0, 0

03:19:13 PM, 43.2096061706543, -70.87062072753906, 113.13, 0, 0

03:19:13 PM, 43.209716796875, -70.870849609375, 109.28, 0, 0

03:19:13 PM, 43.209815979003906, -70.87113952636719, 102.61, 0, 0

03:19:13 PM, 43.20994186401367, -70.87145233154297, 96.4, 0, 0

03:19:13 PM, 43.204952239990234, -70.87549591064453, 39.67, 0, 0

03:19:13 PM, 43.197731018066406, -70.87783813476562, 28.76, 0, 0

03:19:13 PM, 43.19785690307617, -70.87754821777344, 29.44, 0, 0

03:19:13 PM, 43.19789505004883, -70.8774185180664, 29.73, 0, 0

03:19:13 PM, 43.204017639160156, -70.87120819091797, 38.08, 0, 0

03:19:13 PM, 43.20500564575195, -70.87425994873047, 52.11, 0, 0

03:19:13 PM, 43.20512008666992, -70.87433624267578, 52.22, 0, 0

03:19:13 PM, 43.20505905151367, -70.87454986572266, 52.2, 0, 0

03:19:13 PM, 43.20509338378906, -70.87472534179688, 51.47, 0, 0

03:19:13 PM, 43.214290618896484, -70.87380981445312, 71.92, 0, 0

03:19:13 PM, 43.21426010131836, -70.87390899658203, 72, 0, 0

03:19:13 PM, 43.214263916015625, -70.87390899658203, 71.91, 0, 0

03:19:13 PM, 43.214263916015625, -70.8739013671875, 71.94, 0, 0

03:19:13 PM, 43.2105827331543, -70.87279510498047, 80.26, 0, 0

03:19:13 PM, 43.21054458618164, -70.87272644042969, 81.1, 0, 0

03:19:13 PM, 43.21044921875, -70.87248992919922, 85.54, 0, 0

03:19:13 PM, 43.210365295410156, -70.87230682373047, 89.83, 0, 0

03:19:13 PM, 43.2101936340332, -70.87200164794922, 100.19, 0, 0

03:19:13 PM, 43.21015930175781, -70.87191772460938, 102.55, 0, 0

03:19:13 PM, 43.210086822509766, -70.87181854248047, 103.75, 0, 0

03:19:13 PM, 43.210086822509766, -70.87167358398438, 105.19, 0, 0

03:19:13 PM, 43.21006774902344, -70.87158203125, 105.62, 0, 0

03:19:13 PM, 43.210025787353516, -70.8714828491211, 106.06, 0, 0

03:19:13 PM, 43.210018157958984, -70.87147521972656, 106.04, 0, 0

03:19:13 PM, 43.20982360839844, -70.87091064453125, 103.57, 0, 0

03:19:13 PM, 43.20981216430664, -70.87089538574219, 103.56, 0, 0

03:19:13 PM, 43.209693908691406, -70.87068176269531, 104.28, 0, 0

03:19:13 PM, 43.2095947265625, -70.87054443359375, 103.38, 0, 0

03:19:13 PM, 43.2095947265625, -70.87053680419922, 103.17, 0, 0

03:19:13 PM, 43.2095947265625, -70.87052917480469, 103.28, 0, 0

03:19:13 PM, 43.209590911865234, -70.87052917480469, 103.39, 0, 0

## 2024-08-09 – Call With Sam & Mark

Sam showed the script for the marketing video. Data is totally secondary but the real data is important to Mark and I. The production team is arriving Monday! Thursday Boston, Friday is NH.

## 2024-08-08 – Initial discussions with Mark Umina

Introduced Sam Ponedal who is Silabs marketing

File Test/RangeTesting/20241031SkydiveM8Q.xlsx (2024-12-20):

Time | Latitude | Longitude | Altitude | TxPower | RSSI | Thu Oct 31 2024 15:37:31 GMT-0400 (Eastern Daylight Time)
15:37:32 | 42.69444275 | -71.55289459 | 52.1 | 12 | -94
15:37:34 | 42.69444656 | -71.55286407 | 52.2 | 20 | -93
15:37:36 | 42.69445038 | -71.55283356 | 51.9 | 20 | -101
15:37:38 | 42.69445801 | -71.55281067 | 52.2 | 20 | -92
15:37:40 | 42.69445801 | -71.55278778 | 51.8 | 20 | -90
15:37:42 | 42.69445038 | -71.55277252 | 51 | 16 | -91
15:37:44 | 42.69443512 | -71.55275726 | 50.3 | 17 | -91
15:37:46 | 42.69441986 | -71.552742 | 50 | 17 | -91
15:37:48 | 42.69440842 | -71.55272675 | 50 | 20 | -103
15:37:50 | 42.6944046 | -71.55272675 | 50.2 | 20 | -102
15:37:52 | 42.6944046 | -71.55271912 | 50.8 | 20 | -96
15:37:54 | 42.6944046 | -71.55271149 | 50.5 | 18 | -92
15:37:56 | 42.69440079 | -71.55271149 | 51 | 18 | -91
15:37:58 | 42.69440079 | -71.55270386 | 51.4 | 19 | -90
15:38:00 | 42.69440079 | -71.55269623 | 51.7 | 17 | -94
15:38:03 | 42.69439697 | -71.55269623 | 52.2 | 20 | -100
15:38:05 | 42.69439316 | -71.5526886 | 52.3 | 20 | -92
15:38:07 | 42.69439316 | -71.5526886 | 51.9 | 17 | -98
15:38:09 | 42.69439316 | -71.5526886 | 52 | 20 | -100
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

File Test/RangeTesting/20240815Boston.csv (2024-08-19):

Time | Latitude | Longitude | Altitude | TxPower | RSSI | Fri Aug 16 2024 08:00:26 GMT-0400 (Eastern Daylight Time)
08:00:26 AM | 42.34858703613281 | -71.05084991455078 | 33.46 | -6 | -54
08:00:26 AM | 42.34858703613281 | -71.05084991455078 | 33.49 | -6 | -54
08:00:26 AM | 42.34858703613281 | -71.05084991455078 | 33.46 | -3 | -52
08:00:26 AM | 42.34859085083008 | -71.05084991455078 | 33.56 | -6 | -54
08:00:26 AM | 42.34859085083008 | -71.05084991455078 | 33.59 | -6 | -54
08:00:26 AM | 42.34859085083008 | -71.05084991455078 | 33.43 | -6 | -53
08:00:26 AM | 42.34859085083008 | -71.05084991455078 | 33.44 | -6 | -54
08:00:26 AM | 42.34859085083008 | -71.05084991455078 | 33.5 | -6 | -55
08:00:26 AM | 42.34859085083008 | -71.05084991455078 | 33.5 | -6 | -55
08:00:26 AM | 42.34859085083008 | -71.05084991455078 | 33.43 | -6 | -54
08:00:26 AM | 42.34859085083008 | -71.05084991455078 | 33.26 | -6 | -54
08:00:26 AM | 42.34859085083008 | -71.05084991455078 | 33.25 | -6 | -54
08:00:26 AM | 42.34859085083008 | -71.05084991455078 | 33.27 | -6 | -54
08:00:26 AM | 42.34859085083008 | -71.05084991455078 | 33.18 | -6 | -54
08:00:26 AM | 42.34859085083008 | -71.05084991455078 | 33.46 | -6 | -55
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

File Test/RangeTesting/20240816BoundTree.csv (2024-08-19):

Time | Latitude | Longitude | Altitude | TxPower | RSSI | Fri Aug 16 2024 15:56:10 GMT-0400 (Eastern Daylight Time)
03:56:10 PM | 43.207969665527344 | -71.77096557617188 | 164.82 | -6 | -52
03:56:10 PM | 43.207969665527344 | -71.77096557617188 | 164.88 | -6 | -52
03:56:10 PM | 43.207969665527344 | -71.77096557617188 | 164.85 | -6 | -52
03:56:10 PM | 43.207969665527344 | -71.77096557617188 | 164.86 | -6 | -52
03:56:10 PM | 43.207969665527344 | -71.77096557617188 | 164.85 | -6 | -52
03:56:10 PM | 43.207969665527344 | -71.77096557617188 | 164.85 | -6 | -52
03:56:10 PM | 43.207969665527344 | -71.77095794677734 | 164.83 | -6 | -52
03:56:10 PM | 43.207969665527344 | -71.77095794677734 | 164.83 | -6 | -52
03:56:10 PM | 43.207969665527344 | -71.77095794677734 | 164.88 | -6 | -53
03:56:10 PM | 43.207969665527344 | -71.77095794677734 | 164.9 | -6 | -52
03:56:10 PM | 43.207969665527344 | -71.77095794677734 | 164.87 | -6 | -52
03:56:10 PM | 43.207969665527344 | -71.77095794677734 | 164.9 | -6 | -54
03:56:10 PM | 43.207969665527344 | -71.77095794677734 | 164.73 | -6 | -53
03:56:10 PM | 43.207969665527344 | -71.77095794677734 | 164.74 | -6 | -54
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

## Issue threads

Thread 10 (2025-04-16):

ZRADTri Rev A PCB issues

drzwave, 2025-04-16:
1. C16 is an 0603 instead of 0805 (schematic has been fixed but not layout)
2. Add Hardware version resistor divider
3.

drzwave, 2025-04-22:
The RGB LED in the BOM is unavailable - QLSP14RGB_B
I replaced it with [ASMB-KTF0-0A306](https://www.digikey.com/en/products/detail/broadcom-limited/ASMB-KTF0-0A306/7915692) which isn't as bright.
Seems that the 3.2x2.88mm are much more common:
[BL-HJXGXBX32M-D](https://www.digikey.com/en/products/detail/american-bright-optoelectronics-corporation/BL-HJXGXBX32M-D/9678116)
[CLV1L-FKB-CJQRNQEFGBB79353](https://www.digikey.com/en/products/detail/cree-led/CLV1L-FKB-CJQRNQEFGBB79353/9659628)

drzwave, 2025-05-13:
PCB is working but the wrong crystal so the baud rate and RF are wrong. Replacement parts ordered.

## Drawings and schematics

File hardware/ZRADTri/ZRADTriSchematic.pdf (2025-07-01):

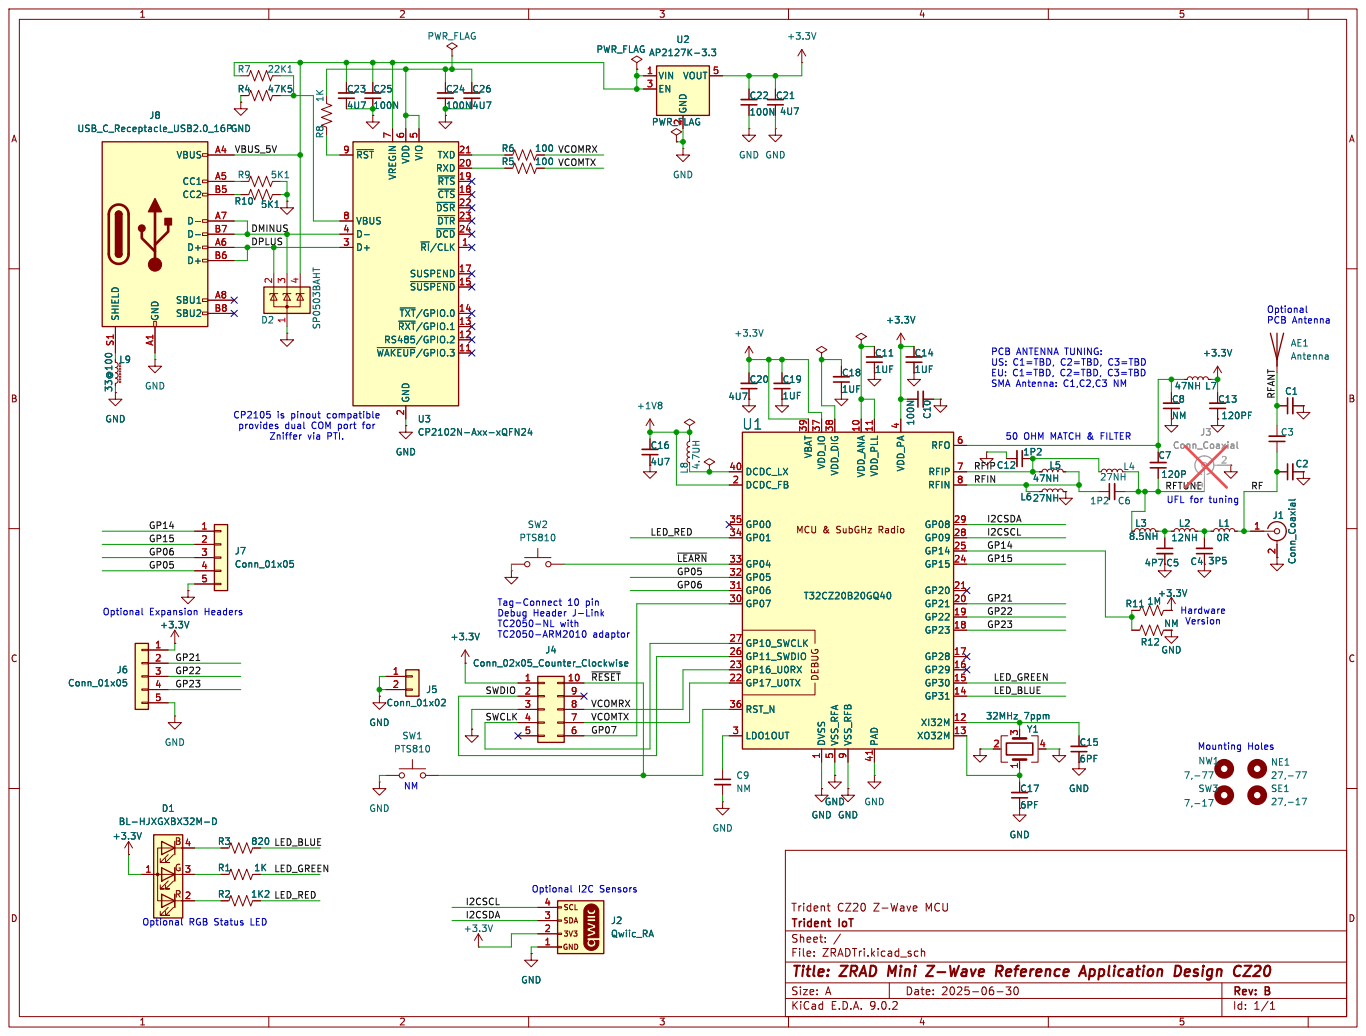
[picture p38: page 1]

5 TXD 21 RXD 20 ~{RTS} 19 ~{CTS} 18 ~{DSR} 22 ~{DTR} 23 ~{DCD} 24 ~{RI}/CLK1 SUSPEND 17 ~{SUSPEND}15 ~{TXT}/GPIO.014 ~{RXT}/GPIO.113 RS485/GPIO.2 12 ~{WAKEUP}/GPIO.311 R6 100 R5 100 C26

5 TXD 21 RXD 20 ~{RTS} 19 ~{CTS} 18 ~{DSR} 22 ~{DTR} 23 ~{DCD} 24 ~{RI}/CLK1 SUSPEND 17 ~{SUSPEND}15 ~{TXT}/GPIO.014 ~{RXT}/GPIO.113 RS485/GPIO.2 12 ~{WAKEUP}/GPIO.311 U3 CP2102N-Axx-xQFN24 C10 100N

Optional PCB Antenna Mounting Holes

4 RFO 6 RFIP 7 RFIN 8 GP08 29 GP09 28 GP14 25 GP15 24 GP20 21 GP21 20 GP22 19 GP23 18 GP28 17 GP29 16 GP30 15 GP31 14 XI32M 12 XO32M 13 GND

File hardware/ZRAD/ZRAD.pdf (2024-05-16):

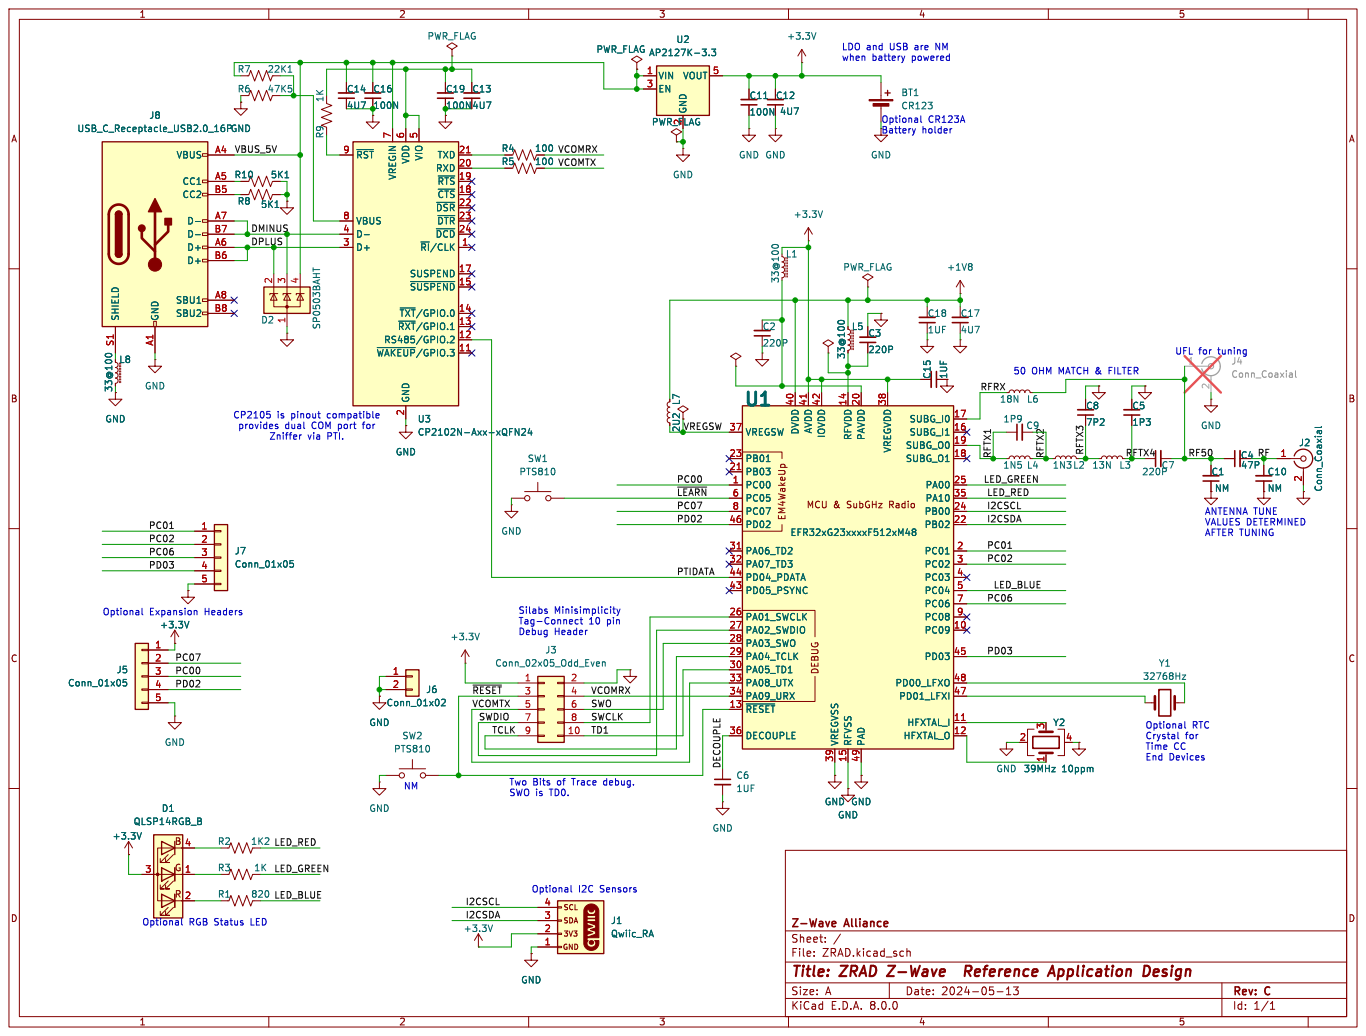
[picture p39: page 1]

LDO and USB are NM
when battery powered

2 RXD 20 TXD 21 ~{DSR} 22 ~{DTR} 23 ~{DCD} 24 D+ 3 D- 4 VIO

UFL for tuning Silabs Minisimplicity

End Devices ANTENNA TUNE

Crystal for Time CC

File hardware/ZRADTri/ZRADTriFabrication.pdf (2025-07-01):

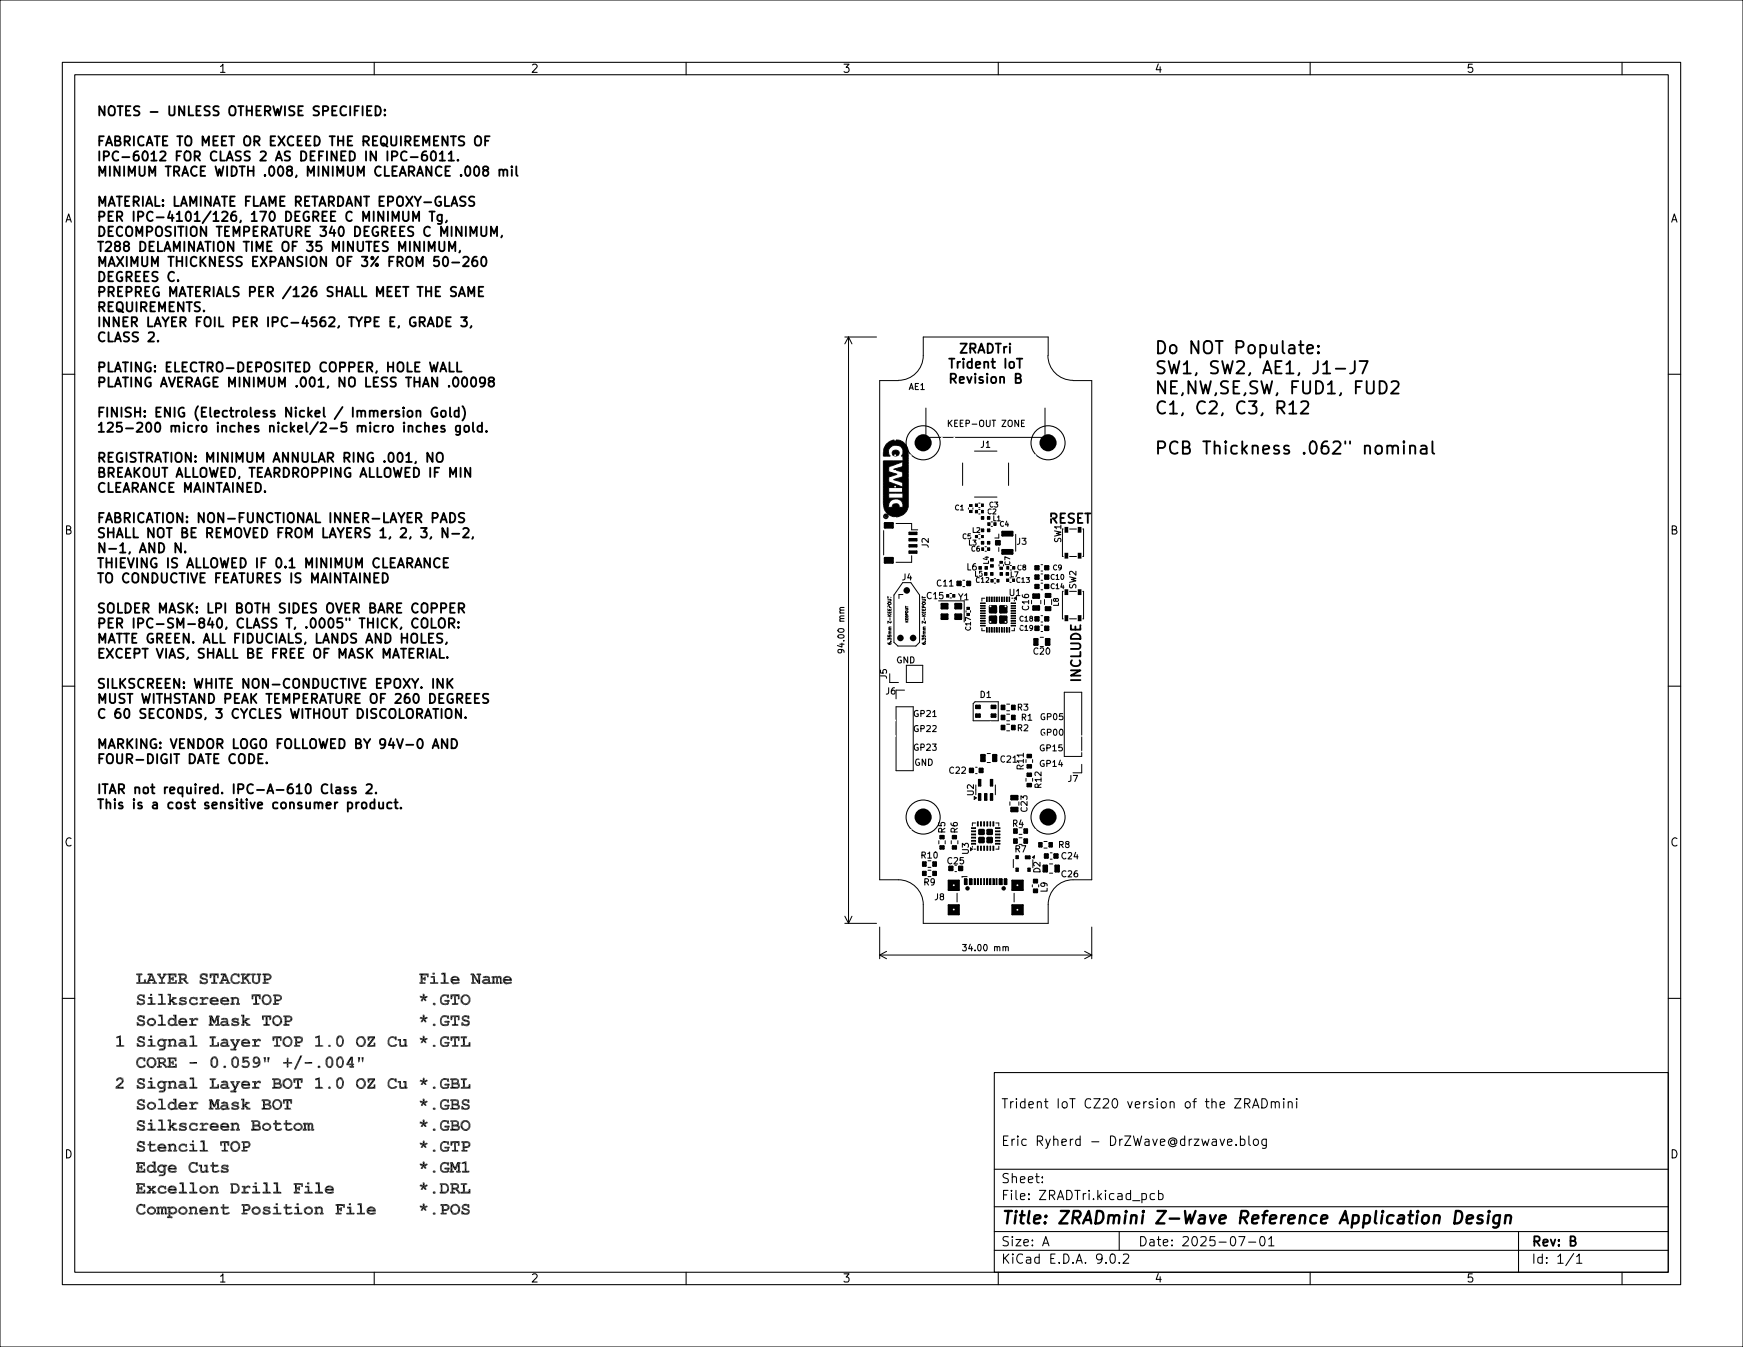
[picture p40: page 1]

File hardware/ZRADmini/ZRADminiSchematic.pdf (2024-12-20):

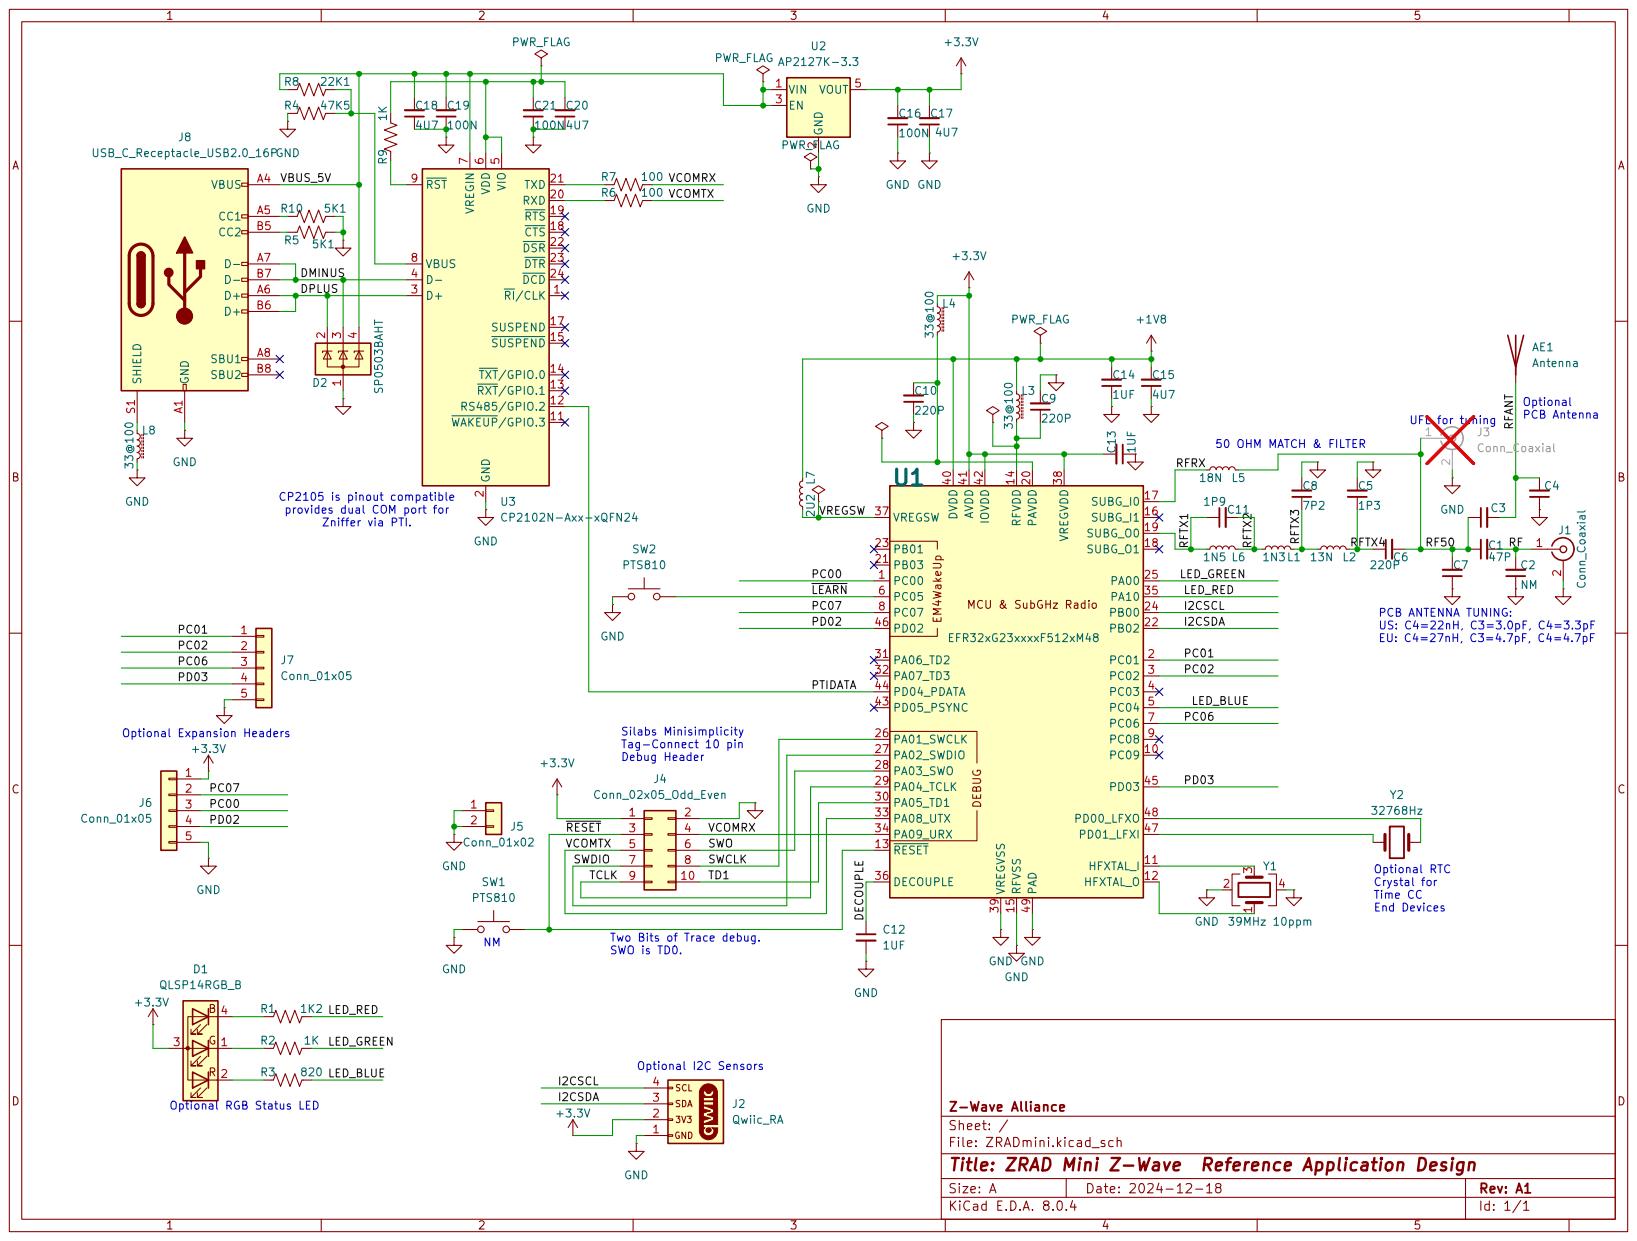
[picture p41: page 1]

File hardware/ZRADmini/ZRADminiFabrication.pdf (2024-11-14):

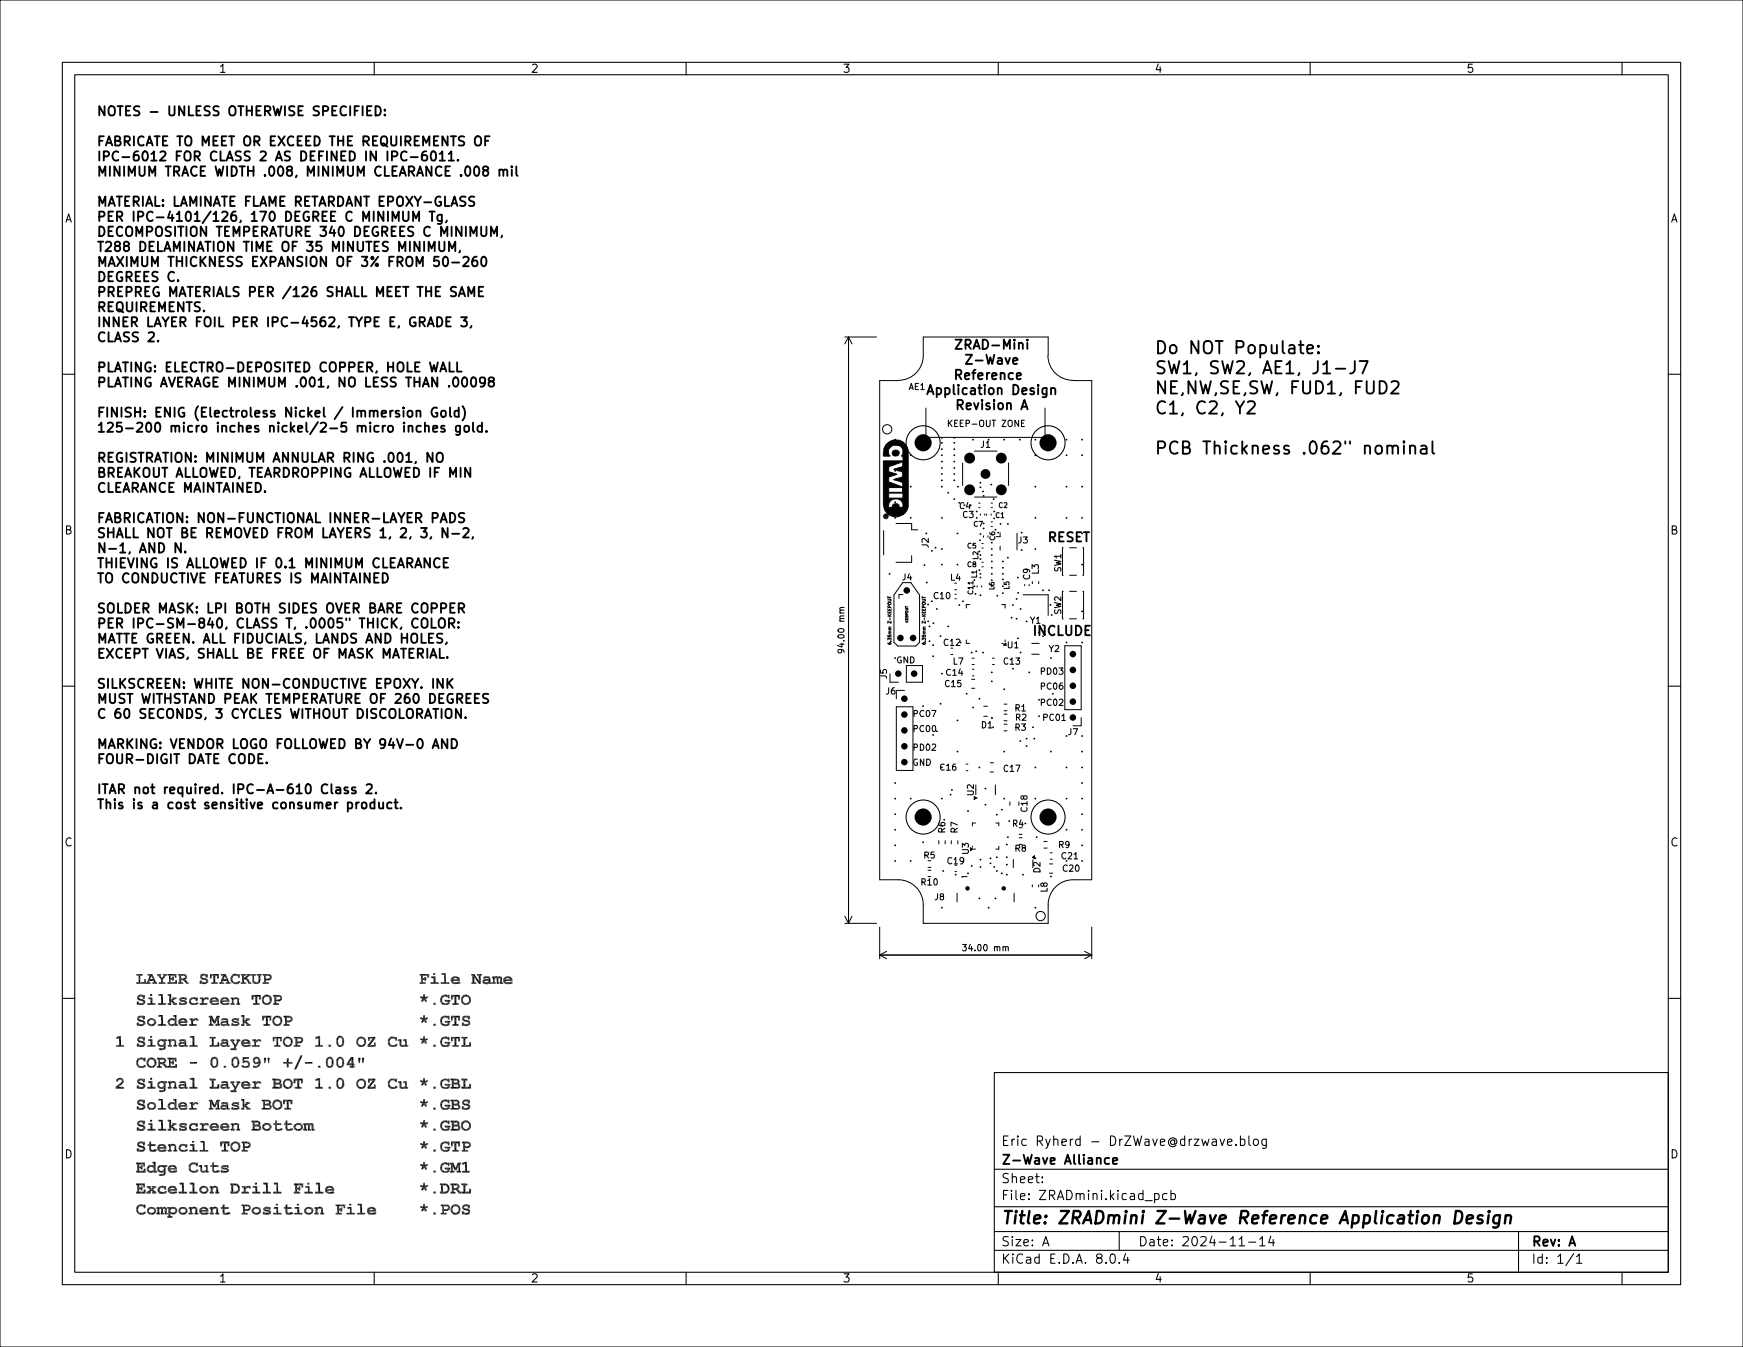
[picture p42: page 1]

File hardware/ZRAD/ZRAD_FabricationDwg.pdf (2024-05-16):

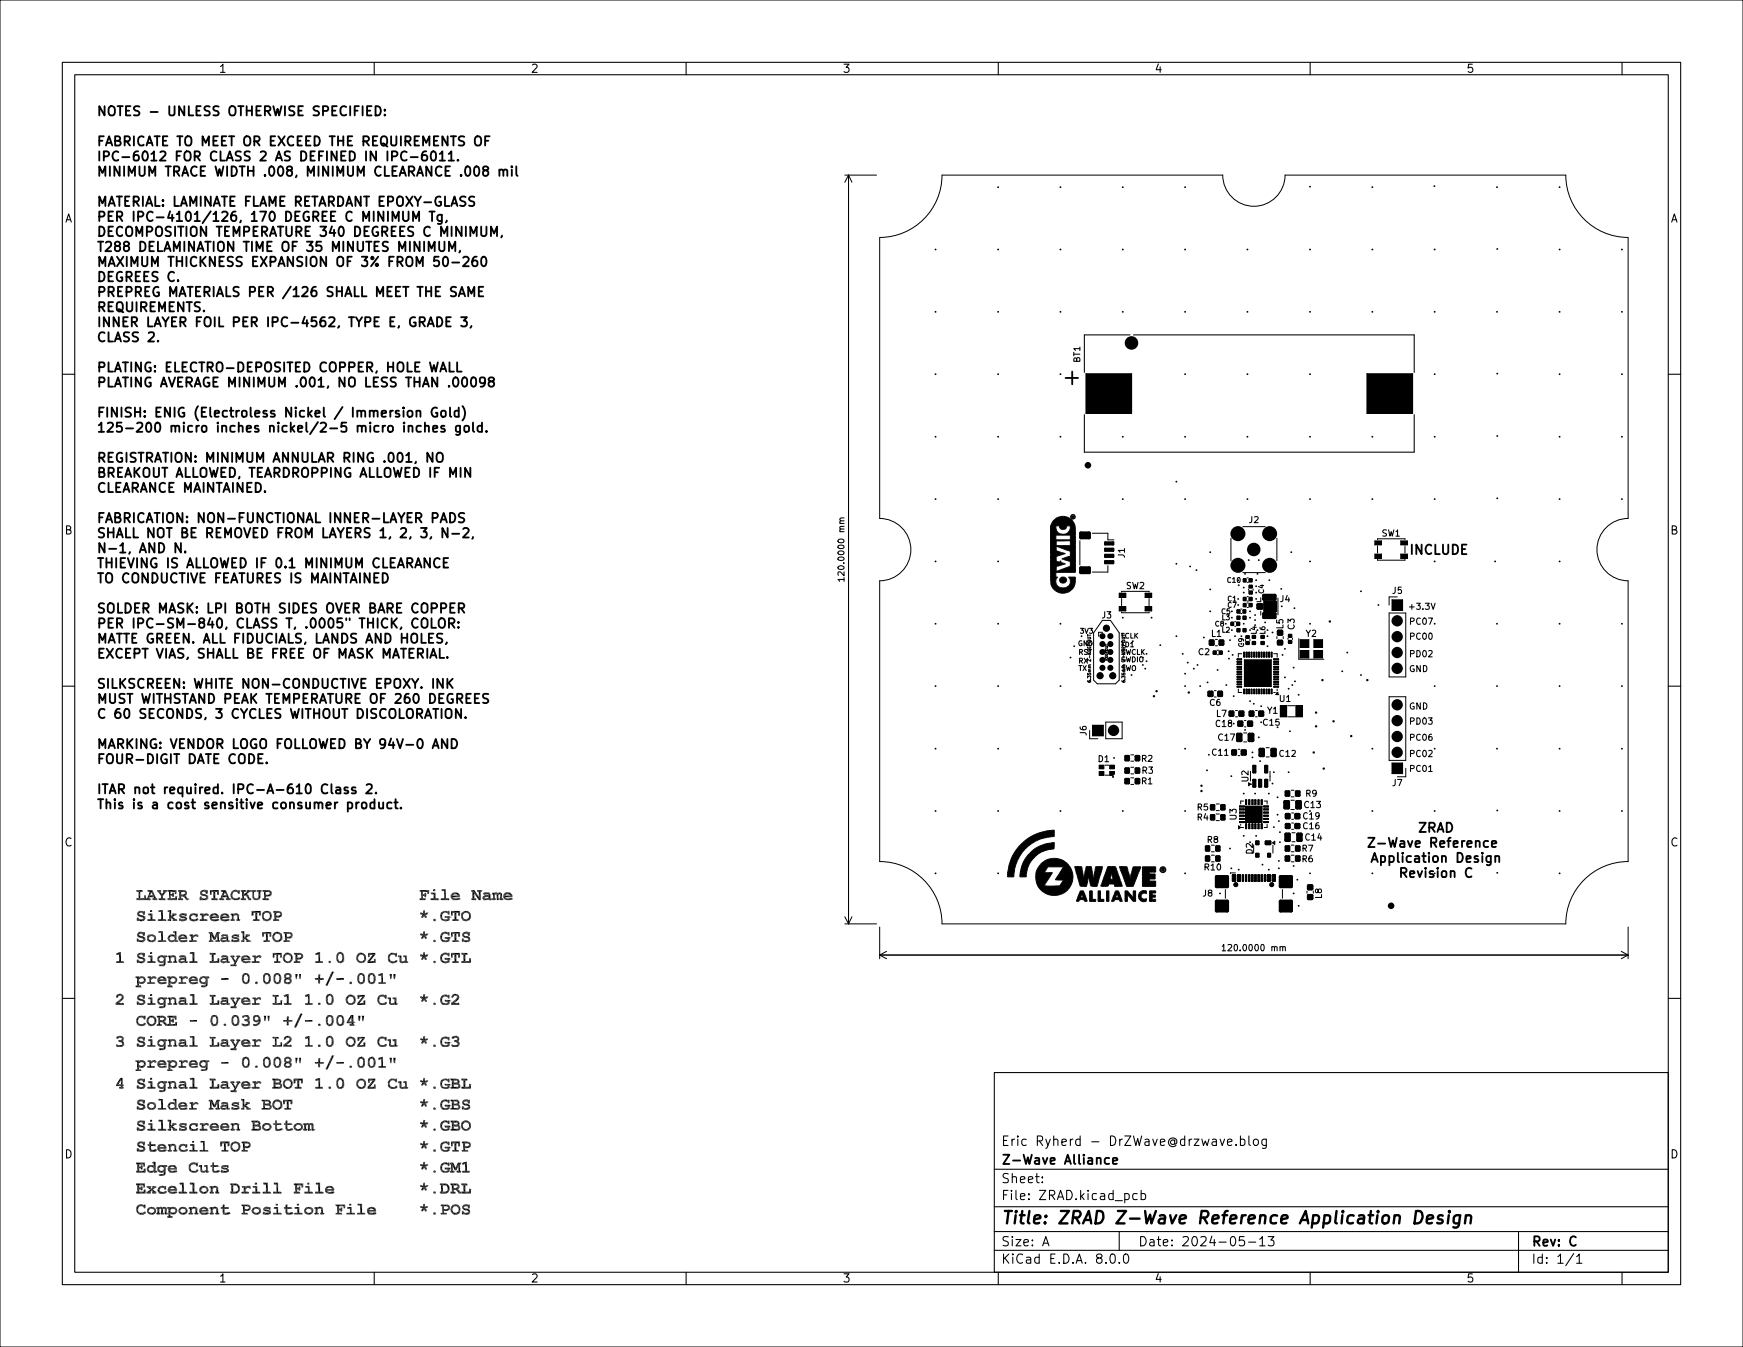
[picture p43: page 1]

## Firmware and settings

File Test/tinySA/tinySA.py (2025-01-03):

#!/usr/bin/env python3
import serial
import numpy as np
import pylab as pl
import struct
from serial.tools import list_ports

# These are generic ST USB->UART chip VID/PID so they are not certain to find the proper device
VID = 0x0483 #1155
PID = 0x5740 #22336

# Get tinysa device automatically
def getport() -> str:
    device_list = list_ports.comports()
    for device in device_list:
        if device.vid == VID and device.pid == PID:
            return device.device
    raise OSError("device not found")

REF_LEVEL = (1<<9)

class tinySA:
    def __init__(self, dev = None):
        self.dev = dev or getport()
        self.serial = None
        self._frequencies = None
        self.points = 101
        
    @property
    def frequencies(self):
        return self._frequencies

    def set_frequencies(self, start = 1e6, stop = 350e6, points = None):
        if points:
            self.points = points
        self._frequencies = np.linspace(start, stop, self.points)

    def open(self):
        if self.serial is None:
            self.serial = serial.Serial(self.dev)

    def close(self):
        if self.serial:
            self.serial.close()
        self.serial = None

    def send_command(self, cmd):
        self.open()
        self.serial.write(cmd.encode())
        self.serial.readline() # discard empty line
#        print(self.serial.readline()) # discard empty line

    def cmd(self, text):
        self.open()
        self.serial.write((text + "\r").encode())
        self.serial.readline() # discard empty line
        data = self.fetch_data()
        return data
#        self.serial.readline() # discard empty line

    def set_sweep(self, start, stop):
        if start is not None:
            self.send_command("sweep start %d\r" % start)
        if stop is not None:
            self.send_command("sweep stop %d\r" % stop)

    def set_span(self, span):
        if span is not None:
            self.send_command("sweep span %d\r" % span)

    def set_center(self, center):
        if center is not None:
            self.send_command("sweep center %d\r" % center)

    def set_level(self, level):
        if level is not None:
            self.send_command("level %d\r" % level)

    def set_output(self, on):
        if on is not None:
            if on:
                self.send_command("output on\r")
            else:
                self.send_command("output off\r")

    def set_low_output(self):
        self.send_command("mode low output\r")

    def set_low_input(self):           
        self.send_command("mode low input\r")
    
    def set_high_input(self):           
        self.send_command("mode high input\r")
    
    def set_frequency(self, freq):
        if freq is not None:
            self.send_command("freq %d\r" % freq)

    def measure(self, freq):
        if freq is not None:
            self.send_command("hop %d 2\r" % freq)
            data = self.fetch_data()
            for line in data.split('\n'):
                if line:
                    return float(line)

    def temperature(self):
        self.send_command("k\r")
        data = self.fetch_data()
        for line in data.split('\n'):
            if line:
                return float(line)

    def rbw(self, data=0):
        if data == 0:
            self.send_command("rbw auto\r")
            return
        if data<1:
            self.send_command("rbw %f\r" % data)
            return
        if data >= 1:
            self.send_command("rbw %d\r" % data)
        
    def fetch_data(self):
        result = ''
        line = ''
        while True:
            c = self.serial.read().decode('utf-8')
            if c == chr(13):
                next # ignore CR
            line += c
            if c == chr(10):
                result += line
                line = ''
                next
            if line.endswith('ch>'):
                # stop on prompt
                break
        return result

#    def fetch_array(self, sel):
#        self.send_command("data %d\r" % sel)
#        data = self.fetch_data()
#        x = []
#        for line in data.split('\n'):
#            if line:
#                x.extend([float(d) for d in line.strip().split(' ')])
#        return np.array(x[0::2]) + np.array(x[1::2]) * 1j

#    def fetch_gamma(self, freq = None):
#        if freq:
#            self.set_frequency(freq)
#        self.send_command("gamma\r")
#        data = self.serial.readline()
#        d = data.strip().split(' ')
#        return (int(d[0])+int(d[1])*1.j)/REF_LEVEL

    def resume(self):
        self.send_command("resume\r")
    
    def pause(self):
        self.send_command("pause\r")
    
    def marker_value(self, nr = 1):
        self.send_command("marker %d\r" % nr)
        data = self.fetch_data()
        line = data.split('\n')[0]
#        print(line)
        if line:
            dl = line.strip().split(' ')
            if len(dl) >= 4:
                d = line.strip().split(' ')[3]
                return float(d)
        return 0

    def fetch_marker(self, nr = 1):
        ''' Return a list of [Frequency, value] or None'''
        self.send_command("marker %d\r" % nr)
        data = self.fetch_data()
        line = data.split('\n')[0]
#        print(line)
        if line:
            dl = line.strip().split(' ')
            if len(dl) >= 4:
                freq = line.strip().split(' ')[2]
                val = line.strip().split(' ')[3]
                try:
                    return [float(freq), float(val)]
                except:
                    pass
        return None

    def data(self, array = 2):
        self.send_command("data %d\r" % array)
        data = self.fetch_data()
        x = []
        for line in data.split('\n'):
            if line:
                d = line.strip().split(' ')
                x.append(float(line))
        return np.array(x)

    def fetch_frequencies(self):
        self.send_command("frequencies\r")
        data = self.fetch_data()
        x = []
        for line in data.split('\n'):
            if line:
                x.append(float(line))
        self._frequencies = np.array(x)

    def send_scan(self, start = 1e6, stop = 900e6, points = None):
        if points:
            self.send_command("scan %d %d %d\r"%(start, stop, points))
        else:
            self.send_command("scan %d %d\r"%(start, stop))

    def scan(self):
        segment_length = 101
        array0 = []
        array1 = []
        if self._frequencies is None:
            self.fetch_frequencies()
        freqs = self._frequencies
        while len(freqs) > 0:
            seg_start = freqs[0]
            seg_stop = freqs[segment_length-1] if len(freqs) >= segment_length else freqs[-1]
            length = segment_length if len(freqs) >= segment_length else len(freqs)
            #print((seg_start, seg_stop, length))
            self.send_scan(seg_start, seg_stop, length)
            array0.extend(self.data(0))
            array1.extend(self.data(1))
            freqs = freqs[segment_length:]
        self.resume()
        return (array0, array1)
    
    def capture(self):
        from PIL import Image
        self.send_command("capture\r")
        b = self.serial.read(320 * 240 * 2)
        x = struct.unpack(">76800H", b)
        # convert pixel format from 565(RGB) to 8888(RGBA)
        arr = np.array(x, dtype=np.uint32)
        arr = 0xFF000000 + ((arr & 0xF800) >> 8) + ((arr & 0x07E0) << 5) + ((arr & 0x001F) << 19)
        return Image.frombuffer('RGBA', (320, 240), arr, 'raw', 'RGBA', 0, 1)

    def logmag(self, x):
        pl.grid(True)
        pl.xlim(self.frequencies[0], self.frequencies[-1])
        pl.plot(self.frequencies, x)
        
    def writeCSV(self,x,name):
        f = open(opt.save, "w")
        for i in range(len(x)):
            print("%d, "%self.frequencies[i], "%2.2f"%x[i], file=f)


if __name__ == '__main__':
    from optparse import OptionParser
    parser = OptionParser(usage="%prog: [options]")
    parser.add_option("-p", "--plot", dest="plot",
                      action="store_true", default=False,
                      help="plot rectanglar", metavar="PLOT")
    parser.add_option("-c", "--scan", dest="scan",
                      action="store_true", default=False,
                      help="scan by script", metavar="SCAN")
    parser.add_option("-S", "--start", dest="start",
                      type="float", default=1e6,
                      help="start frequency", metavar="START")
    parser.add_option("-E", "--stop", dest="stop",
                      type="float", default=900e6,
                      help="stop frequency", metavar="STOP")
    parser.add_option("-N", "--points", dest="points",
                      type="int", default=101,
                      help="scan points", metavar="POINTS")
    parser.add_option("-P", "--port", type="int", dest="port",
                      help="port", metavar="PORT")
    parser.add_option("-d", "--dev", dest="device",
                      help="device node", metavar="DEV")
    parser.add_option("-v", "--verbose",
                      action="store_true", dest="verbose", default=False,
                      help="verbose output")
    parser.add_option("-C", "--capture", dest="capture",
                      help="capture current display to FILE", metavar="FILE")
    parser.add_option("-e", dest="command", action="append",
                      help="send raw command", metavar="COMMAND")
    parser.add_option("-o", dest="save",
                      help="write CSV file", metavar="SAVE")
    (opt, args) = parser.parse_args()

    nv = tinySA(opt.device or getport())

    if opt.command:
        print(opt.command)
        for c in opt.command:
            nv.send_command(c + "\r")
        data = nv.fetch_data()
        print(data)

    if opt.capture:
        print("capturing...")
        img = nv.capture()
        img.save(opt.capture)
        exit(0)

 #   nv.set_port(opt.port)
    if opt.start or opt.stop or opt.points:
        nv.set_frequencies(opt.start, opt.stop, opt.points)
#    plot = opt.plot 
    if opt.plot or opt.save or opt.scan:
        p = int(opt.port) if opt.port else 0
        if opt.scan or opt.points > 101:
            s = nv.scan()
            s = s[p]
        else:
            if opt.start or opt.stop:
                nv.set_sweep(opt.start, opt.stop)
            nv.fetch_frequencies()
            s = nv.data(p)
#            nv.fetch_frequencies()
    if opt.save:
        nv.writeCSV(s,opt.save)
    if opt.plot:
        nv.logmag(s)
        pl.show()

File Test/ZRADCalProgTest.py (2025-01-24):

#!/usr/bin/env python3
''' Z-Wave Alliance ZRADMini calibrate, program, test and print the QR code python script
    A Zebra label printer must be connected to the computer this program is run on
    A Zebra ZD411-300dpi is recommended. Do NOT use a 203dpi as it does not have sufficient resolution.

    Typically two DUTs are tested at a time. 
    One is being programmed/tested while the operator inserts the next DUT into the other jig.
    A command line is visible to the operator to issue commands.
    Typically they just press enter when the next DUT is ready and a PASS/FAIL is printed along with a QR code label.

    Recommendation is to call this script with a shell that assigns LCOM, RCOM, LSER and RSER.

    Several of the variables just below here may need to be customized for a specific test station.

    Steps:
    1) The SE version is checked that it matches the expected value or is upgraded 
    2) If CTUNE has not been set, then the crystal is calibrated
    3) Flash application 
    4) Run a quick functional test
    5) Print the QR code labels
    6) Display pass/fail to the screen and wait for the operator to insert the next DUT
    
    TODO - add a test for the USB data interface as there have been several board with a manufacturing defect in the USB circuitry
        Requires the operator plug in a USB cable. 
        Better solution would be test pads on the 2 USB data pins (and +5V/GND).
'''

import serial
import time
import sys, os, subprocess
import traceback
from packaging import version   # for comparing version numbers
from SmartStartQR import *
from serial.tools import list_ports
from PIL import Image
import ZG23CrystalCal
import zpl        # Zebra ZPL creation library - convert the PNG to ZPL
import zebra      # Zebra label printer library - send the ZPL code to the printer

# These 2 values are the minimum and maximum expected current measurements in milliAmps of the DUT using the WSTK AEM
# They have be derived empircally and may need future adjustments - TODO - need more testing here!!!
CURRENT_MIN = 5.0
CURRENT_MAX = 10.0

DEBUG = 5   # print debug messages - the higher the value, the more details are printed

# USB IDs for a WSTK to open the serial port to RailTest
WSTK_VID = 0x1366
WSTK_PID =  0x0105

APPLICATION_FILENAME = "../Software/ZRAD_ED_merged.s37"
RAILTEST_FILENAME = "../Software/railtest_ZG23_442.s37"

# The Secure Engine in the EFR32xG23 must match the application SSDK version!
# See AN1222 Production Programming of Series 2 Devices for more details.
# The .SEU file is only used if secure boot is enabled otherwise the .hex file is used.
# Copy the file from: C:\Users\<username>\SimplicityStudio\SDKs\<GDSK40203>\util\se_release\public
EXPECTED_SE_VERSION = "2.2.6"
SECURE_ENGINE_FILENAME = "../Software/s2c3_se_fw_upgrade_app_2v2p6.hex"

# path and executable to silabs commander
CMDR = "C:/SiliconLabs/SimplicityStudio/v5/developer/adapter_packs/commander/commander.exe"

# for debugging - skip the label printing when True, normally False
#SKIP_PRINTING = True
SKIP_PRINTING = False

class ZRADCalProgTest:
    ''' Top level python script for testing the ZRADMini '''

    def __init__(self):
        self.wstk = ["COM4", None]  # typically 2 WSTKs are used to test one while the other is being clamped into the jig
        self.wstkser = ["440263534", "456"]
        try:
            for i in sys.argv:
                if "LCOM" in i:                     # See USAGE for details
                    self.wstk[0] = i.split('=')[1]
                elif "RCOM" in i:
                    self.wstk[1] = i.split('=')[1]
                elif "LSER" in i:
                    self.wstkser[0] = i.split('=')[1]
                elif "RSER" in i:
                    self.wstkser[1] = i.split('=')[1]
            self.wcom=None
        except Exception as err:
            print("failed to open devices:",err)
            traceback.print_tb(err.__traceback__)
            exit()
        
    @property

    def openwcom(self):
        if self.wcom is None:
            try:
                self.wcom = serial.Serial(self.wstk[self.side], timeout=3)
            except:
                print("Unable to open WSTK COM port")
                exit()

    def closewcom(self):
        if self.wcom:
            self.wcom.close()
        self.wcom = None

    def GetSEFirmwareVersion(self):
        ''' Return the version of the Secure Engine in the EFR32 chip as a Bytes array Ex: "2.1.0" '''
        rtn=subprocess.check_output(CMDR + " security status -d EFR32ZG23 --s {}".format(self.wstkser[self.side]),shell=True)
        if "SE Firmware" not in rtn.decode():
            print("SE firmware version get failed:\n\r{}\n\r".format(rtn))
            return(False)
        seVer = rtn.decode().split('\r')
        seVer2 = seVer[0].split(' ')[-1]
        for i in seVer:                 # if the DUT is locked, unlock it which also resets to factory fresh
            if "Debug lock" in i:
                if DEBUG>6: print("DUT locked - unlocking") 
                if "Enabled" in i:
                    self.FactoryFresh()
                break
        return(seVer2)

    def ProgramSecureEngine(self):
        ''' Check the SE version and update if out of date 
            Returns True if OK, False if it fails
        '''
        startSEupdate = time.time()
        seVer2=self.GetSEFirmwareVersion()
        if version.parse(EXPECTED_SE_VERSION) > version.parse(seVer2): # SE needs to be updated
            if DEBUG>4: print("Updating SE firmware from {} to {}".format(seVer2,EXPECTED_SE_VERSION))
            rtn=subprocess.check_output(CMDR + " flash --masserase -d EFR32ZG23 {} --s {}".format(SECURE_ENGINE_FILENAME,self.wstkser[self.side]),shell=True)
            time.sleep(2) # Per the AN1222 App note, wait 2s for the SE to update flash and boot
            seVer2=self.GetSEFirmwareVersion()
            if seVer2==False or version.parse(EXPECTED_SE_VERSION) != version.parse(seVer2):
                print("FAILED to update SE version")
                return(False)
            if DEBUG>4: print("SE firmware updated in {}s".format(time.time() - startSEupdate))
        elif version.parse(EXPECTED_SE_VERSION) != version.parse(seVer2):
            if DEBUG>2:print("***NOTE*** SE version is NEWER {} than the expected version {}. The application firmware may need to be updated!".format(seVer2,EXPECTED_SE_VERSION))
        else:    # if the SE version is the expected version, then keep going
            if DEBUG>4:print("SE has the expected version {}".format(seVer2))
        return(True)
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

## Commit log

2024-02-07 initial checkin
    [ZReach.kicad_pcb, ZReach.kicad_sch]
2024-02-16 Initial schematic and Tech Doc checkin
    [ZReach.kicad_sch, ZReachBOM.xlsx]
2024-02-20 started ERC checking
    [ZReach.kicad_sch]
2024-02-21 Schematic complete. PCB started.
    [ZReach.kicad_pcb, ZReach.kicad_sch]
2024-02-22 PCB Layout DRC clean but needs more cleanup
    [ZReach.kicad_pcb, ZReach.kicad_sch]
2024-02-23 Rev A PCB released for fabrication
    [ZReach.kicad_pcb]
2024-02-26 Update ZG23 symbol to the official one in the KiCAD library. Updated to KiCAD to V8.0
    [ZReach.kicad_sch]
2024-03-03 Ordered components for initial build
    [ZReach.kicad_sch, ZReachBOM.xlsx]
2024-03-18 Rev B PCB release
    [ZReach.kicad_pcb, ZReach.kicad_sch, ZReachBOM.xlsx]
2024-03-29 Rev B PCB initial debug
    [ZReachBOM.xlsx]
2024-04-07 Added antenna testing details
2024-04-13 updated instructions on setting up the LEDs and Buttons
2024-04-15 updated instructions on implementing I2C
2024-04-19 added details on Railest
    [ZRADBOM.xlsx]
2024-04-27 Add RF range test data and update data sheet
    [ZRADBOM.xlsx, ZReach.kicad_pcb, ZReach.kicad_sch]
2024-05-13 Renamed to ZRAD from ZReach
    [ZRAD.kicad_pcb, ZRAD.kicad_sch]
2024-05-16 Rev C PCB release - fix the Trace pins and battery holder, add PTI pin for CP2105
    [ZRAD.kicad_pcb, ZRAD.kicad_sch]
2024-06-07 Rev C PCB debugged and working
2024-06-12 Rev 1.0 public release - hardware is complete
    [ZRADBOM.xlsx]
2024-08-13 add Shaw Fields RF Range Data
    [202408ShawFields.csv]
2024-08-19 Fix time not incrementing in index.js. Add Boston and Boundtree data
    [20240815Boston.csv, 20240816BoundTree.csv, 202408ShawFields.csv]
2024-11-14 Added ZRADmini - a smaller lower cost ZRAD
    [ZRADmini.kicad_pcb, ZRADmini.kicad_sch]
2024-12-20 add RF Range test data and 3D programming jig
    [20241031SkydiveM8Q.xlsx, ZRADMiniJig.skp, ZRADmini.kicad_sch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]
2025-01-03 Begin adding testing scripts and sample software
    [ZRADMiniJig.skp, ZRADMiniJig.stl, ZRADmini.kicad_pcb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]
2025-01-27 switch to EU_LR
2025-01-27 rework to handle multiple test devices
2025-01-30 added info on creating heat maps and running GeoLoc in ZWJS
2025-01-30 fix: don't crash when powerlevel cannot be read
2025-04-11 add ZRADTri schematic
    [ZRADTri.kicad_sch]
2025-04-14 initial Trident PCB layout
    [ZRADTri.kicad_pcb, ZRADTri.kicad_sch]
2025-04-15 ZRADTri Trident IoT PCB rev A complete
    [ZRADTri.kicad_pcb, ZRADTri.kicad_sch]
2025-05-13 Updated ZRADTri BOM and schematic with minor changes for Rev A
    [ZRADTri.kicad_sch, ZRADTriBOM.xlsx]
2025-07-01 release ZRADTri Rev B
    [ZRADBaseDrillJig.stl, ZRADTopDrillJig.stl, ZRADTri.kicad_pcb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]
2025-10-23 Update Range testing and add 3D enclosure for ZRAD
    [ZRAD.stl]
2026-07-28 range testing and build ZRADmini boards 7&8
